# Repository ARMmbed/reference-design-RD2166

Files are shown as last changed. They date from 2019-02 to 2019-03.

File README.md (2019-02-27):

# RD2166 Introduction:

The RD2166 Reference Design is a Pelion Ready design based on the Quectel BG96 cellular module and the STM32L475 Microcontroller.

The reference design is a tested and proven starting point targetted towards the creation of both Development Boards and End Products.

# Reference Design Contents:
**Reference Schematic** 
This is the core of reference design, and illustrates where and how the essential components are connected. 

**Reference Application**
Built on mbedOS, and includes Pelion Device Manager. This application has been configured to run on the Reference Design hardware, and will connect to the Pelion Cloud, and is capable of running the cloud based update service.
Please refer to the [\Documentation\RD2166_Readme.md](https://github.com/ARMmbed/reference-design-RD2166/blob/master/Documentation/RD2166_README.md) for instructions on how to build & use this example application.

**Example Implementation** 
Based on the Reference Design, this example implementation is included to demonstrate the Reference Design being used to create real-world hardware. The example implemenation is used within Arm to include the Reference Design into the internal test infrastructure, it is comprised of three parts:

*MCB (Module Carrier Board)* - this has been designed using the Reference Design schematic. In this reference design, the MCB is a standalone STM32L475 MCU.

*MEB (Module Expansion Board)* - this has been designed using the Reference Design schematic. In this reference design, the MEB is a Quectel BG96 module.

*MTB (Module Test Bed)* - this is part of the test infrastructure, and includes DAPLink circuit for programming the device, a range of I/O and loopback paths for automated testing.

# Version Information:
		
| Release | mbed OS | mbed Cloud Client | Release Date | Comment |
| --- | --- | --- | --- | --- |
|v1.0 | 5.11.5	| 2.0.1.1	| 27/02/2019 | Initial Release
| |  |  | | 

Back to [Reference Designs](https://github.com/ARMmbed/reference-designs)

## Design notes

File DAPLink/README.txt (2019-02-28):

/*********************************
        DAPule
*********************************/

There are many flavours of DAPule available with different MCU's such as an LPC11U35, K20D, KL26Z and others.

For the purposes of this reference design, we have used an LPC11U35 based DAPule, schematics and design files 
for which have been shared in this directory.

Also, a binary file that was used for development of this RD2166 on the MTB (schematics and design files also
shared) is available for use.

For any issues, please use the RD2166's GitHub repo to report issues.

       ********** End of document *********

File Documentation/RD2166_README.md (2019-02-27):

# Reference Application Introduction:

This Reference Application is targetted specifically at the RD2166 Reference Design and is built on mbedOS and uses the "mbed-cloud-client" library to handle the Pelion Platform connection, registration and LWM2M resources. The application simulates a button press every 5 seconds and relays the packet to Arm Pelion IoT platform.

The current version of the Reference Application uses: Mbed OS v5.11.5 and Mbed Cloud Client v2.0.1.1

Note: references to Mbed Cloud and Pelion Device Managament are interchangeable.  For example: “Mbed Cloud Client enables the device to communicate with Pelion Device Management” and “Mbed Cloud Client enables the device to communicate with Mbed Cloud” have the same meaning.  In later versions we will remove references to Mbed Cloud inline with branding guidelines.

# Pre-requisites:
1. Hardware:
    * RD2166 based board or platform (the application was developed and tested using the Example Implemenation Hardware - MCB/MTB
    * A micro USB cable
    * A SIM card from your network provider with SIM details available for SIM PIN, APN, SIM username and SIM password.
    * For development purposes of this reference design, an EE network SIM card was used in the UK with the following parameters:

    ```
            "nsapi.default-cellular-sim-pin"       : "\"1234\"",
            "nsapi.default-cellular-apn"           : "\"everywhere\"",
            "nsapi.default-cellular-username"      : "\"myusername\"",
            "nsapi.default-cellular-password"      : "\"mypassword\"",
            "cellular.use-apn-lookup"              : false,
    ```

2. Software:
    * mbed CLI - https://github.com/ARMmbed/mbed-cli
    * Pelion account for API keys & developer certificate.

# Getting started:
1. Import this example to your local machine with mbed CLI:
    ``` mbed import https://github.com/ARMmbed/reference-design-RD2166.git ```

2. Move into the reference-design-RD2166 directory ``` cd reference-design-RD2166 ```. Run the ``` mbed deploy ``` command to download the sources and to add them to your current directory.
    * Login to your Pelion Cloud account on a browser & follow the steps below:
        * Navigate to Device identity > Certificates
        * Select the certificate created by your account admin and click on "Download Developer C file"
        * Save the file?mbed_cloud_dev_credentials.c to the location of the RD2166 directory. You have to overwrite the contents of the existing file there.

3. Configure your network credentials:
    * In the mbed_app.json file in the root of the application, modify the SIM PIN, APN and password for your network.
    * Save the changes.

4. The supplied Bootloader in ../bootloader/ is currently built to use SPI Flash. If you are using the SPI Flash to store the certificates, then you are good to go. If you prefer to use the SD card for the storage, follow the steps below. If not, you may skip these & move to step 11.
   
5. To build the bootloader to use the SD card:  (TIP: You may want to use atleast a Class 10, 2GB SD card.) This application currently uses v3.5.0 of the mbed-bootloader.
    * Import the bootloader repo - https://github.com/ARMmbed/mbed-bootloader
    * Change the default storage component in targets/targets.json file of Mbed OS.
    * Modify mbed_app.json in bootloader: Change update storage-address and remove SPI pin defines.  
    
```
    "update-client.storage-address"  : "(1024*1024*64)",  
```

And

    ```
    "MTB_STM_L475": {  
    "flash-start-address"              : "0x08000000",  
    "flash-size"                       : "(1024*1024)",  
    "nvstore.area_1_address"           : "(MBED_CONF_APP_FLASH_START_ADDRESS + 1016*1024)",
    "nvstore.area_1_size"              : "(4*1024)",
    "nvstore.area_2_address"           : "(MBED_CONF_APP_FLASH_START_ADDRESS + 1020*1024)",
    "nvstore.area_2_size"              : "(4*1024)",
    "update-client.application-details": "(MBED_CONF_APP_FLASH_START_ADDRESS+64*1024)",  
    "application-start-address"        : "(MBED_CONF_APP_FLASH_START_ADDRESS+65*1024)",  
    "max-application-size"             : "DEFAULT_MAX_APPLICATION_SIZE",   
    }
     ```
6. Change mbed_app.json in source:
 ```   "update-client.storage-address"  : "(1024*1024*64)",  ```
   
7. Once changes are made in bootloader, build it:
``` mbed compile -t GCC_ARM -m MTB_STM_L475 ```

8. Copy the generated binary to ../bootloader/ directory. Rename to match the existing file name. Or if you prefer to use a different file name, make sure that the ```            "target.bootloader_img"                : "bootloader/mbed-bootloader-extended.bin",``` in mbed_app.json in the RD2166's root directory matches the file name you have used.

9. Change mbed_app.json in the root of the reference application i.e. 
"update-client.storage-address"  : "(1024*1024*64)"

10. Change main.cpp in source to match SD card - i.e. un-comment the respective header include files in main.cpp to include the FileSystem specific headers while commenting out / removing the ones related to the SPI Flash (LittleFileSystem.h). This RD uses LittleFileSystem and SPI Flash. If you want to use FAT FS with SD card, then please un-comment the line to include the respective header

### IMPORTANT: The required lines are already supplied in the code. Uncomment appropriate lines in main.cpp and build the binary.

11. Once you are happy with changes(if any, for the SD card) or you are going with the provided default options, you may now proceed to compile the application binary with the command:
    ``` mbed compile -t GCC_ARM -m MTB_STM_L475 --profile=tiny.json```. 

12. Flash the generated binary (RD2166.bin) to your device. Open a serial terminal at 115200, 8-N-1 & observe the output.

13. The device starts the example, connects to the Cellular network & after a few moments connects & registers to Pelion Cloud. It then prints out a device ID. You will need this for firmware update at a later stage.

* You can now check your simulated button counter's value in the Pelion portal as well.
* Navigate to "Device Directory" in the portal and click on your device's device ID. This will open up a new drawer on the page.
* Scroll down to LWM2M resource "Button_count" and click on it.
* A new window opens and you will be able to see the counter & a graph increment every time the resource value increments.

14. Congratulations, your device is now connected to Pelion IoT platform. Please proceed to the FW update section now.

## Recommendation:  
Increase stack size:         "MBED_CONF_APP_MAIN_STACK_SIZE=6000", to 7K if using newer versions of Mbed OS  

# Demonstrate a remote Firmware update:

1. In order to update FW on a connected device, you will need the mbed CLI.

2. A dependency is to install the python SDK along with the manifest tool. This is done using : ``` pip install mbed-cloud-sdk --upgrade ```

3. Now you need to setup Mbed OS on the device to receive FW updates:
    * Login to your Pelion Cloud portal.
    * Create an API device key (Access Management -> API Keys -> Create a new API key)
    * Ensure you copy the API key generated as this is visible only once.
    
4. Initialize the certificates for your application:
## IMPORTANT: You must initialize the certificates before you flash the device for the 1st time as these certificates need to be embedded within the device in order for it to receive remote updates.

``` mbed dm init -a <api key> -S <mbed cloud API URL> -d <domain name> -m <model ID> --force ``` 

Where mbed cloud API URL is https://api.us-east-1.mbedcloud.com/  . The domain name must have a ".com" as a mandatory requirement and the model ID can be an integer of your choice.

### Note the use of --force as this option overrides the defaults provided in the application. This is a mandatory parameter.

5. With the certificates initialized, there will now be a ".update-certificates" directory created within the application's root directory.

6. Now, compile the application:
``` mbed compile -t GCC_ARM -m MTB_STM_L475 ```

7. Unless you made any changes to bootloader before this, you do not need to re-build the bootloader. Otherwise, please re-build the bootloader using steps described earlier and copy the new binary to the respective folder.

8. Program your device with the ``` RD2166.bin ``` just generated. You can either drag-drop via the GUI of your OS or you can use the corresponding copy command from the terminal for your OS.

9. Open a serial terminal application such as PuTTY and observe the output. You will notice the device boots up, connects to the Cellular network, starts Pelion Cloud Client and registers to the Cloud.

10. Once the device registers, make a note of the device ID assigned to the device.

11. Modify the main.cpp in the source directory to add a small printf statement - this is already provided in the code. So, you can un-comment this line in order to demo a FW update.

12. Compile the new source with ``` mbed compile -t GCC_ARM -m MTB_STM_L475 ``` command.

13. You will now have a new binary in the BUILD\MTB_STM_L475\GCC_ARM\ directory called "RD2166_update.bin"

14. Use the mbed CLI to perform a remote update on the device:

``` mbed dm update device -p <payload name> -D <device id> ``` 

where payload name is the full path to your new binary built from step 13 and device ID is the one obtained from step 10.

15. You will notice from the serial terminal that the device gets a request to update the FW, then this is authorized, then the download of the new FW starts, finishes and the bootloader verifies the authencity of the new FW, installs it on the device and reboots.

16. You will now notice the new printf statement appear on the device logs which indicates that the newly built application binary is now installed and running on the device i.e. the device has been remotely updated.

The success logs should look like this on a serial terminal, although your device *will* be assigned a different device ID and will have a different IP address.

```
PS C:\Ashok\Modules\Reference_Apps\Cellular\pelion-ready-example> mbed sterm -b 115200
[mbed] Detecting connected targets/boards to your system...
[mbed] Opening serial terminal to "MTB_STM_L475"
--- Terminal on COM89 - 115200,8,N,1 ---
[BOOT] Mbed Bootloader
[BOOT] ARM: 00000000000000000000
[BOOT] OEM: 00000000000000000000
[BOOT] Layout: 0 8009280
[BOOT] Active firmware integrity check:
[BOOT] [++++++++++++++++++++++++++++++++++++++++++++++++++++++++++++++++++++++]
[BOOT] SHA256: 3E213FC00FCC310F95CCB22FF574F48E65BD923B186F80C10BAC5B54A4EFFA88
[BOOT] Version: 1551179671
[BOOT] Slot 0 firmware is of older date
[BOOT] Version: 1550750045
[BOOT] Active firmware up-to-date
[BOOT] Application's start address: 0x8010400
[BOOT] Application's jump address: 0x8011071
[BOOT] Application's stack address: 0x20018000
[BOOT] Forwarding to application...
     Starting Simple Pelion Device Management Client example
Connecting to the network...
Connected to the network successfully. IP address: 100.120.93.161
Initialized Pelion Client. Registering...
Connected to Pelion Device Management. Endpoint Name: 01690fe6e310000000000001001002b2
Simulated button clicked 1 times
Simulated button clicked 2 times
Simulated button clicked 3 times
Simulated button clicked 4 times
Simulated button clicked 5 times
Simulated button clicked 6 times
Simulated button clicked 7 times
Simulated button clicked 8 times
Simulated button clicked 9 times
Simulated button clicked 10 times
Simulated button clicked 11 times
Firmware download requested
Authorization granted
Simulated button clicked 12 times
Downloading: [++++\                                             ] 8 %Simulated button clicked 13 times
Downloading: [+++++++++++/                                      ] 22 %Simulated button clicked 14 times
Downloading: [++++++++++++++-                                   ] 29 %Simulated button clicked 15 times
Downloading: [+++++++++++++++++++\                              ] 39 %Simulated button clicked 16 times
Downloading: [+++++++++++++++++++++++++/                        ] 50 %Simulated button clicked 17 times
Downloading: [++++++++++++++++++++++++++++++++\                 ] 65 %Simulated button clicked 18 times
Downloading: [++++++++++++++++++++++++++++++++++++++/           ] 77 %Simulated button clicked 19 times
Downloading: [+++++++++++++++++++++++++++++++++++++++++++++/    ] 91 %Simulated button clicked 20 times
Downloading: [++++++++++++++++++++++++++++++++++++++++++++++++++] 100 %
Download completed
Simulated button clicked 21 times
Firmware install requested
Authorization granted
[BOOT] Mbed Bootloader
[BOOT] ARM: 00000000000000000000
[BOOT] OEM: 00000000000000000000
[BOOT] Layout: 0 8009280
[BOOT] Active firmware integrity check:
[BOOT] [++++++++++++++++++++++++++++++++++++++++++++++++++++++++++++++++++++++]
[BOOT] SHA256: 3E213FC00FCC310F95CCB22FF574F48E65BD923B186F80C10BAC5B54A4EFFA88
[BOOT] Version: 1551179671
[BOOT] Slot 0 firmware integrity check:
[BOOT] [++++++++++++++++++++++++++++++++++++++++++++++++++++++++++++++++++++++]
[BOOT] SHA256: B9B086982B0542249C0223BE25AEE43EEBDC2A1251EA35E1DC634156D1C25B62
[BOOT] Version: 1551179857
[BOOT] Update active firmware using slot 0:
[BOOT] [++++++++++++++++++++++++++++++++++++++++++++++++++++++++++++++++++++++]
[BOOT] Verify new active firmware:
[BOOT] [++++++++++++++++++++++++++++++++++++++++++++++++++++++++++++++++++++++]
[BOOT] New active firmware is valid
[BOOT] Application's start address: 0x8010400
[BOOT] Application's jump address: 0x8011071
[BOOT] Application's stack address: 0x20018000
[BOOT] Forwarding to application...
?     Starting Simple Pelion Device Management Client example
Connecting to the network...
Connected to the network successfully. IP address: 10.185.222.179
******** This line demonstrates a FW update ********
Initialized Pelion Client. Registering...
Connected to Pelion Device Management. Endpoint Name: 01690fe6e310000000000001001002b2
Simulated button clicked 1 times
Simulated button clicked 2 times
Simulated button clicked 3 times
Simulated button clicked 4 times
Simulated button clicked 5 times
Simulated button clicked 6 times
Simulated button clicked 7 times
Simulated button clicked 8 times
Simulated button clicked 9 times
Simulated button clicked 10 times
Simulated button clicked 11 times
Simulated button clicked 12 times
Simulated button clicked 13 times
Simulated button clicked 14 times
```

#### Also note that the device ID remains the same after the FW update. This indicates that the SOTP regions were not over-written while perfoming the update.

#### Troubleshooting and FAQs:
1. Flow control on the MODEM: It is highly advisable to have dedicated hardware flow control pins between the MCU to the MODEM. This is required to enable cellular AT debug messages during development. If hwfc is not used, the packets received from the network are just too fast that may cause data corruption resulting in un-expected failures of Pelion Client.

2. SPI frequency: In this reference design, the SPI frequency for the SPI Flash is slowed down to 1MHz althought the MCU can handle upto 40MHz. This is becuase the XTAL used on the Module Carrier Board is an 8MHz resonator. Other higher frequencies are definitely supported by the SPI-flash driver in Mbed OS and will need appropriate modifications in the OS (system_clock.c) to match the frequencies used.

TIP: You can also use the MSI clock on the L475 series of MCUs to make use of higher frequencies for the SPI Flash if you prefer to use higher clocks.

3. Cellular access technology: The reference design uses High Speed Uplink/Downlink Packet Access technology. This is configurable in the mbed_app.json file in the root of the RD2166 under "radio-access-technology" parameter. Depending on your network, SIM card and your network provider's capabilities in your region, you can use any of the listed technologies to connect to the network.

4. TLS debug: There is a macro already provided in the RD2166's mbed_app.json to enable TLS debug messages if you need them. You can enable this by adding ```tls-debug:1``` under the "target_overrides" section. You can have values from 1-4 where 1 is the least amount of debug info and 4 is the max.

5. Mbed trace: If you need to enable debug messages, please toggle the "mbed-trace-enable" parameter in the mbed_app.json.

6. Currently, the BG96 driver in Mbed OS supports only AT mode. Hence "lwip.ppp-enabled" is "false".

7. Bootloader: The bootloader repository used to generate the bootloader binary in this RD is the https://github.com/ARMmbed/mbed-bootloader-extended . If any changes are required to the bootloader, please use this repository.

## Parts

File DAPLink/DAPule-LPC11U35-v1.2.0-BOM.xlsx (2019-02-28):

Qty | Value | Device | Package | Parts | Description | MF | MFN | OC-DIGIKEY | OC-MOUSER | OC-NEWARK
4 | 100nF | C0603 | 0603 | C1, C3, C4, C5 | Capacitor | Various | Various | 732-7989-1-ND | 710-885012206071 | 2392304
1 | 10uF | C0603 | 0603 | C2 | Capacitor | Various | Various | 490-3298-1-ND | 710-885012106006 | 498737
4 | 18pF | C0603 | 0603 | C6, C7, C8, C9 | Capacitor | Various | Various | 311-3889-1-ND | 603-CC603FRNPO9BN180 | 2310578
1 | USB_MICROB | USB_MICROB | MOLEX-47364-0001 | CON1 | USB Connectors | Molex | 47346-0001 | WM17141CT-ND | 538-47346-0001 | 1568026
2 | SWD-10/TC2050_SMD | SWD-10/TC2050_SMD | FTSH-105-02 | CON2, CON3 | 1mm pitch 10-Pin Cortex Programming Header | Samtec | FTSH-105-01-F-DV | SAM8795-ND | 200-FTSH10501FDV | 2856428
1 | BAT60J | BAT60J | SOD323 | D1 | SCHOTTKY DIODE | STMicroelectronics | BAT60JFILM | 497-3707-6-ND | 511-BAT60JFILM | 89K1218
1 | USBLC6-2SC6 | USBLC6-2SC6 | SOT23-6L | IC1 | usb Transient Voltage Suppressor | ST | USBLC6-2SC6 | 497-5235-1-ND | 511-USBLC6-2SC6 | 1269406
1 | LD1117S33 | LD1117S33 | SOT223 | IC2 | VOLTAGE REGULATOR SMD 3,3V | Various | LD1117S33 | 296-28778-1-ND | 595-TLV1117LV33DCYR | 2323647
1 | LPC11U35FHI33/501 | LPC11U35FHI33/501 | SOT617-3 | IC3 | 32-bit ARM Cortex-M0 microcontroller | NXP | LPC11U35FHI33/501 | 568-9586-ND | 771-LPC11U35FHI33501 | 2115658
1 | PWR_OFF | PINHD-1X2 | 1X02 | J2 | PIN HEADER | Wurth | 61300211121 | 732-5315-ND | 710-61300211121 | 2356153
1 | RED | LED0603 | CHIPLED_0603 | LED1 | SMD LED | Wurth | 150060RS75000 | 732-4978-1-ND | 710-150060RS75000 | 2322071
1 | GREEN | LED0603 | CHIPLED_0603 | LED3 | SMD LED | Wurth | 150060GS75000 | 732-4971-1-ND | 710-150060GS75000 | 2322070
1 | BLUE | LED0603 | CHIPLED_0603 | LED2 | SMD LED | Wurth | 150060BS75000 | 732-4966-1-ND | 710-150060BS75000 | 2322069
1 | 12MHz | Q_3.2X2.5 | 3.2X.2.5 | Q1 | Crystal, 12MHz | Abracon | ABM8G-12.000MHZ-4Y-T3 | 535-10901-1-ND | 815-ABM8G-12-4YT3 | 2467837
3 | 470R | R0603 | 0603 | R1, R2, R3 | Resistor, 0603 | Various | Various | 311-470GRCT-ND | 603-RC0603JR-07470RL
1 | 1k | R0603 | 0603 | R13 | Resistor, 0603 | Various | Various | 311-1.0KGRCT-ND | 603-RC0603JR-071KL | 2447272
1 | 0R@DNF | R0402 | 0603 | R4 | Resistor, 0402 | Various | Various | 311-0.0JRCT-ND | 603-RC0402JR-070RL | 1174140
4 | 10k | R0603 | 0603 | R5, R6, R12, R14 | Resistor, 0603 | Various | Various | 311-10KGRCT-ND | 603-RC0603JR-0710KL | 2447230
4 | 33R | R0603 | 0603 | R7, R8, R10, R11 | Resistor, 0603 | Various | Various | 311-33GRCT-ND | 603-RC0603JR-0733RL | 2446661
1 | 1k5 | R0603 | 0603 | R9 | Resistor, 0603 | Various | Various | 311-1.5KGRCT-ND | 603-RC0603JR-071K5L | N/A
1 | SKRKAEE010 | SKRKAEE010 | SKRKAEE010 | SW1 | MOMENTARY SWITCH PUSH VERTICAL (SPST) | ALPS | SKRKAEE010 | N/A | 688-SKRKAE | N/A
1 | BSS84 | BSS84 | SOT23 | T1 | P-CHANNEL MOS FET | Various | BSS84 | BSS84-FDICT-ND | 512-BSS84 | 1510765
1 | PMF170XP_SOT323 | PMF170XP_SOT323 | SOT323-BEC | T2 | P-CHANNEL MOS FET | NEXPERIA | PMF170XP,115 | 1727-1229-1-ND | 771-PMF170XP115 | 2069557
1 | BC850C,215 | BC850C,215 | SOT23-3 | T3 | BJT NPN | NXP Semiconductors | BC850C,215 | 568-6077-1-ND | 771-BC850C-T/R | 75R0745

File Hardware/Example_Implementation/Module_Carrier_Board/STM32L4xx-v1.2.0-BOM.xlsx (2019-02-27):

Qty | Value | Device | Package | Parts | Description | MF | MFN | OC-DIGIKEY | OC-MOUSER | OC-NEWARK
5 | 100nF | C0402 | 0402 | C18, C19, C20, C21, C22 | Capacitor |  |  | 732-7495-1-ND | 710-885012105018 | 2495146
1 | 10k | R0402 | 0402 | R12 | Resistor |  |  | 311-10kJRCT-ND | 603-RC0402JR-0710KL | 2446413
1 | 1k | R0603 | 0603 | R15 | Resistor |  |  | 311-1.0KGRCT-ND | 603-RC0603JR-071KL | 2447272
2 | 22pF | C0603 | 0603 | C16, C17 | Capacitor |  |  | 732-7748-1-ND | 710-885012006004 | 2533823
1 | 32.768kHz | GENERIC-CRYSTAL_FC135 | FC135 | Q3 | GENERIC Crystal |  |  | 535-9543-2-ND | 815-ABS07-32.768K7T | 1838935
4 | 4k7 | RESISTOR0402 | 0402 | R1, R2, R13, R14 | Resistor |  |  | 311-4.7kGRCT-ND | 603-RC0603JR-074K7L | 2446702
1 | ATECC608A | ATECC608A | SO8 | IC4 |  |  |  | ATECC608A-SSHDA-TCT-ND | 556-ATECC608ASSHDAB | not stocked
1 | CSTCE8M00G55-R0 | CSTCE8M00G55-R0 | CSTCE8M00G55-R0 | Q1 | Resonator Cermanic, Murata 8MHz 33pF | Murata | CSTCE8M00G55-R0 | 490-17958-1-ND | 81-CSTNE8M00G550000R
1 | GREEN | SMD_LED0603 | CHIPLED_0603 | LED1 | LED SMD, Colour Red | Wurth Electronics Inc | 150060RS75000 | 732-4978-1-ND | 710-150060RS75000 | 2322071
1 | MX25R3235FM1IH0 | MX25R3235FM1IH0 | SO8 | U2 | Serial Flash 32 Mb 80 Mhz | Macronix | MX25R3235FM1IH0 | 1092-1175-ND
1 | STM32L475VGT6 | STM32L475VGT6 | QFP50P1600X1600X160-100N | U1 | Cortex-M4 Microcontroller | ST | STM32L476VGT6 | 497-16391-ND | 511-STM32L475VGT6 | 2851026

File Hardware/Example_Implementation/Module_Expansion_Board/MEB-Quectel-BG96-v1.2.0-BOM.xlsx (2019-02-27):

Qty | Value | Device | Package | Parts | Description | MF | MFN | OC-DIGIKEY | OC-MOUSER | OC_FARNELL | OC_NEWARK
4 | 0R | R0603 | 0603 | R1, R2, R3, R14 | Resistor |  |  | 311-0.0GRCT-ND | 603-RC0603JR-070RL
1 | 100k@1% | R0603 | 0603 | R4 | Resistor |  |  | 311-100KGRCT-ND | 603-RC0603JR-07100KL
7 | 100nF | C0603 | 0603 | C5, C9, C11, C12, C19, C20, C24 | Capacitor |  |  | 732-7989-1-ND | 710-885012206071 | 2392304
2 | 100uF | C-POLA | SMC_A | C6, C10 | Polarised capacitor |  |  | 478-8152-1-ND | 74-TMCMA0J107MTRF | 2429372
2 | 10nF | C0603 | 0603 | C17, C22 | Capacitor |  |  | 445-5100-2-ND | 710-885012206065 | 2525109
2 | 10pF | C0603 | 0603 | C3, C7 | Capacitor |  |  | 732-7793-1-ND | 710-885012006051 | 2495133
1 | 1k | R0603 | 0603 | R24 | Resistor |  |  | 311-1.0KGRCT-ND | 603-RC0603JR-071KL | 2447272
3 | 22R | R0603 | 0603 | R19, R20, R21 | Resistor |  |  | P22.0HCT-ND | 667-ERJ-1GNF22R0C | 2302291
2 | 2k2 | R0603 | 0603 | R13, R15 | Resistor |  |  | 311-2.2KGRCT-ND | 603-RC0603JR-072K2L
5 | 33pF | C0603 | 0603 | C4, C8, C18, C21, C23 | Capacitor |  |  | 311-1468-1-ND | CC0603JRNPO0BN330 | 2524942
1 | 470R | R0603 | 0603 | R6 | Resistor |  |  | 311-470GRCT-ND | 603-RC0603JR-07470RL
2 | 470uF | CPOL-EU150CLZ-0810 | 150CLZ-0810 | C13, C14 | POLARIZED CAPACITOR, European symbol |  |  | WM17141CT-ND | 538-47346-0001 | 1568026
1 | 47346-0001 | 47346-0001 | USB-MICRO-B-H | CON2 | USB Receptacle Horizontal Micro Type B | MOLEX | 47346-0001 | WM17141CT-ND | 538-47346-0001 | 1568026 | 1568026
4 | 47k@1% | R0603 | 0603 | R5, R8, R10, R12 | Resistor |  |  | 311-47kGRCT-ND | 603-RC0603JR-0747KL
3 | 4k7 | R0603 | 0603 | R7, R9, R11 | Resistor |  |  | 311-4.7kGRCT-ND | 603-RC0603JR-074K7L | 2446702
2 | 51k | R0603 | 0603 | R22, R23 | Resistor |  |  | 311-51KNCT-ND | 603-RC0201JR-0751KL | 2059471
1 | 5v1 | DIODE-ZENER | SOD123 | D1 |  |  |  | BZT52C5V1-E3-08CT-ND | 78-BZT52C5V1-E3-08 | 2690025
1 | 74AHC1G08DCK | 74AHC1G08DCK | SC70-5 | IC2 | 2-input AND gate |  |  | 296-11604-1-ND | 595-SN74LVC1G125DCKR | 1470768
3 | BC850C,215 | BC850C,215 | SOT23-3 | T1, T2, T3 | BJT NPN | NXP Semiconductors | BC850C,215 | 568-6077-1-ND | 771-BC850C-T/R |  | 75R0745
1 | BG96 | BG96 | LTE_MODULE_BG96 | MOD1 | Lte Cat.M1 Module For Global Sku | Quectel
4 | DNF | C0603 | 0603 | C1, C2, C15, C16 | Capacitor
1 | FC68148S | FC68148S | FC68148S | CON3 | Power Jack | Cliff | FC68148S |  |  | 1889309
2 | GREEN | LED0603 | CHIPLED_0603 | LED1, LED4 | LED SMD |  |  | 732-4971-1-ND | 710-150060GS75000 | 2322070
1 | MIC29302WU | MIC29302WU | TO263-5 | IC1 |  | Microchip |  | 576-1125-1-ND | 998-MIC29302WUTR | 2510027
1 | RED | LED0603 | CHIPLED_0603 | LED2 | LED SMD |  |  | 732-4978-1-ND | 710-150060RS75000 | 2322071
1 | SF56S006V4BR2000 | SF56S006V4BR2000 | JAE_SF56S006V4BR2000 | J1 | CONN MICRO SIM CARD PUSH-PUSH | JAE Electronics |  | 670-2834-1-ND
2 | SMA-142-0701-801/806 | SMA-142-0701-801/806 | J502-ND-142-0701-801/806 | CON1, CON4 | SMA 50 Ohm End Launch Jack Receptacle | JOHNSON COMPONENTS |  | J502-ND | 530-142-0701-801 | 1608592 | 90F2624
1 | TXS0108EPWR | TXS0108EPWR | TSSOP-20 | U1 | 8-Bit Bi-directional, Level-Shifting | Texas Instruments | TXS0108EPWR | 296-23011-1-ND | 595-TXS0108EPWR | 1702548 | 05R8300
1 | USBLC6-2SC6 | USBLC6-2SC6 | SOT23-6L | U2 | 2 line Transient voltage suppressor | STMicro | USBLC6-2SC6Y | 497-5235-1-ND | 511-USBLC6-2SC6 | 1269406 | 2629711

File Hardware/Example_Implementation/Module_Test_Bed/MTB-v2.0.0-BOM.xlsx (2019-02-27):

Qty | Value | Device | Package | Parts | Description | MF | MFN | OC-DIGIKEY | OC-MOUSER | OC-NEWARK | Column1
1 |  | JP2E | JP2 | JP1 | JUMPER
1 |  | PINHD-1X2 | 1X02 | JP3 | PIN HEADER
1 |  | PINHD-2X3 | 2X03 | JP4 | PIN HEADER
6 | 0R | R0603 | 0603 | R22, R6, R7, R18, R23, R24
14 | 100nF | C0603 | 0603 | C1, C3, C4, C10, C11, C12, C13, C14, C15, C16, C17, C18, C19, C20 | Capacitor
8 | 10k | R0603 | 0603 | R16, R1, R2, R19, R20, R21, R27, R29
1 | 10uF | C-POLA | SMC_A | C5 | Polarised capacitor
1 | 10uF | C-POLB | SMC_B | C2 | Polarised capacitor
1 | 1R@1% | R0603 | 0603 | R3 | Resistor
5 | 1k | R0603 | 0603 | R8,R11, R12, R13, R26
1 | 220R | R0603 | 0603 | R17
4 | 4k7 | R0603 | 0603 | R14, R15, R4, R5
1 | AT24C256C-SSHL | AT24C256C-SSHL | SO8 | IC5 | I2C EEPROM, 24LC family
2 | BAT60J | BAT60J | SOD323 | D2, D3 | SCHOTTKY DIODE | Infineon | BAT60AE6327HTSA1 | BAT60AE6327HTSA1CT-ND | 726-BAT60AE6327 | 85X4127
1 | BC850 | BC850 | SOT23 | T2 | NPN TRANSISTOR
1 | BLUE | LED0603 | CHIPLED_0603 | LED5 | SMD LED
1 | C12832A1Z | C12832A1Z | C12832A1Z | LCD1
1 | DAPULE | DAPULE | DAPULE | MOD1 |  | Samtec | SSW-107-01-G-D |  |  | 1668358
1 | FC68148S | FC68148S | FC68148S | CON12 | Power Jack
1 | GREEN | SMD_LED0603 | CHIPLED_0603 | LED1,LED6 | LED SMD, Colour Red | Wurth Electronics Inc | 150060RS75000 | 732-4978-1-ND | 710-150060RS75000 | 2322071
2 | GROVE-A/D-PTH | GROVE-A/D-PTH | HW4-2.0 | CON3, CON4
2 | GROVE-SPI-PTH | GROVE-SPI-PTH | HW4-2.0 | CON1, CON7
4 | GROVE-UART-I2C-PTH | GROVE-UART-I2C-PTH | HW4-2.0 | CON2, CON5, CON6, CON8
1 | INA219AIDCNR | INA219AIDCNR | SOT23-8 | U5 | Current Sense - I2C | Texas Instruments | INA219AIDCNR | 296-23770-1-ND | 595-INA219AIDCNR | 2295989
1 | ISKRA_PNZ | ISKRA_PNZ | CA14V | VR1
1 | JS202011JCQN | JS202011JCQN | JS202011JCQN | SW3 | SLIDE TOGGLE SWITCH VERTICAL (DPDT) | C&K Components | JS202011JCQN | CKN10723CT-ND | 611-JS202011JCQN
1 | LD1117S33 | LD1117S33 | SOT223 | IC2 | VOLTAGE REGULATOR SMD 3,3V
1 | LM75BD_TSSOP8 | LM75BD_TSSOP8 | TSSOP8 | IC4
1 | MICRO-SD | MICRO-SD | AMPHENOL-101-00660-68-6 | CON10
2 | MODULE_SOCKET | MODULE_SOCKET | MODULE_SOCKET | 2x20 way headers |  | Samtec | SSW-110-01-G-D |  |  | 1668373
1 | P-FET_PMF170XP | P-FET_PMF170XP | SOT23-BEC | T3
1 | RED | LED0603 | CHIPLED_0603 | LED4 | SMD LED
1 | SPST-4_TP1154_J | SPST-4_TP1154_J | TP-1154X | SW2

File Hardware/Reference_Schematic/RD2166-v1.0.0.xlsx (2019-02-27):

Qty | Value | Device | Package | Parts | Description | MF | MFN | OC-DIGIKEY | MOUSER-OC | OC_FARNELL
1 | ATECC608A | ATECC608A | SO8 | U3 | Secure Element |  |  | ATECC608A-SSHDA-TCT-ND | 556-ATECC608ASSHDAB | not stocked
3 | BC850C,215 | BC850C,215 | SOT23-3 | T1, T2, T3 | BJT NPN | NXP Semiconductors | BC850C,215 | 568-6077-1-ND | 771-BC850C-T/R | 75R0745
1 | BG96 | BG96 | LTE_MODULE_BG96 | MOD1 | Lte Cat.M1 Module For Global Sku | Quectel | BG96 | not stocked | not stocked | not stocked
2 | 10nF | C0603 | 0603 | C20, C25 | Capacitor |  |  | 445-5100-2-ND | 710-885012206065 | 2525109
2 | 10pF | C0603 | 0603 | C12, C13 | Capacitor |  |  | 732-7793-1-ND | 710-885012006051 | 2495133
2 | 22pF | C0603 | 0603 | C3, C5 | Capacitor |  |  | 732-7748-1-ND | 710-885012006004 | 2533823
5 | 33pF | C0603 | 0603 | C14, C15, C28, C29, C30 | Capacitor |  |  | 311-1468-1-ND | CC0603JRNPO0BN330 | 2524942
11 | 100nF | C0603 | 0603 | C1, C2, C4, C6, C7, C8, C11, C16, C17, C26, C27 | Capacitor |  |  | 732-7989-1-ND | 710-885012206071 | 2392304
2 | 470uF | C-POL_G | PANASONIC_G | C9, C10 | Polarised capacitor |  |  | 493-2181-1-ND | 647-UWT1C471MNL1S | 2112869
2 | 100uF | C-POLA | SMC_A | C18, C19 | Polarised capacitor |  |  | 478-8152-1-ND | 74-TMCMA0J107MTRF | 2429372
1 | CSTCE8M00G55-R0 | CSTCE8M00G55-R0 | CSTCE8M00G55-R0 | Q2 | Resonator Cermanic, Murata 8MHz 33pF | Murata | CSTCE8M00G55-R0 | 490-1195-1-ND | 81-CSTCE8M00G55-R0 | 2443270
1 | 5v1 | DIODE-ZENER | SOD123 | D1 | Zener Diode |  |  | BZT52C5V1-E3-08CT-ND | 78-BZT52C5V1-E3-08 | 2690025
1 | FC68148S | FC68148S | FC68148S | CON2 | Power Jack | Cliff | FC68148S | not stocked | not stocked | 1889309
1 | 32.768kHz | GENERIC-CRYSTAL_FC135 | FC135 | Q1 | GENERIC Crystal | Abracon | ABS07-32.768KHZ-T | 535-9543-2-ND | 815-ABS07-32.768K7T | 1838935
1 | GREEN | LED0603 | CHIPLED_0603 | LED2 | LED SMD | Wurth | 150060GS75000 | 732-4971-1-ND | 710-150060GS75000 | 2322070
1 | RED | LED0603 | CHIPLED_0603 | LED1 | LED SMD | Wurth | 150060RS75000 | 732-4978-1-ND | 710-150060RS75000 | 2322071
1 | MIC29302WU | MIC29302WU | TO263-5 | IC1 | MIC29302 Series 3 A 1.24 to 26 V ADJ Output Voltage LDO Regulator - TO-263-5 | Microchip | MIC29302WU | 576-1125-1-ND | 998-MIC29302WUTR | 2510027
1 | MX25R3235FM1IH0 | MX25R3235FM1IH0 | SO8 | U2 | Serial Flash 32 Mb 80 Mhz | Macronix | MX25R3235FM1IH0 | 1092-1175-ND | not stocked | not stocked
1 | 100k@1% | R0603 | 0603 | R6 | Resistor |  |  | 311-100KGRCT-ND | 603-RC0603JR-07100KL | No Data
1 | 10k | R0603 | 0603 | R5 | Resistor |  |  | 311-10KGRCT-ND | 603-RC0603JR-0710KL | 2447230
1 | 470R | R0603 | 0603 | R8 | Resistor |  |  | 311-470GRCT-ND | 603-RC0603JR-07470RL | No Data
2 | 2k2 | R0603 | 0603 | R17, R20 | Resistor |  |  | 311-2.2KGRCT-ND | 603-RC0603JR-072K2L | No Data
2 | 51k | R0603 | 0603 | R24, R25 | Resistor |  |  | 311-51KNCT-ND | 603-RC0201JR-0751KL | 2059471
3 | 22R | R0603 | 0603 | R21, R22, R23 | Resistor |  |  | P22.0HCT-ND | 667-ERJ-1GNF22R0C | 2302291
4 | 0R | R0603 | 0603 | R9, R10, R13, R14 | Resistor |  |  | 311-0.0GRCT-ND | 603-RC0603JR-070RL | No Data
4 | 47k | R0603 | 0603 | R7, R12, R16, R19 | Resistor |  |  | 311-47kGRCT-ND | 603-RC0603JR-0747KL | No Data
7 | 4k7 | R0603 | 0603 | R1, R2, R3, R4, R11, R15, R18 | Resistor |  |  | 311-4.7kGRCT-ND | 603-RC0603JR-074K7L | 2446702
1 | SF56S006V4BR2000 | SF56S006V4BR2000 | JAE_SF56S006V4BR2000 | J1 | SF56 series, micro-SIM card connector, push-push type, normal closed | JAE Electronics | SF56S006V4BR2000 | 670-2834-1-ND | 656-SF56S006V4BR2000 | not stocked
2 | SMA-142-0701-801/806 | SMA-142-0701-801/806 | J502-ND-142-0701-801/806 | CON3, CON4 | SMA 50 Ohm End Launch Jack Receptacle - Round Contact | JOHNSON COMPONENTS | 142-0701-801 | J502-ND | 530-142-0701-801 | 1608592
1 | STM32L475VGT6 | STM32L475VGT6 | QFP50P1600X1600X160-100N | U1 | Cortex-M4 MCU |  |  | 497-16391-ND | 511-STM32L475VGT6 | 2851026
1 | TXS0108EPWR | TXS0108EPWR | TSSOP-20 | U4 | 8-Bit Bi-directional, Level-Shifting, Voltage Translator | Texas Instruments | TXS0108EPWR | 296-23011-1-ND | 595-TXS0108EPWR | not stocked

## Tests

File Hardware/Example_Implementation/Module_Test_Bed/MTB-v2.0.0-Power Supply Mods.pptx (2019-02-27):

## Removing 1R shunt

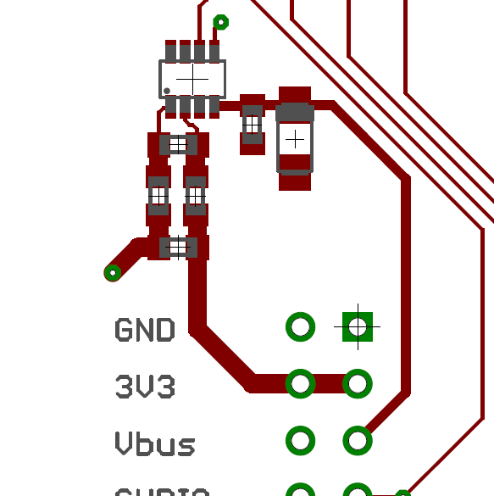
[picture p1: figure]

Either remove the 1R resistor, and then solder across the pads..
OR
Just keep applying solder across the top of the resistor so it becomes one big blob of short circuit!

## DC Jack Current path

Physical switch, before the power goes into the power plane.

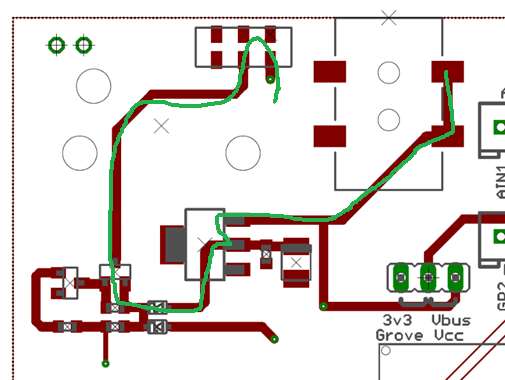
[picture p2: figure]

Conclusion
a fairly long path, with some potentially limiting components in it.

BAT60 low-Vf diode, and a PMF170 P-FET. Need to look at their current rating

3v3 from the DAPule merged in through a BAT60

Through an LDO, rated at 800mA.. Same as on the DAPule

## Modifying DC Jack Current path

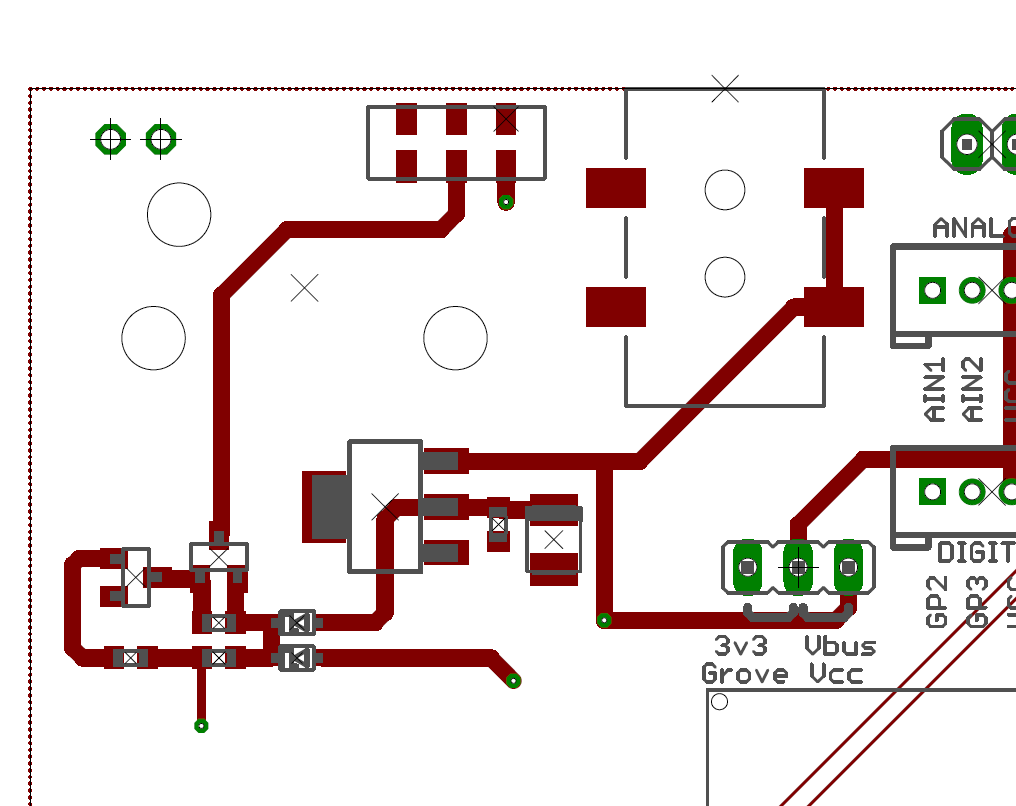
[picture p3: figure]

1. Cut the path to the switch
2. Strap directly from the DC connector the switch
3. For the love of god, please use a power supply regulated at 3v3

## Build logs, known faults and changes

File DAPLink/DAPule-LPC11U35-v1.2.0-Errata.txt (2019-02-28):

Errata for DAPLule-LPC11U35-v1.2.0

- The 3v3_IF net is also connected to the TAB of the LD1117S33 LDO regulator, thereby bypassing the switch. IN future revisions this needs to be changed, but for now a single track cut will sole the issue

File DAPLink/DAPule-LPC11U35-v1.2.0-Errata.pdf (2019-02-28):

Cut the thick trace on the top layer between the LDO and the via

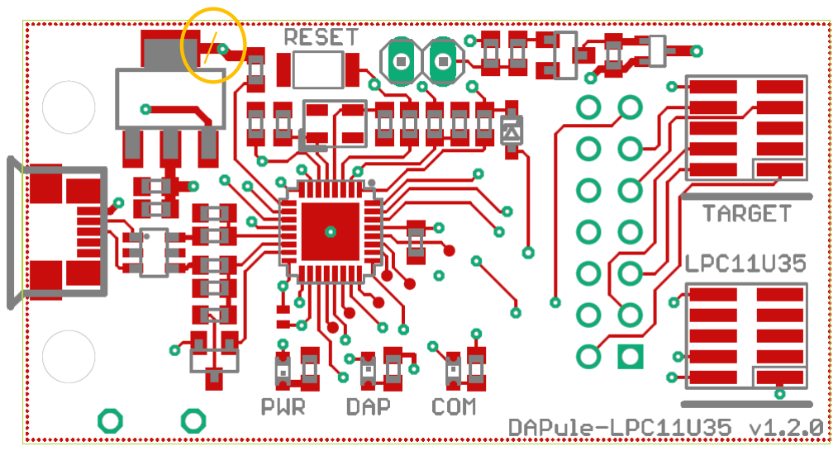
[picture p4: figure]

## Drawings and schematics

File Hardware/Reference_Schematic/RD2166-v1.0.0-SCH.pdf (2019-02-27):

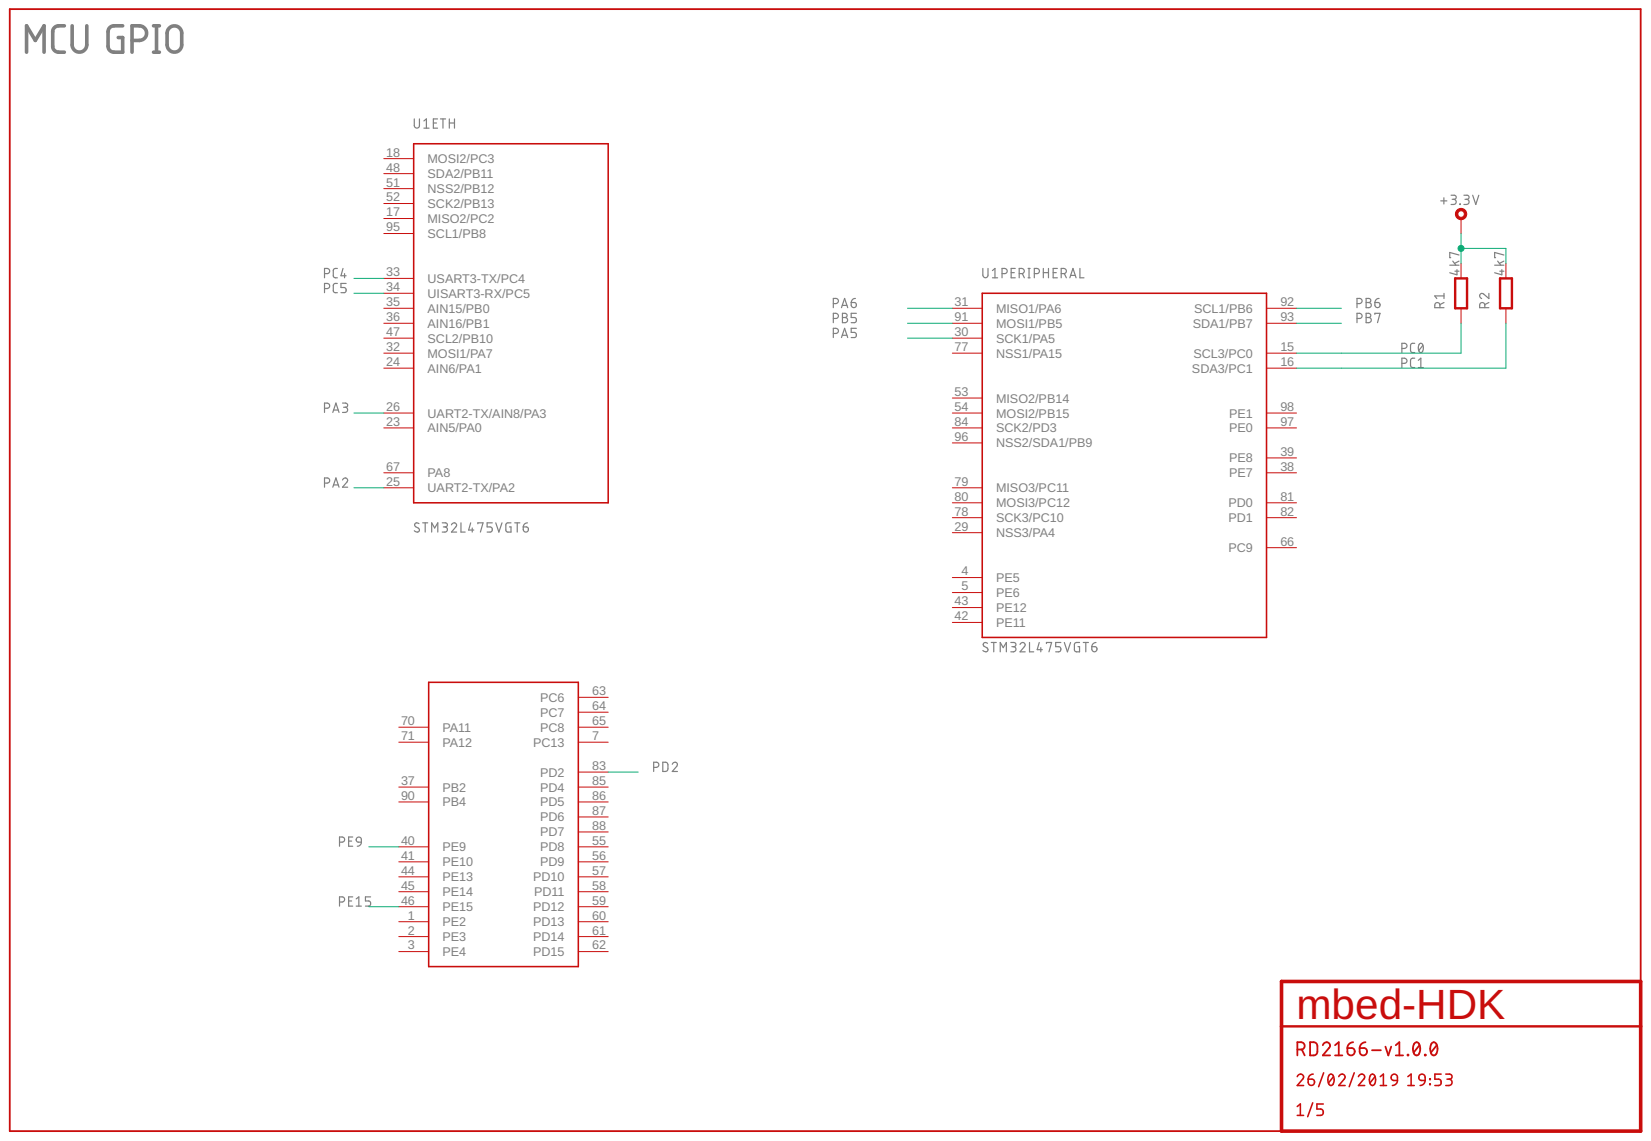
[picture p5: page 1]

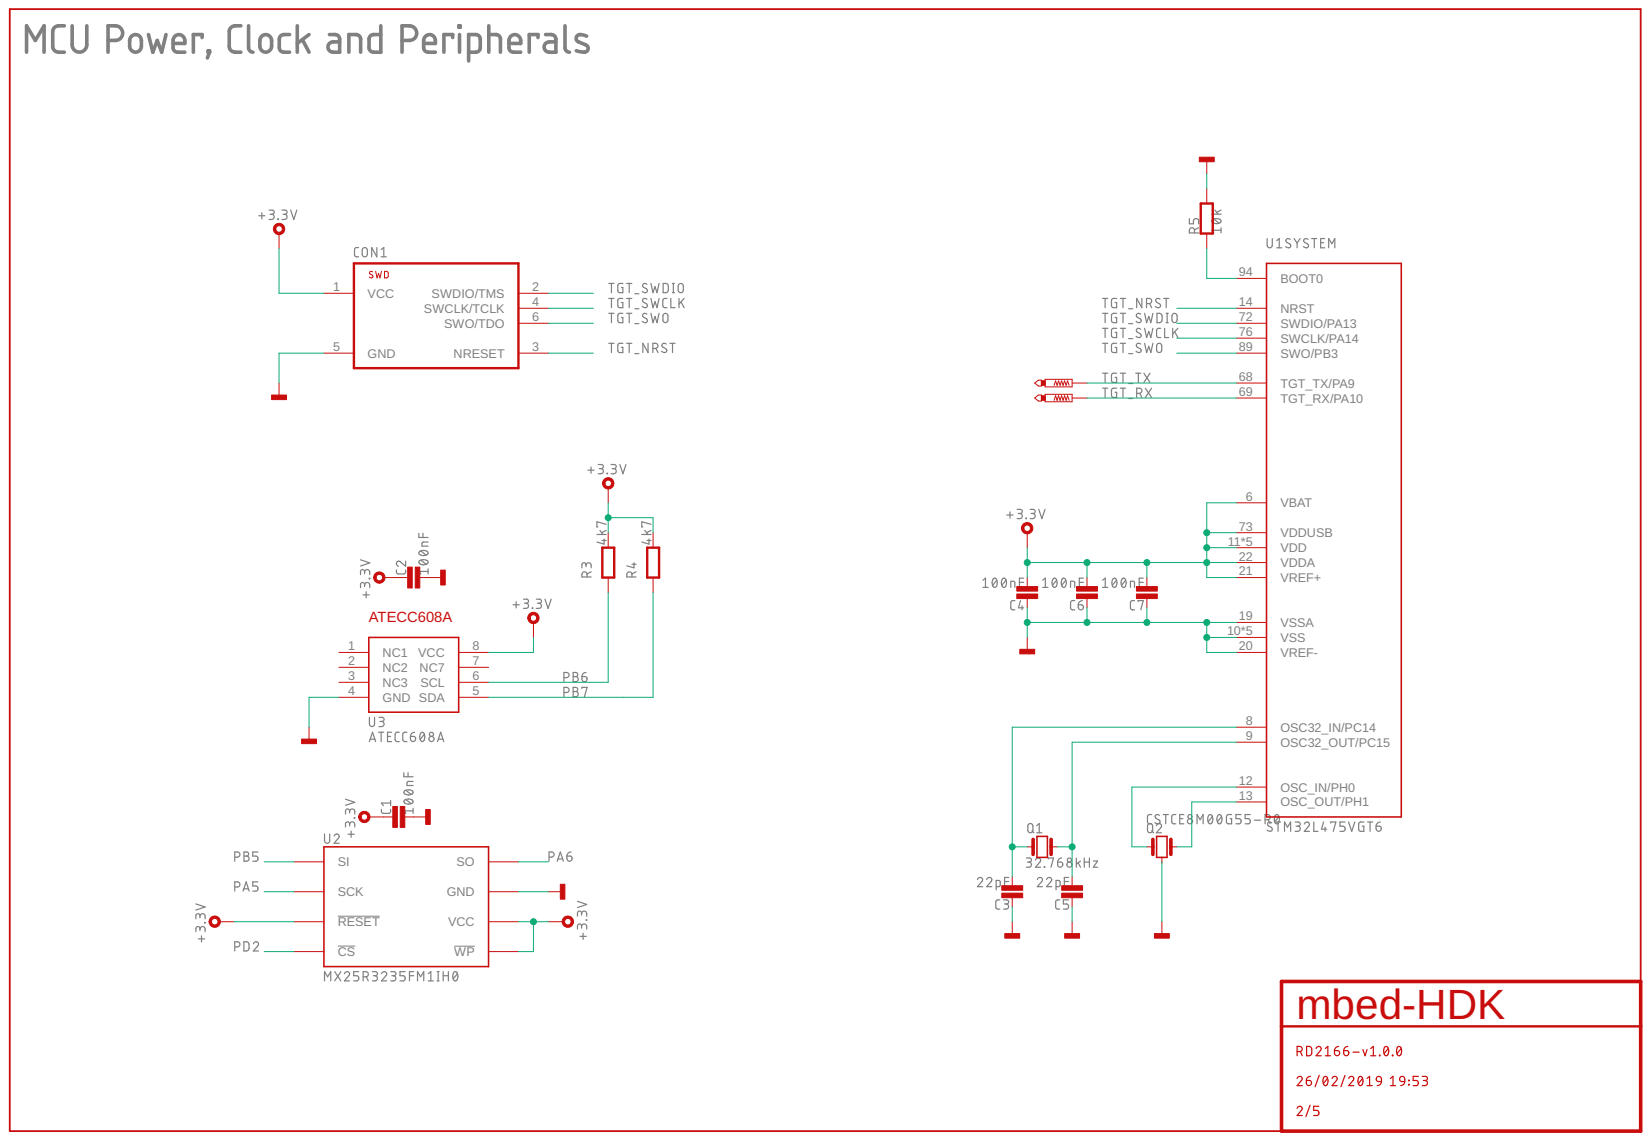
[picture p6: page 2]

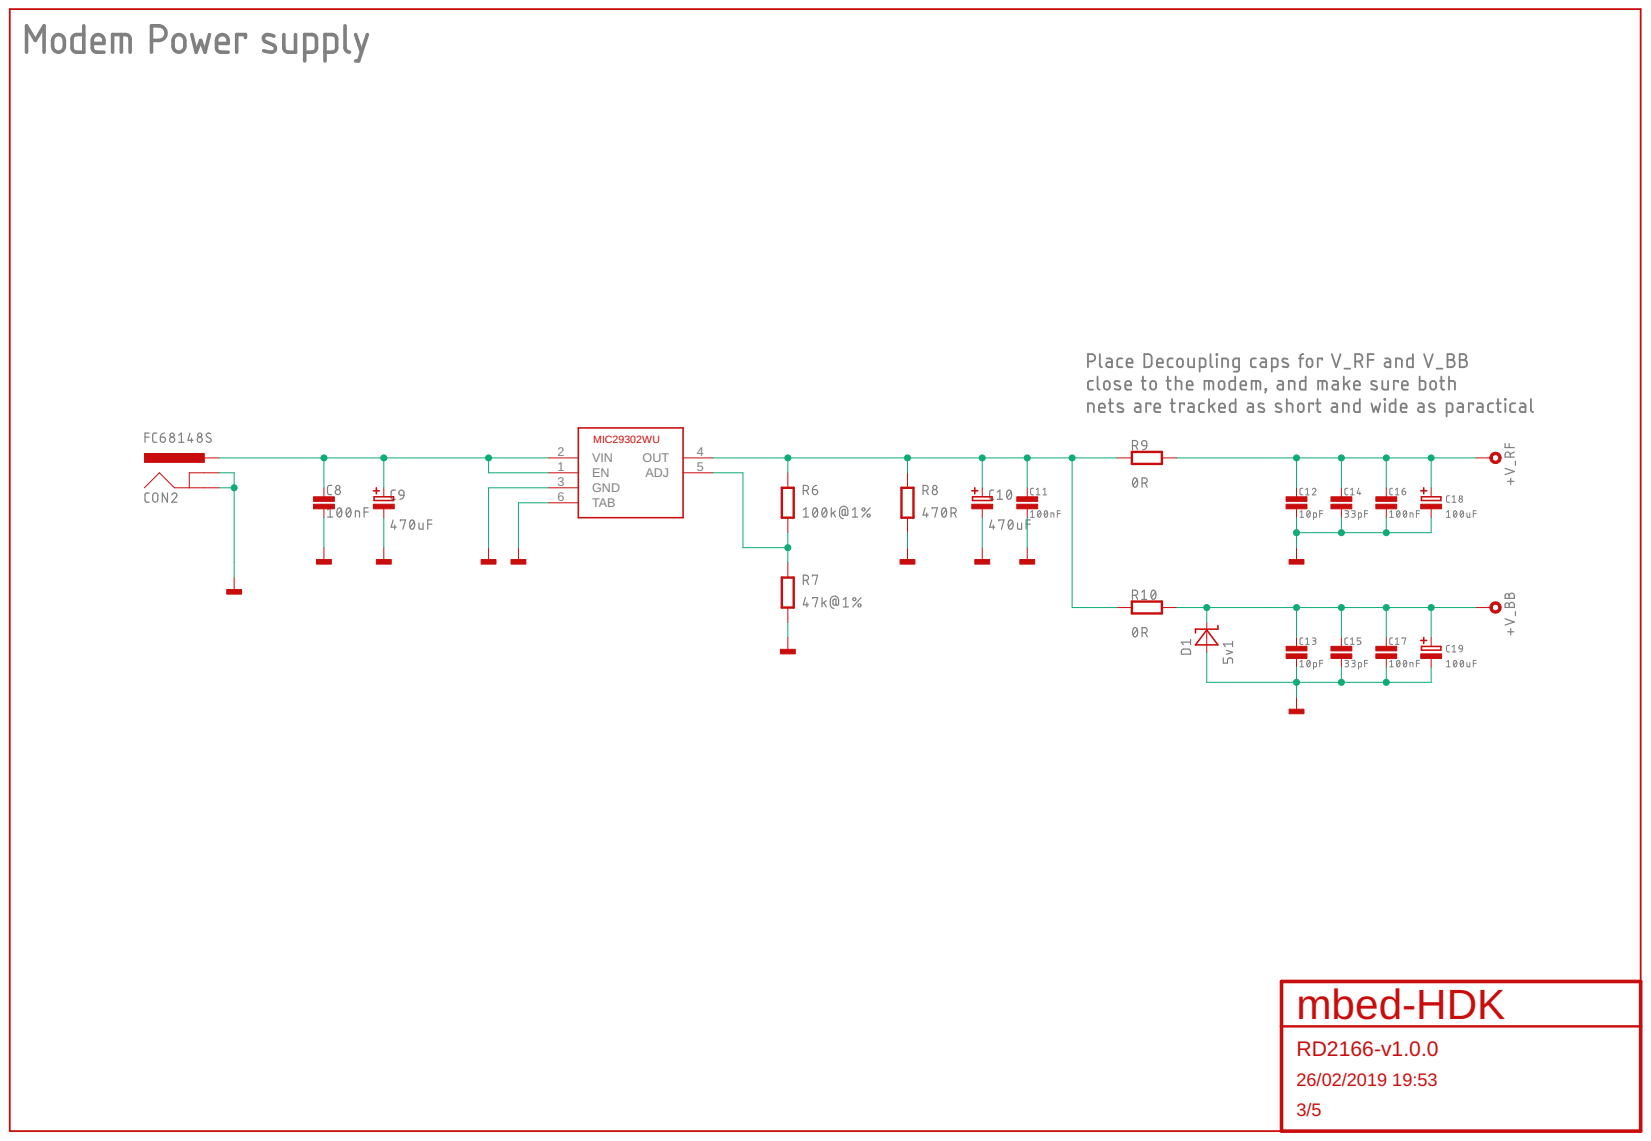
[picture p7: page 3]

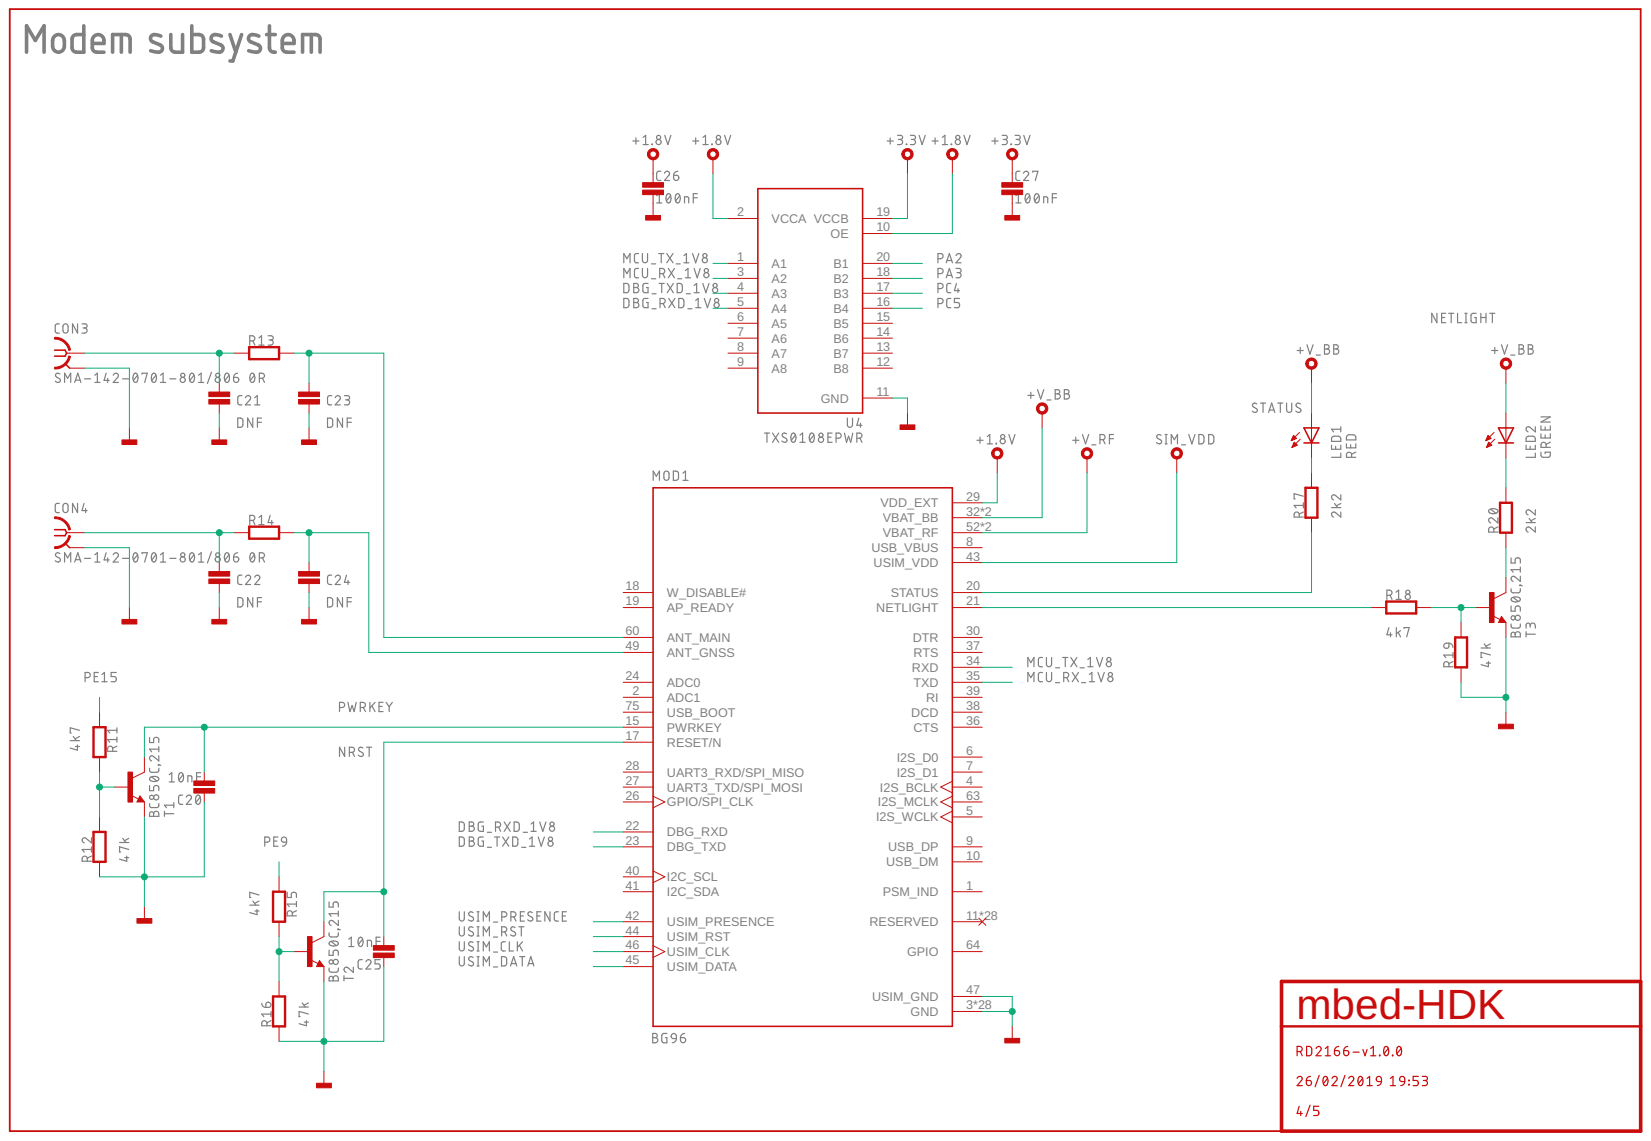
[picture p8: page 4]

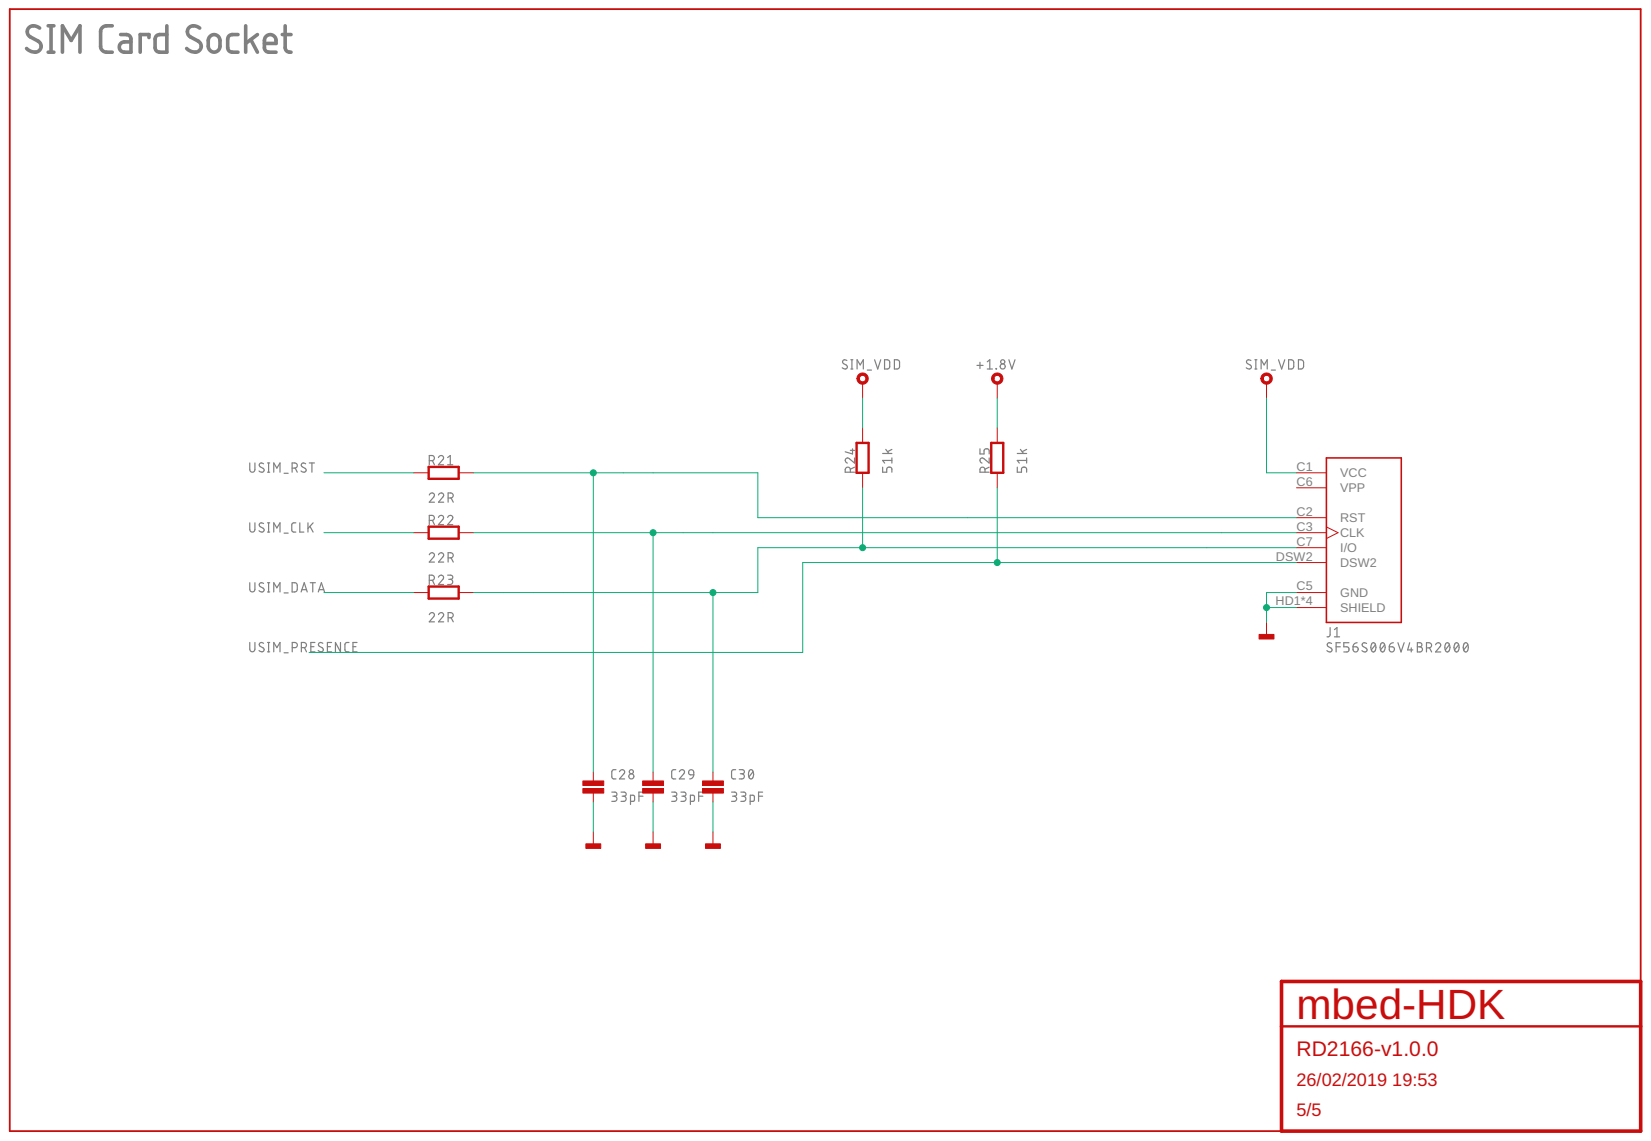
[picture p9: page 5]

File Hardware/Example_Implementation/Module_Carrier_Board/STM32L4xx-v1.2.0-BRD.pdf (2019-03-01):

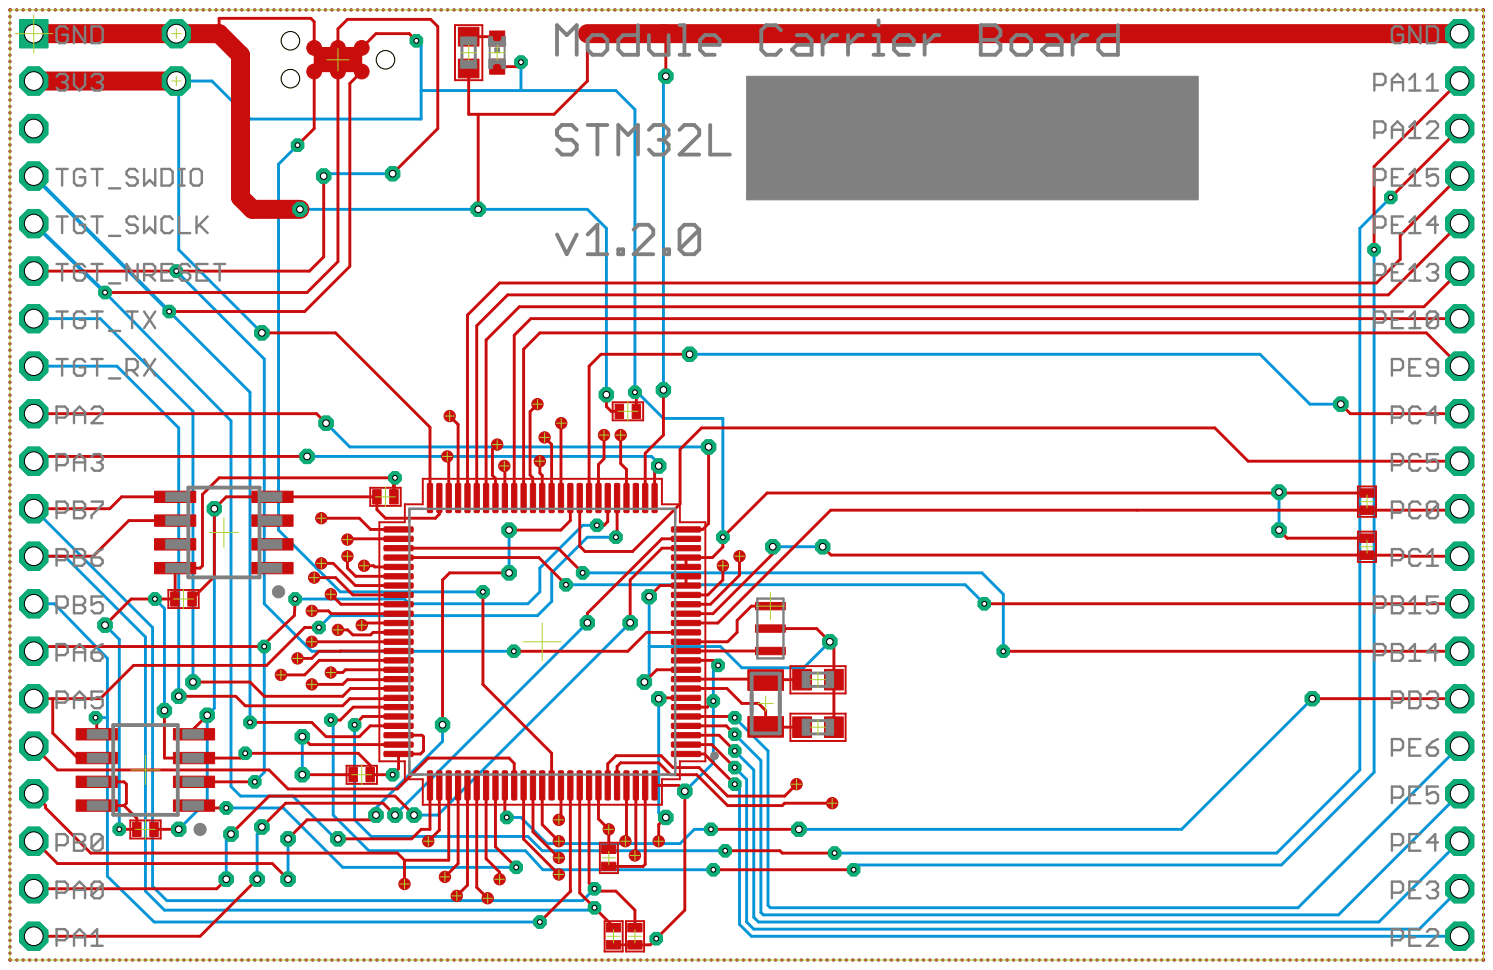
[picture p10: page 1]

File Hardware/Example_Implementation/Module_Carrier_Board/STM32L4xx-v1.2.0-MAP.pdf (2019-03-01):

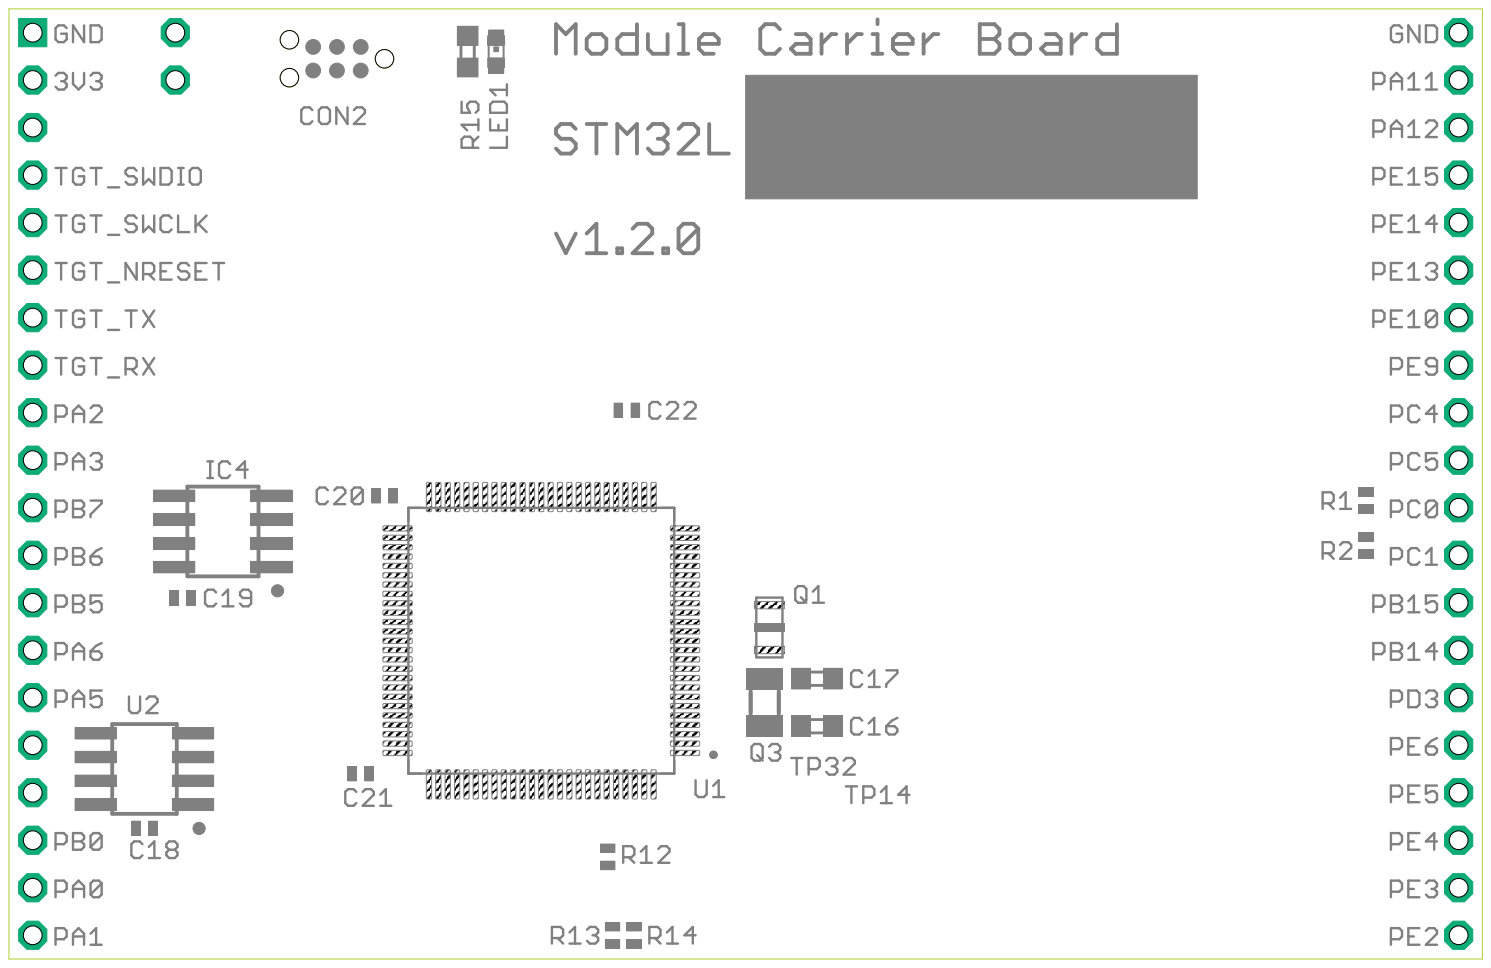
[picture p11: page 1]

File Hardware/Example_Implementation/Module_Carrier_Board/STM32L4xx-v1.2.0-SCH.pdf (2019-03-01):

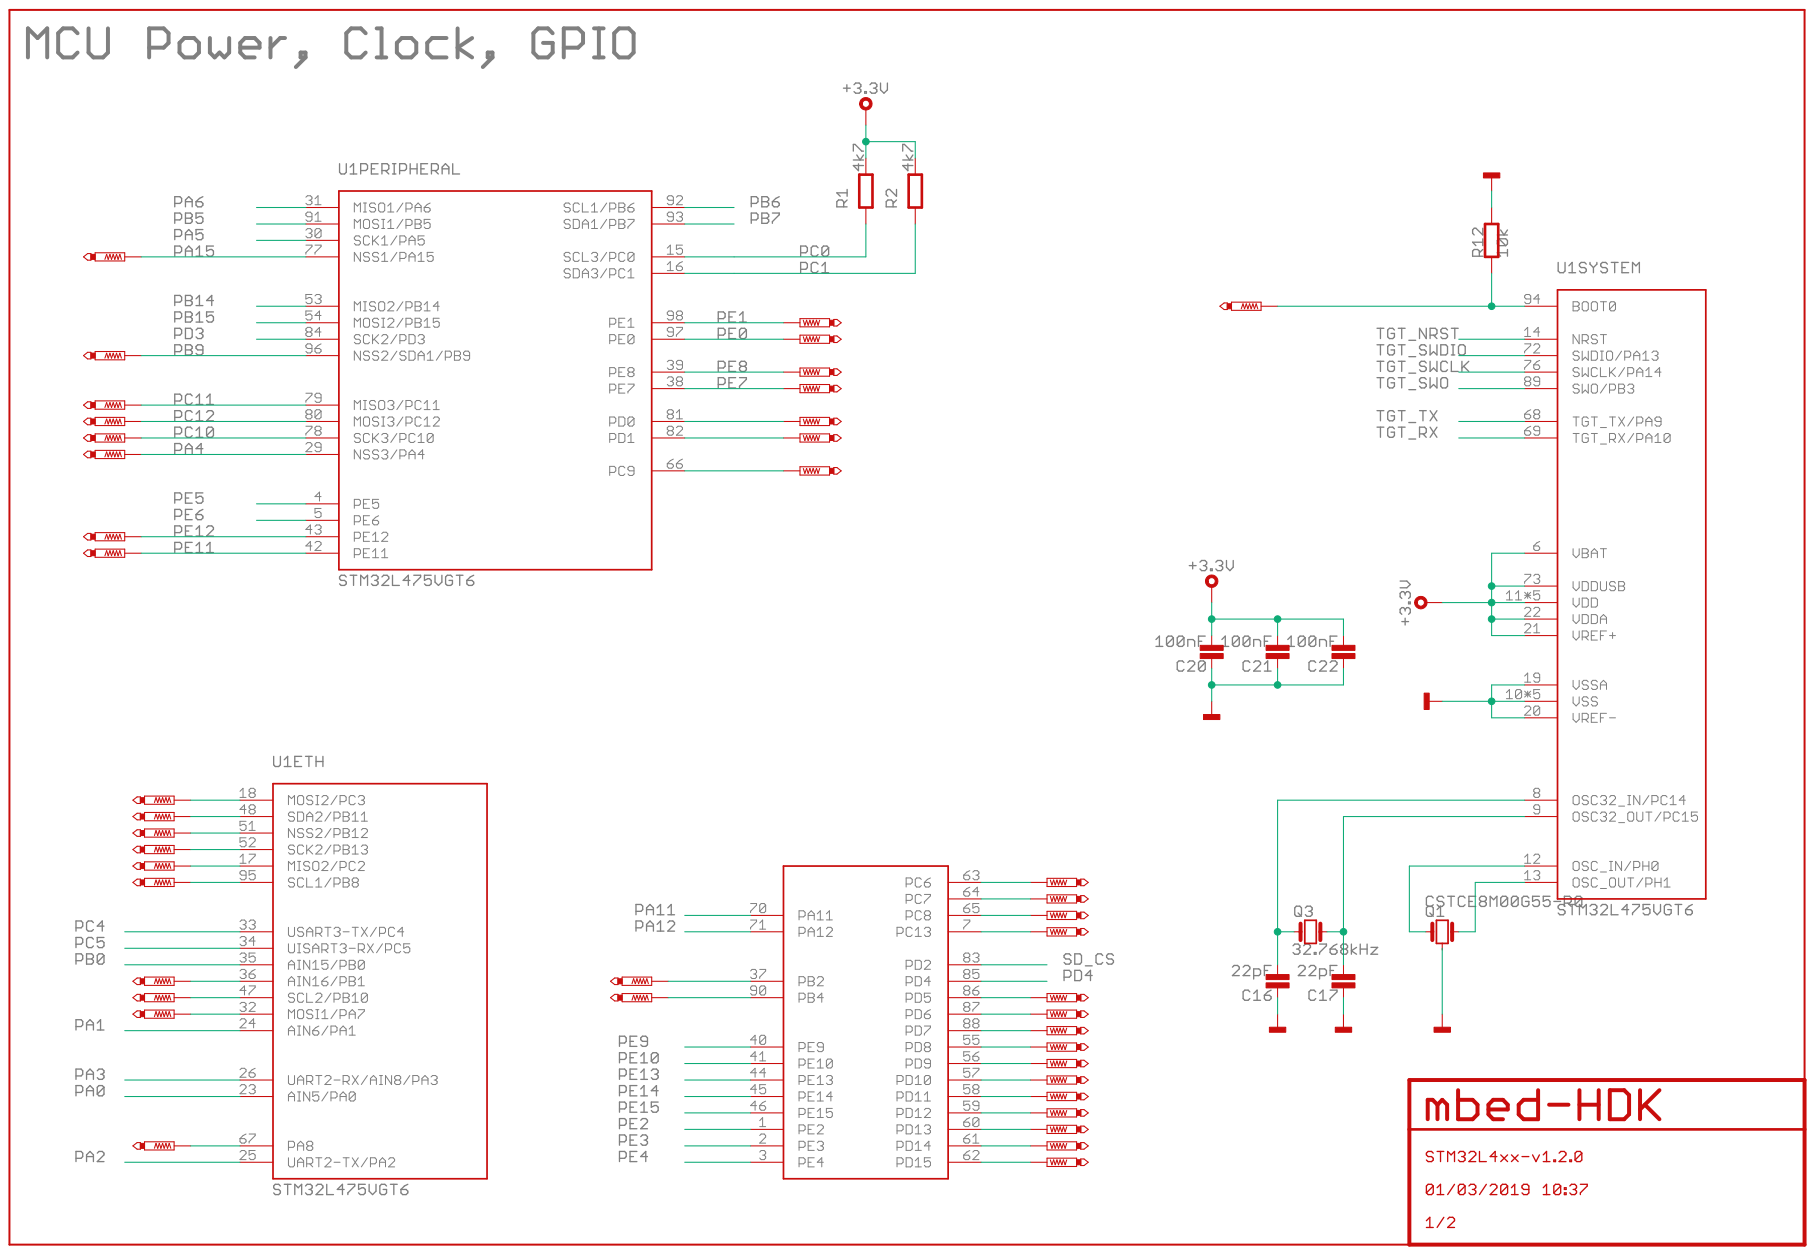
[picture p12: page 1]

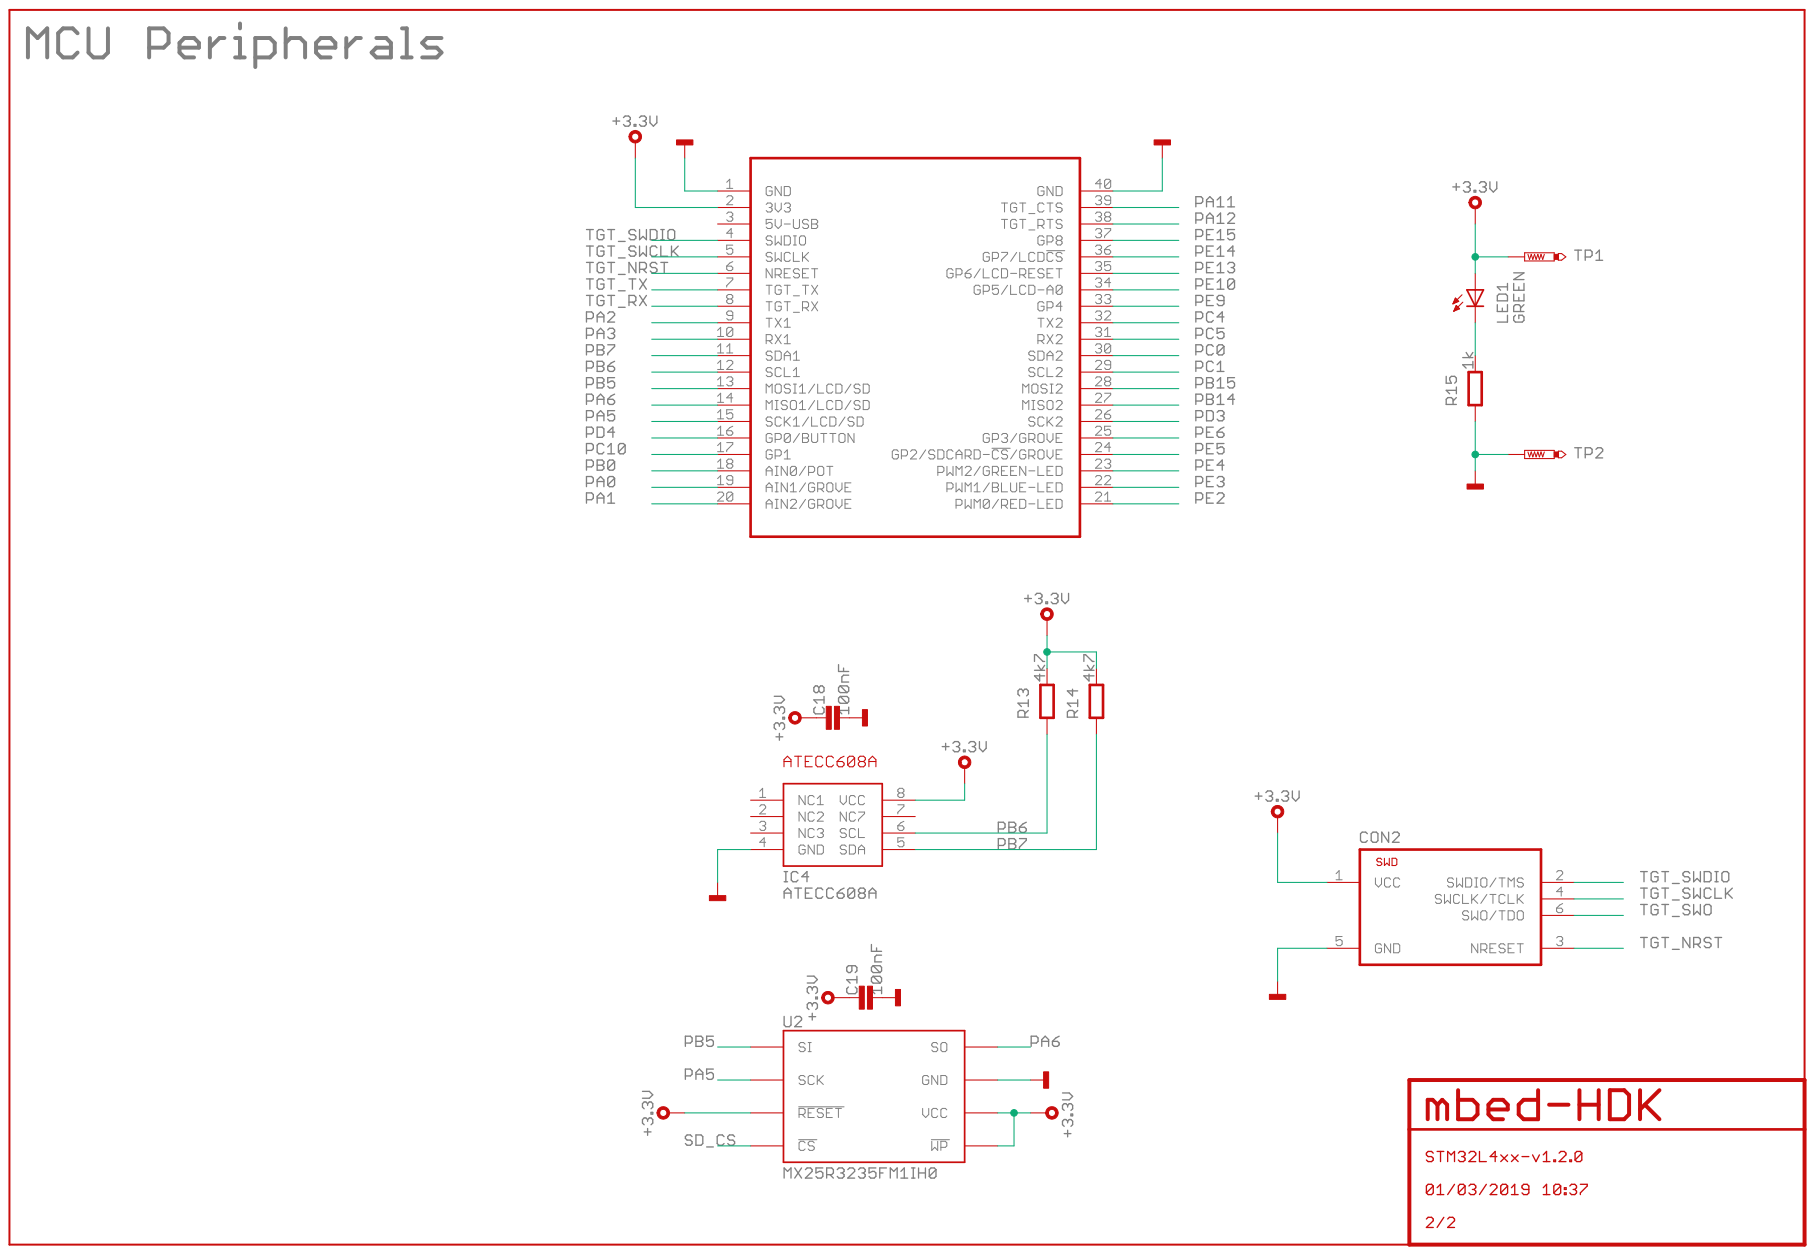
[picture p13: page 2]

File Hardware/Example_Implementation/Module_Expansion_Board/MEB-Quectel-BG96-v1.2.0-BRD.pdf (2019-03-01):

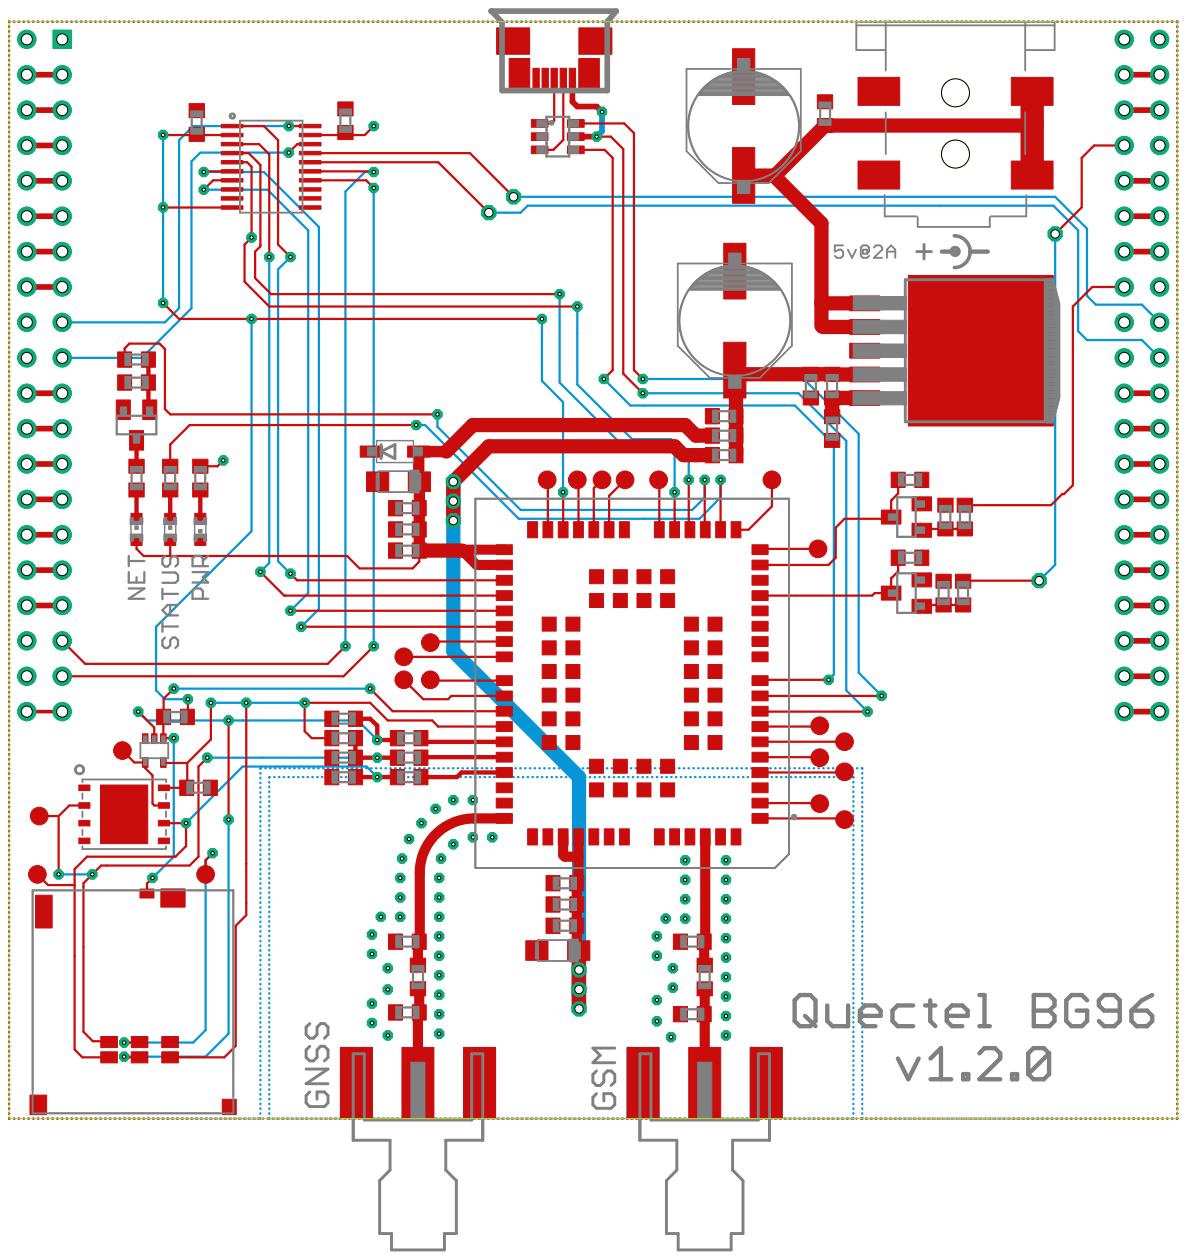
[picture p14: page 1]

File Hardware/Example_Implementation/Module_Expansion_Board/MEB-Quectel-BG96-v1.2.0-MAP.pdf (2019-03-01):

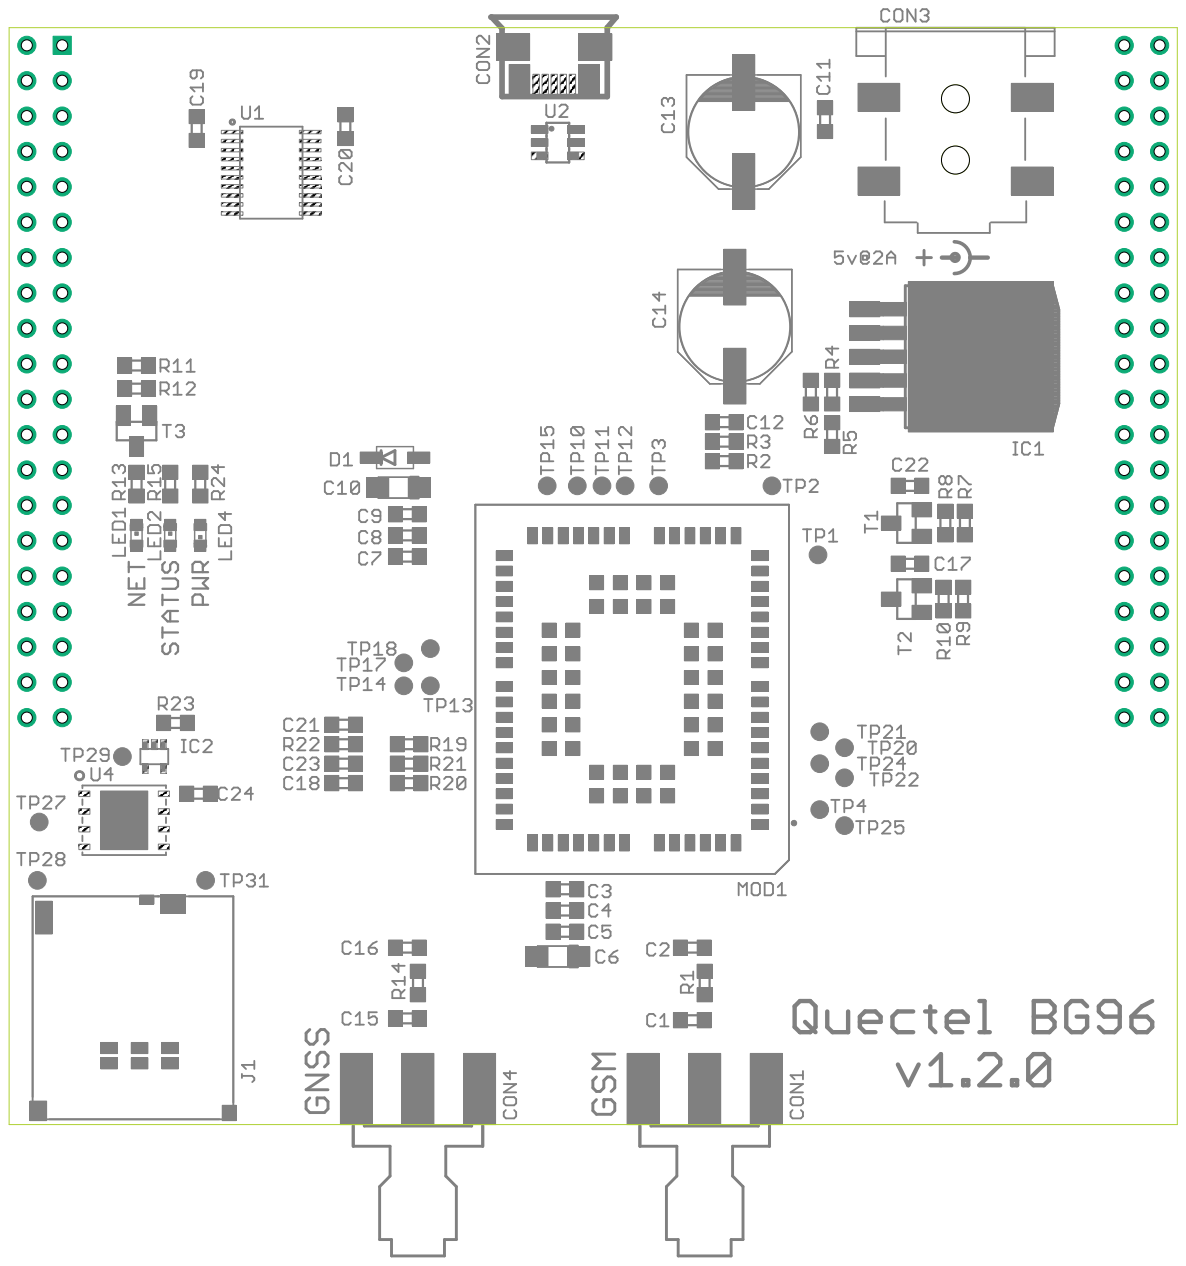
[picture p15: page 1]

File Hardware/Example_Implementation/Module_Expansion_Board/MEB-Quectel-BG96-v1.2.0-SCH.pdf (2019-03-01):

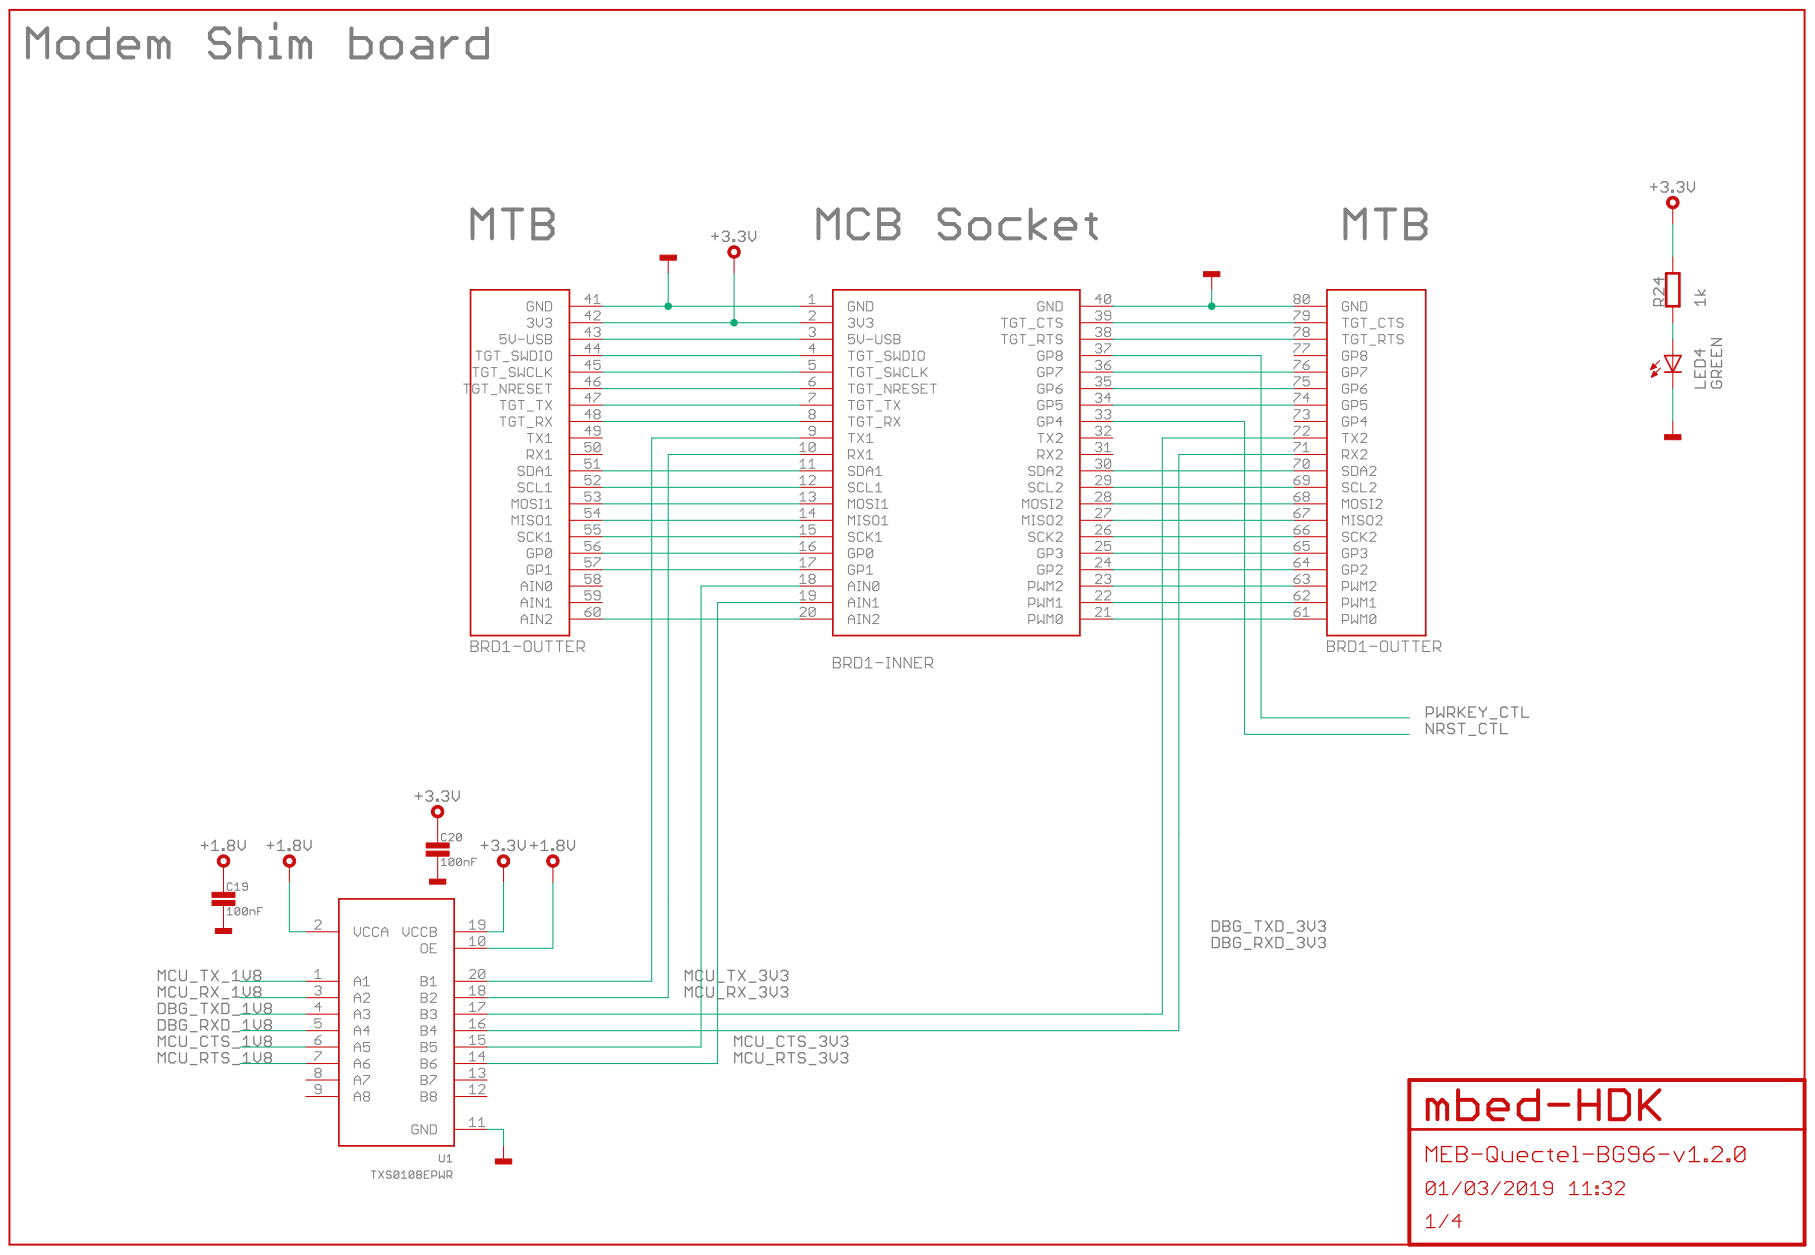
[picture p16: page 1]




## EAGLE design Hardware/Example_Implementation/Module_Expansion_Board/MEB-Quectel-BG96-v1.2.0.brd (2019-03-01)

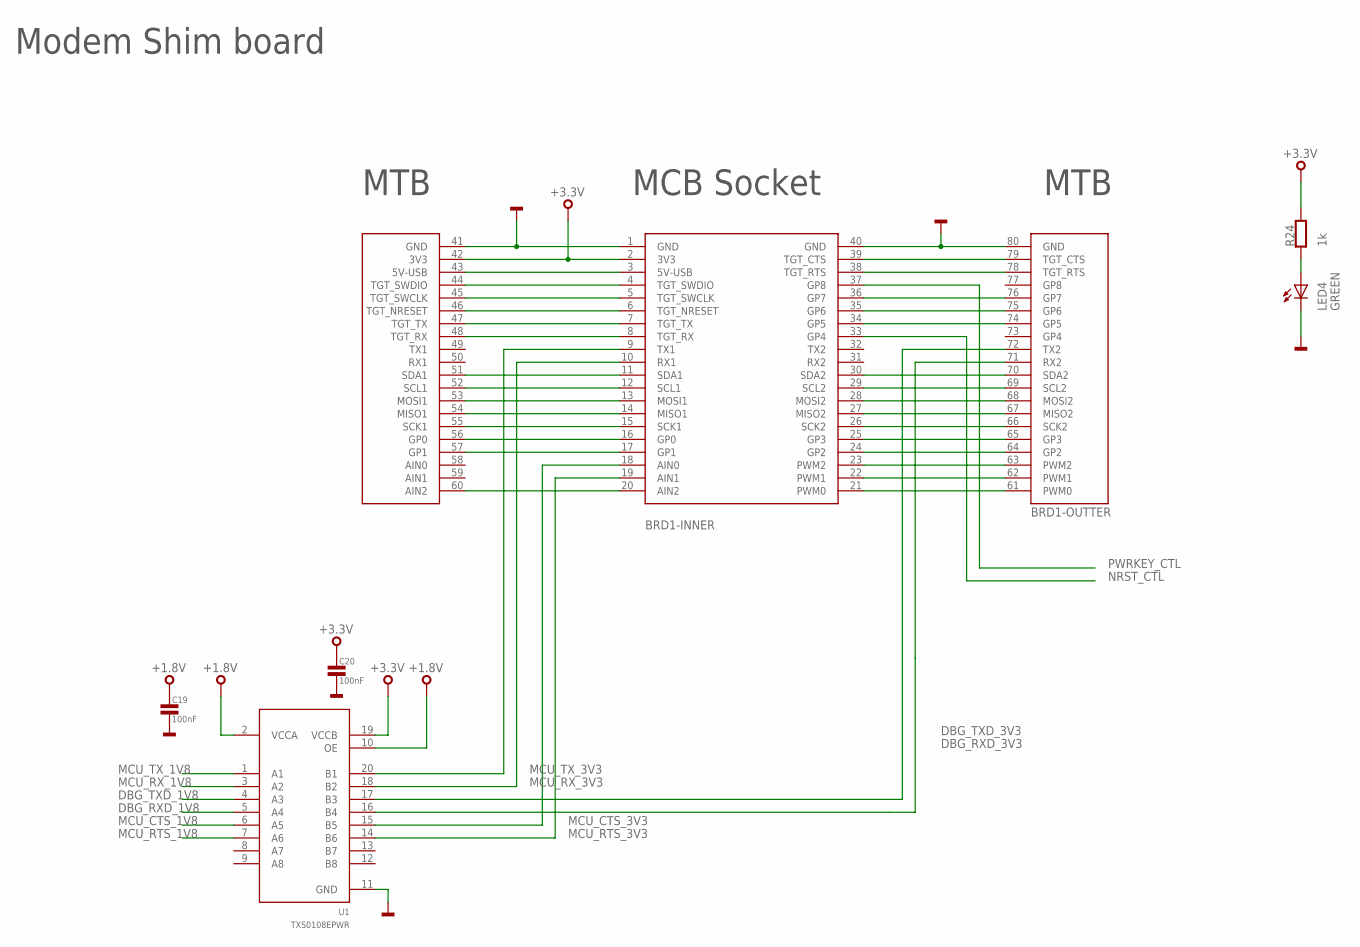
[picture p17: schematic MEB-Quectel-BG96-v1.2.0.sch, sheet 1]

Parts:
BRD1: MODULE-SHIM; MODULE_SOCKET
C19, C20: 100nF; 0603
LED4: GREEN; CHIPLED_0603
R24: 1k; 0603
U1: TXS0108EPWR; TSSOP-20

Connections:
+1.8V: C19.1, U1.2 (VCCA), U1.10 (OE); also elsewhere on the board
+3.3V: BRD1.2 (3V3), BRD1.42 (3V3), C20.1, R24.2, U1.19 (VCCB)
DBG_RXD_1V8: U1.5 (A4); also elsewhere on the board
DBG_RXD_3V3: BRD1.71 (RX2), U1.16 (B4)
DBG_TXD_1V8: U1.4 (A3); also elsewhere on the board
DBG_TXD_3V3: BRD1.72 (TX2), U1.17 (B3)
GND: BRD1.1 (GND), BRD1.40 (GND), BRD1.41 (GND), BRD1.80 (GND), C19.2, C20.2, LED4.C, U1.11 (GND); also elsewhere on the board
MCU_CTS_1V8: U1.6 (A5); also elsewhere on the board
MCU_CTS_3V3: BRD1.18 (AIN0), U1.15 (B5)
MCU_RTS_1V8: U1.7 (A6); also elsewhere on the board
MCU_RTS_3V3: BRD1.19 (AIN1), U1.14 (B6)
MCU_RX_1V8: U1.3 (A2); also elsewhere on the board
MCU_RX_3V3: BRD1.10 (RX1), U1.18 (B2)
MCU_TX_1V8: U1.1 (A1); also elsewhere on the board
MCU_TX_3V3: BRD1.9 (TX1), U1.20 (B1)
unnamed: LED4.A, R24.1
unnamed: BRD1.39 (TGT_CTS), BRD1.79 (TGT_CTS)
unnamed: BRD1.38 (TGT_RTS), BRD1.78 (TGT_RTS)
unnamed: BRD1.36 (GP7), BRD1.76 (GP7)
unnamed: BRD1.35 (GP6), BRD1.75 (GP6)
unnamed: BRD1.34 (GP5), BRD1.74 (GP5)
unnamed: BRD1.30 (SDA2), BRD1.70 (SDA2)
unnamed: BRD1.29 (SCL2), BRD1.69 (SCL2)
unnamed: BRD1.28 (MOSI2), BRD1.68 (MOSI2)
unnamed: BRD1.27 (MISO2), BRD1.67 (MISO2)
unnamed: BRD1.26 (SCK2), BRD1.66 (SCK2)
unnamed: BRD1.25 (GP3), BRD1.65 (GP3)
unnamed: BRD1.24 (GP2), BRD1.64 (GP2)
unnamed: BRD1.23 (PWM2), BRD1.63 (PWM2)
unnamed: BRD1.22 (PWM1), BRD1.62 (PWM1)
unnamed: BRD1.21 (PWM0), BRD1.61 (PWM0)
unnamed: BRD1.3 (5V-USB), BRD1.43 (5V-USB)
unnamed: BRD1.4 (TGT_SWDIO), BRD1.44 (TGT_SWDIO)
unnamed: BRD1.5 (TGT_SWCLK), BRD1.45 (TGT_SWCLK)
unnamed: BRD1.6 (TGT_NRESET), BRD1.46 (TGT_NRESET)
unnamed: BRD1.7 (TGT_TX), BRD1.47 (TGT_TX)
unnamed: BRD1.8 (TGT_RX), BRD1.48 (TGT_RX)
unnamed: BRD1.11 (SDA1), BRD1.51 (SDA1)
unnamed: BRD1.12 (SCL1), BRD1.52 (SCL1)
unnamed: BRD1.13 (MOSI1), BRD1.53 (MOSI1)
unnamed: BRD1.14 (MISO1), BRD1.54 (MISO1)
unnamed: BRD1.15 (SCK1), BRD1.55 (SCK1)
unnamed: BRD1.16 (GP0), BRD1.56 (GP0)
unnamed: BRD1.17 (GP1), BRD1.57 (GP1)
unnamed: BRD1.20 (AIN2), BRD1.60 (AIN2)
NRST_CTL: BRD1.33 (GP4); also elsewhere on the board
PWRKEY_CTL: BRD1.37 (GP8); also elsewhere on the board

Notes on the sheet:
Modem Shim board
MCB Socket
MTB

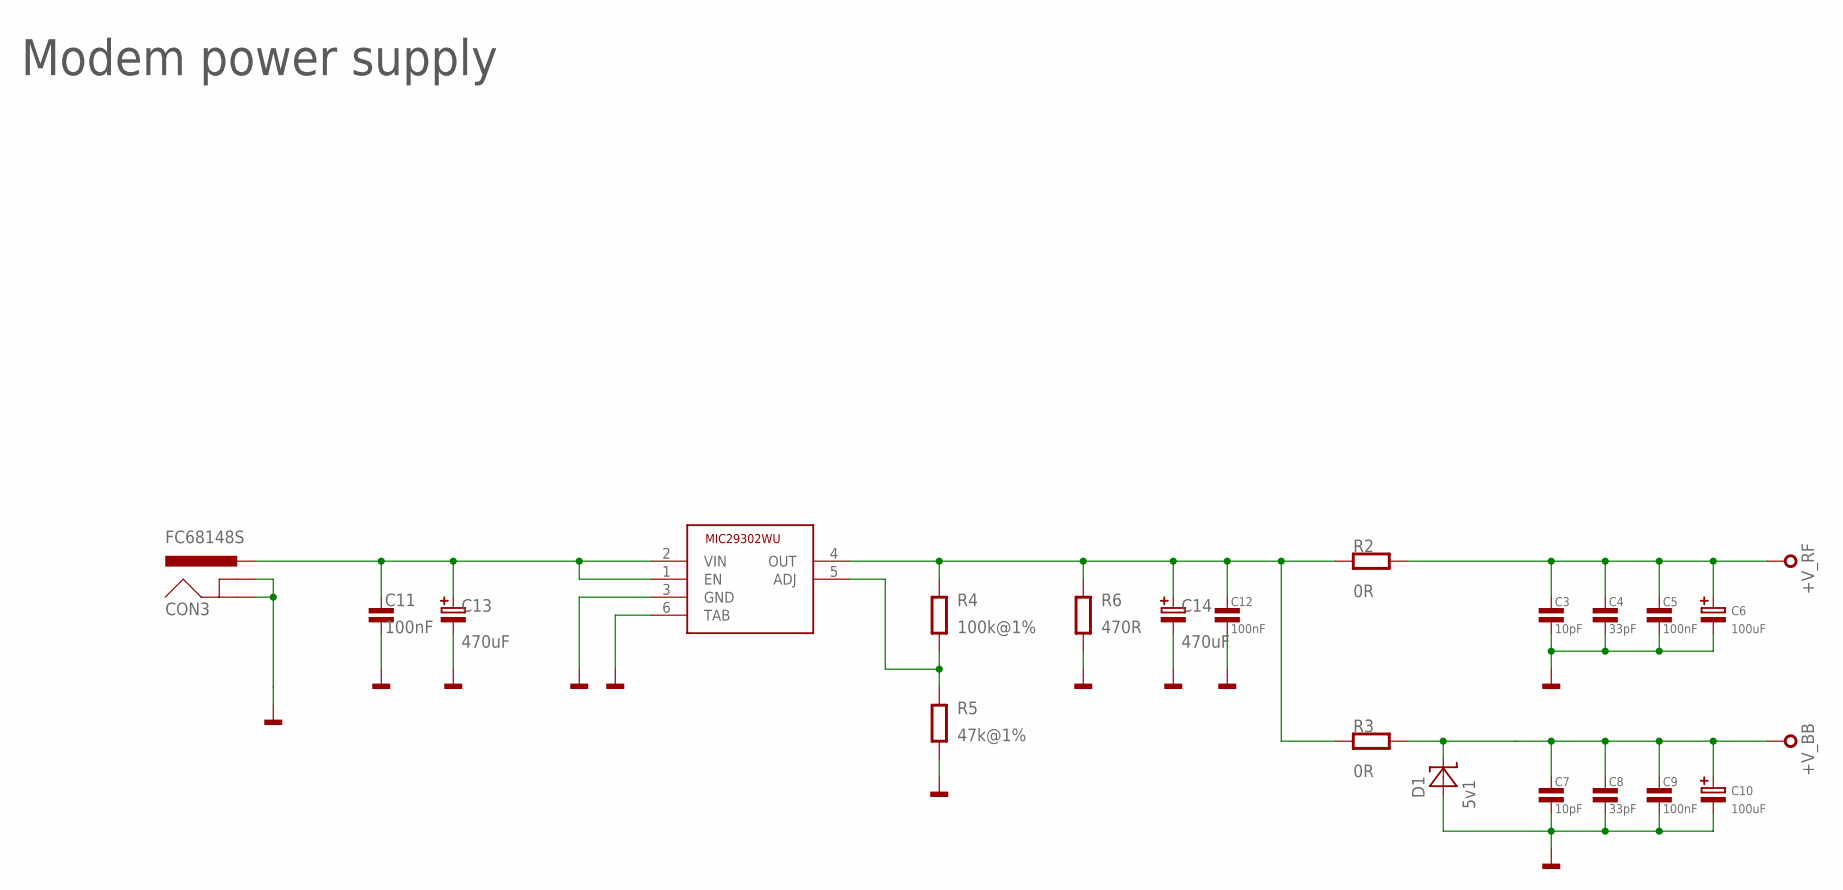
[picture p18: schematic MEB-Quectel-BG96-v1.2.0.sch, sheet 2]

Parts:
C3, C7: 10pF; 0603
C4, C8: 33pF; 0603
C5, C9, C11, C12: 100nF; 0603
C6, C10: 100uF; SMC_A
C13, C14: 470uF; PANASONIC_F
CON3: FC68148S
D1: 5v1; SOD123
IC1: MIC29302WU; TO263-5
R2, R3: 0R; 0603
R4: 100k@1%; 0603
R5: 47k@1%; 0603
R6: 470R; 0603

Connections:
+V_BB: C7.1, C8.1, C9.1, C10.+, D1.2 (C), R3.2; also elsewhere on the board
+V_RF: C3.1, C4.1, C5.1, C6.+, R2.2; also elsewhere on the board
GND: C3.2, C4.2, C5.2, C6.-, C7.2, C8.2, C9.2, C10.-, C11.2, C12.2, C13.-, C14.-, CON3.2 (GNDBREAK), CON3.3 (GND), D1.1 (A), IC1.3 (GND), IC1.6 (TAB), R5.1, R6.1; also elsewhere on the board
unnamed: C11.1, C13.+, CON3.1-1 (PWR), CON3.1-2 (PWR), IC1.1 (EN), IC1.2 (VIN)
unnamed: IC1.5 (ADJ), R4.1, R5.2
unnamed: C12.1, C14.+, IC1.4 (OUT), R2.1, R3.1, R4.2, R6.2

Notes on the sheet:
Modem power supply

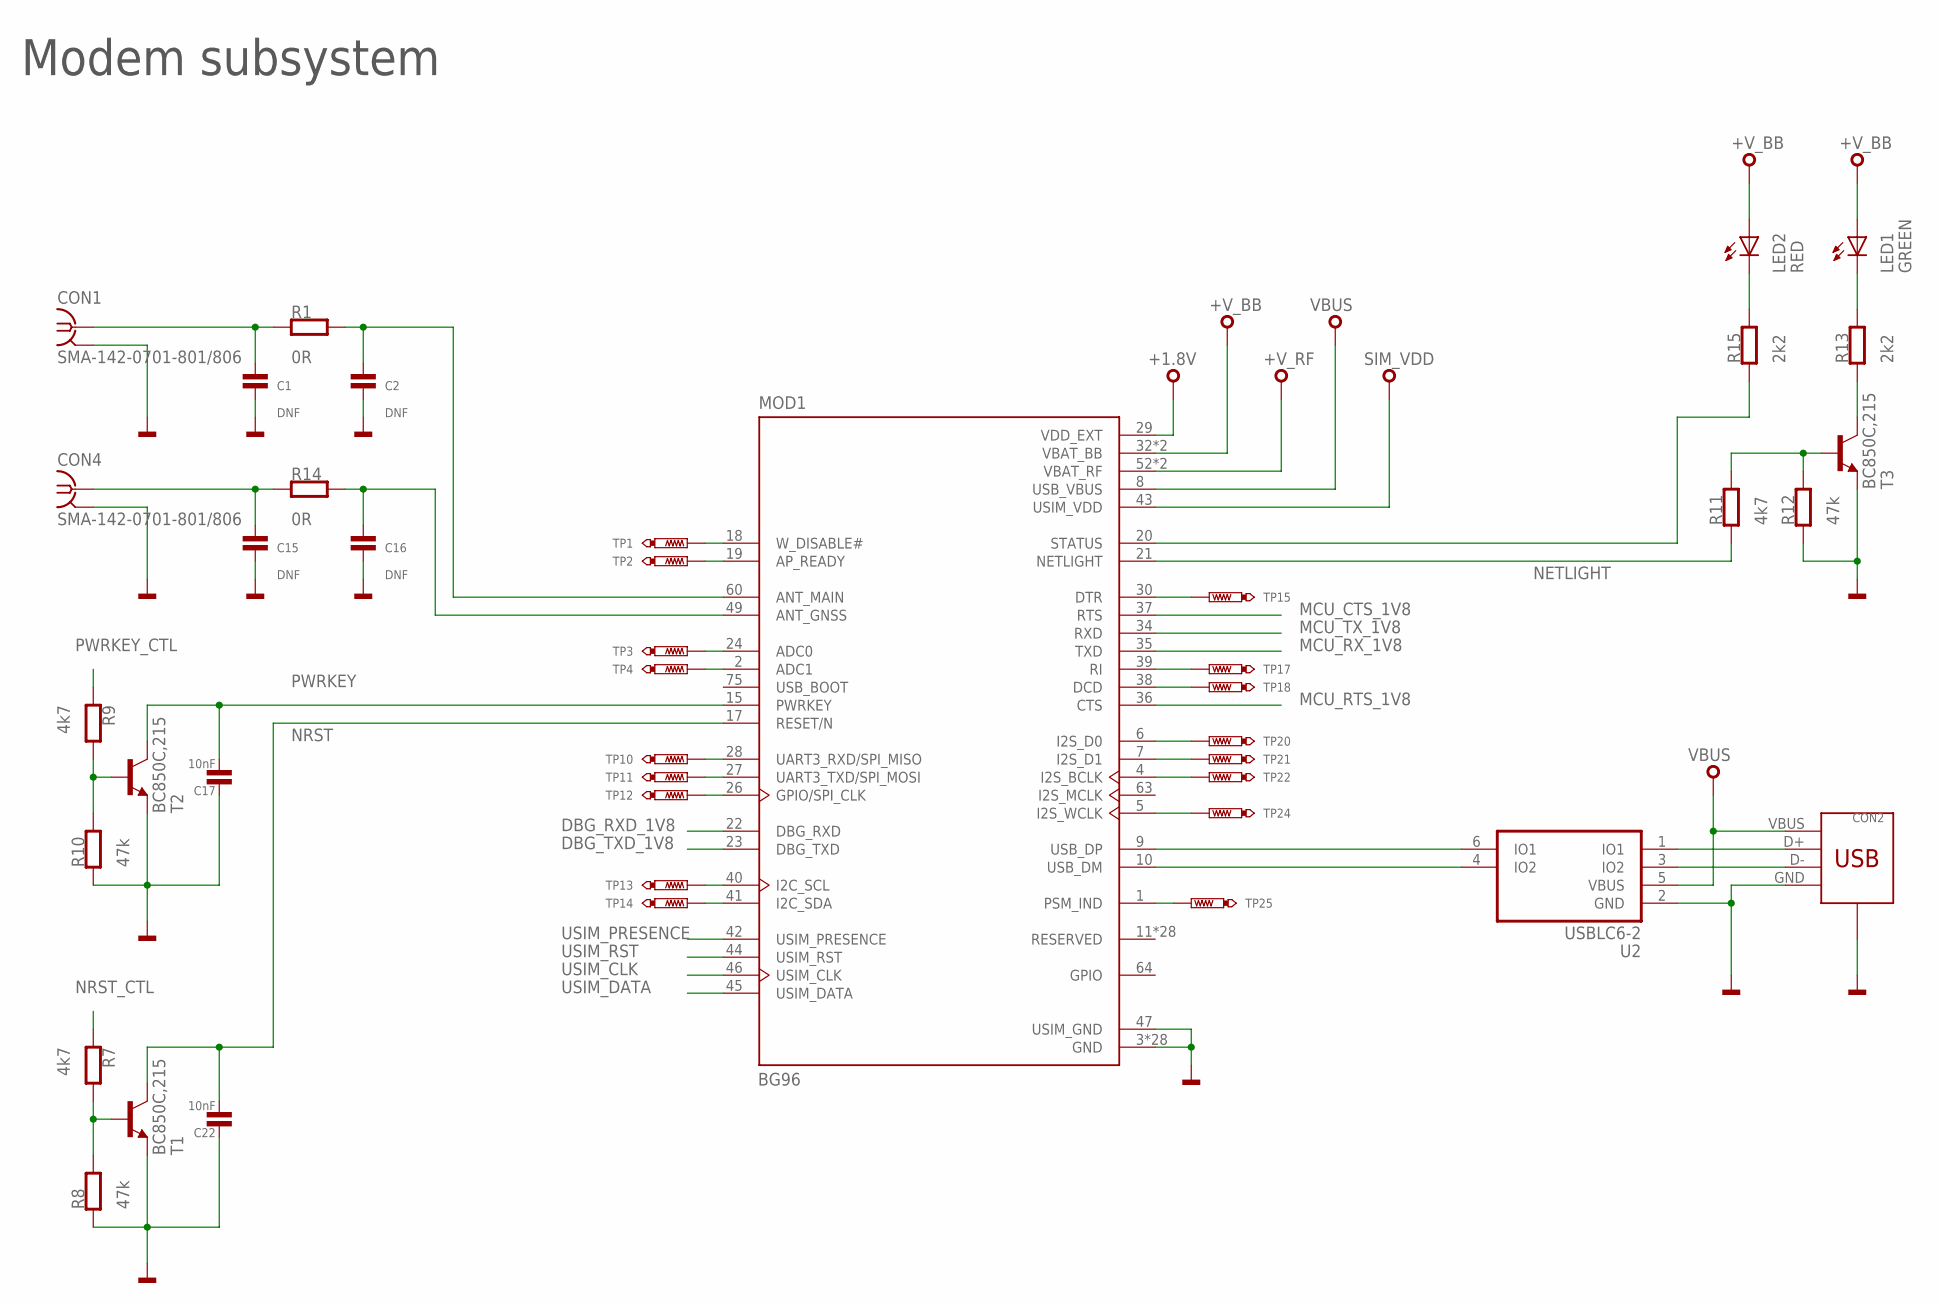
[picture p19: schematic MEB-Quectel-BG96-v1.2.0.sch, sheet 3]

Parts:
C1, C2, C15, C16: DNF; 0603
C17, C22: 10nF; 0603
CON1, CON4: SMA-142-0701-801/806; J502-ND-142-0701-801/806
CON2: 47346-0001; USB-MICRO-B-H
LED1: GREEN; CHIPLED_0603
LED2: RED; CHIPLED_0603
MOD1: BG96; LTE_MODULE_BG96
R1, R14: 0R; 0603
R7, R9, R11: 4k7; 0603
R8, R10, R12: 47k; 0603
R13, R15: 2k2; 0603
T1, T2, T3: BC850C,215; SOT23-3
TP1, TP2, TP3, TP4, TP10, TP11, TP12, TP13, TP14, TP15, TP17, TP18, TP20, TP21, TP22, TP24, TP25: TEST_POINT-50R-SMD; TP50-SMD
U2: USBLC6-2SC6; SOT23-6L

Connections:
+1.8V: MOD1.29 (VDD_EXT); also elsewhere on the board
+V_BB: LED1.A, LED2.A, MOD1.32 (VBAT_BB), MOD1.33 (VBAT_BB); also elsewhere on the board
+V_RF: MOD1.52 (VBAT_RF), MOD1.53 (VBAT_RF); also elsewhere on the board
DBG_RXD_1V8: MOD1.22 (DBG_RXD); also elsewhere on the board
DBG_TXD_1V8: MOD1.23 (DBG_TXD); also elsewhere on the board
GND: C1.1, C2.1, C15.1, C16.1, C17.1, C22.1, CON1.G@1 (2), CON1.G@2 (2), CON1.G@3 (2), CON1.G@4 (2), CON2.GND, CON2.GND1 (SHEILD), CON2.GND2 (SHEILD), CON2.GND3 (SHEILD), CON2.GND4 (SHEILD), CON4.G@1 (2), CON4.G@2 (2), CON4.G@3 (2), CON4.G@4 (2), MOD1.3 (GND), MOD1.31 (GND), MOD1.47 (USIM_GND), MOD1.48 (GND), MOD1.50 (GND), MOD1.54 (GND), MOD1.55 (GND), MOD1.58 (GND), MOD1.59 (GND), MOD1.61 (GND), MOD1.62 (GND), MOD1.67 (GND), MOD1.68 (GND), MOD1.69 (GND), MOD1.70 (GND), MOD1.71 (GND), MOD1.72 (GND), MOD1.73 (GND), MOD1.74 (GND), MOD1.79 (GND), MOD1.80 (GND), MOD1.81 (GND), MOD1.82 (GND), MOD1.89 (GND), MOD1.90 (GND), MOD1.91 (GND), MOD1.100 (GND), MOD1.101 (GND), MOD1.102 (GND), R8.1, R10.1, R12.1, T1.2 (E), T2.2 (E), T3.2 (E), U2.2 (GND); also elsewhere on the board
MCU_CTS_1V8: MOD1.37 (RTS); also elsewhere on the board
MCU_RTS_1V8: MOD1.36 (CTS); also elsewhere on the board
MCU_RX_1V8: MOD1.35 (TXD); also elsewhere on the board
MCU_TX_1V8: MOD1.34 (RXD); also elsewhere on the board
unnamed: LED2.C, R15.2
unnamed: LED1.C, R13.2
unnamed: MOD1.30 (DTR), TP15.TP
unnamed: MOD1.39 (RI), TP17.TP
unnamed: MOD1.38 (DCD), TP18.TP
unnamed: C1.2, CON1.1, R1.1
unnamed: C2.2, MOD1.60 (ANT_MAIN), R1.2
unnamed: C15.2, CON4.1, R14.1
unnamed: C16.2, MOD1.49 (ANT_GNSS), R14.2
unnamed: R9.2, R10.2, T2.1 (B)
unnamed: R7.2, R8.2, T1.1 (B)
unnamed: MOD1.6 (I2S_D0), TP20.TP
unnamed: CON2.D+, U2.1 (IO1)
unnamed: MOD1.7 (I2S_D1), TP21.TP
unnamed: MOD1.4 (I2S_BCLK), TP22.TP
unnamed: CON2.D-, U2.3 (IO2)
unnamed: MOD1.9 (USB_DP), U2.6 (IO1)
unnamed: MOD1.10 (USB_DM), U2.4 (IO2)
unnamed: R11.2, R12.2, T3.1 (B)
unnamed: MOD1.5 (I2S_WCLK), TP24.TP
unnamed: MOD1.1 (PSM_IND), TP25.TP
unnamed: MOD1.41 (I2C_SDA), TP14.TP
unnamed: MOD1.40 (I2C_SCL), TP13.TP
unnamed: MOD1.26 (GPIO/SPI_CLK), TP12.TP
unnamed: MOD1.27 (UART3_TXD/SPI_MOSI), TP11.TP
unnamed: MOD1.28 (UART3_RXD/SPI_MISO), TP10.TP
unnamed: MOD1.18 (W_DISABLE#), TP1.TP
unnamed: MOD1.19 (AP_READY), TP2.TP
unnamed: MOD1.2 (ADC1), TP4.TP
unnamed: MOD1.24 (ADC0), TP3.TP
NETLIGHT: MOD1.21 (NETLIGHT), R11.1
NRST: C22.2, MOD1.17 (RESET/N), T1.3 (C)
NRST1: R13.1, T3.3 (C)
NRST_CTL: R7.1; also elsewhere on the board
PWRKEY: C17.2, MOD1.15 (PWRKEY), T2.3 (C)
PWRKEY_CTL: R9.1; also elsewhere on the board
SIM_VDD: MOD1.43 (USIM_VDD); also elsewhere on the board
STATUS: MOD1.20 (STATUS), R15.1
USIM_CLK: MOD1.46 (USIM_CLK); also elsewhere on the board
USIM_DATA: MOD1.45 (USIM_DATA); also elsewhere on the board
USIM_PRESENCE: MOD1.42 (USIM_PRESENCE); also elsewhere on the board
USIM_RST: MOD1.44 (USIM_RST); also elsewhere on the board
VBUS: CON2.VBUS, MOD1.8 (USB_VBUS), U2.5 (VBUS)

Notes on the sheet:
Modem subsystem

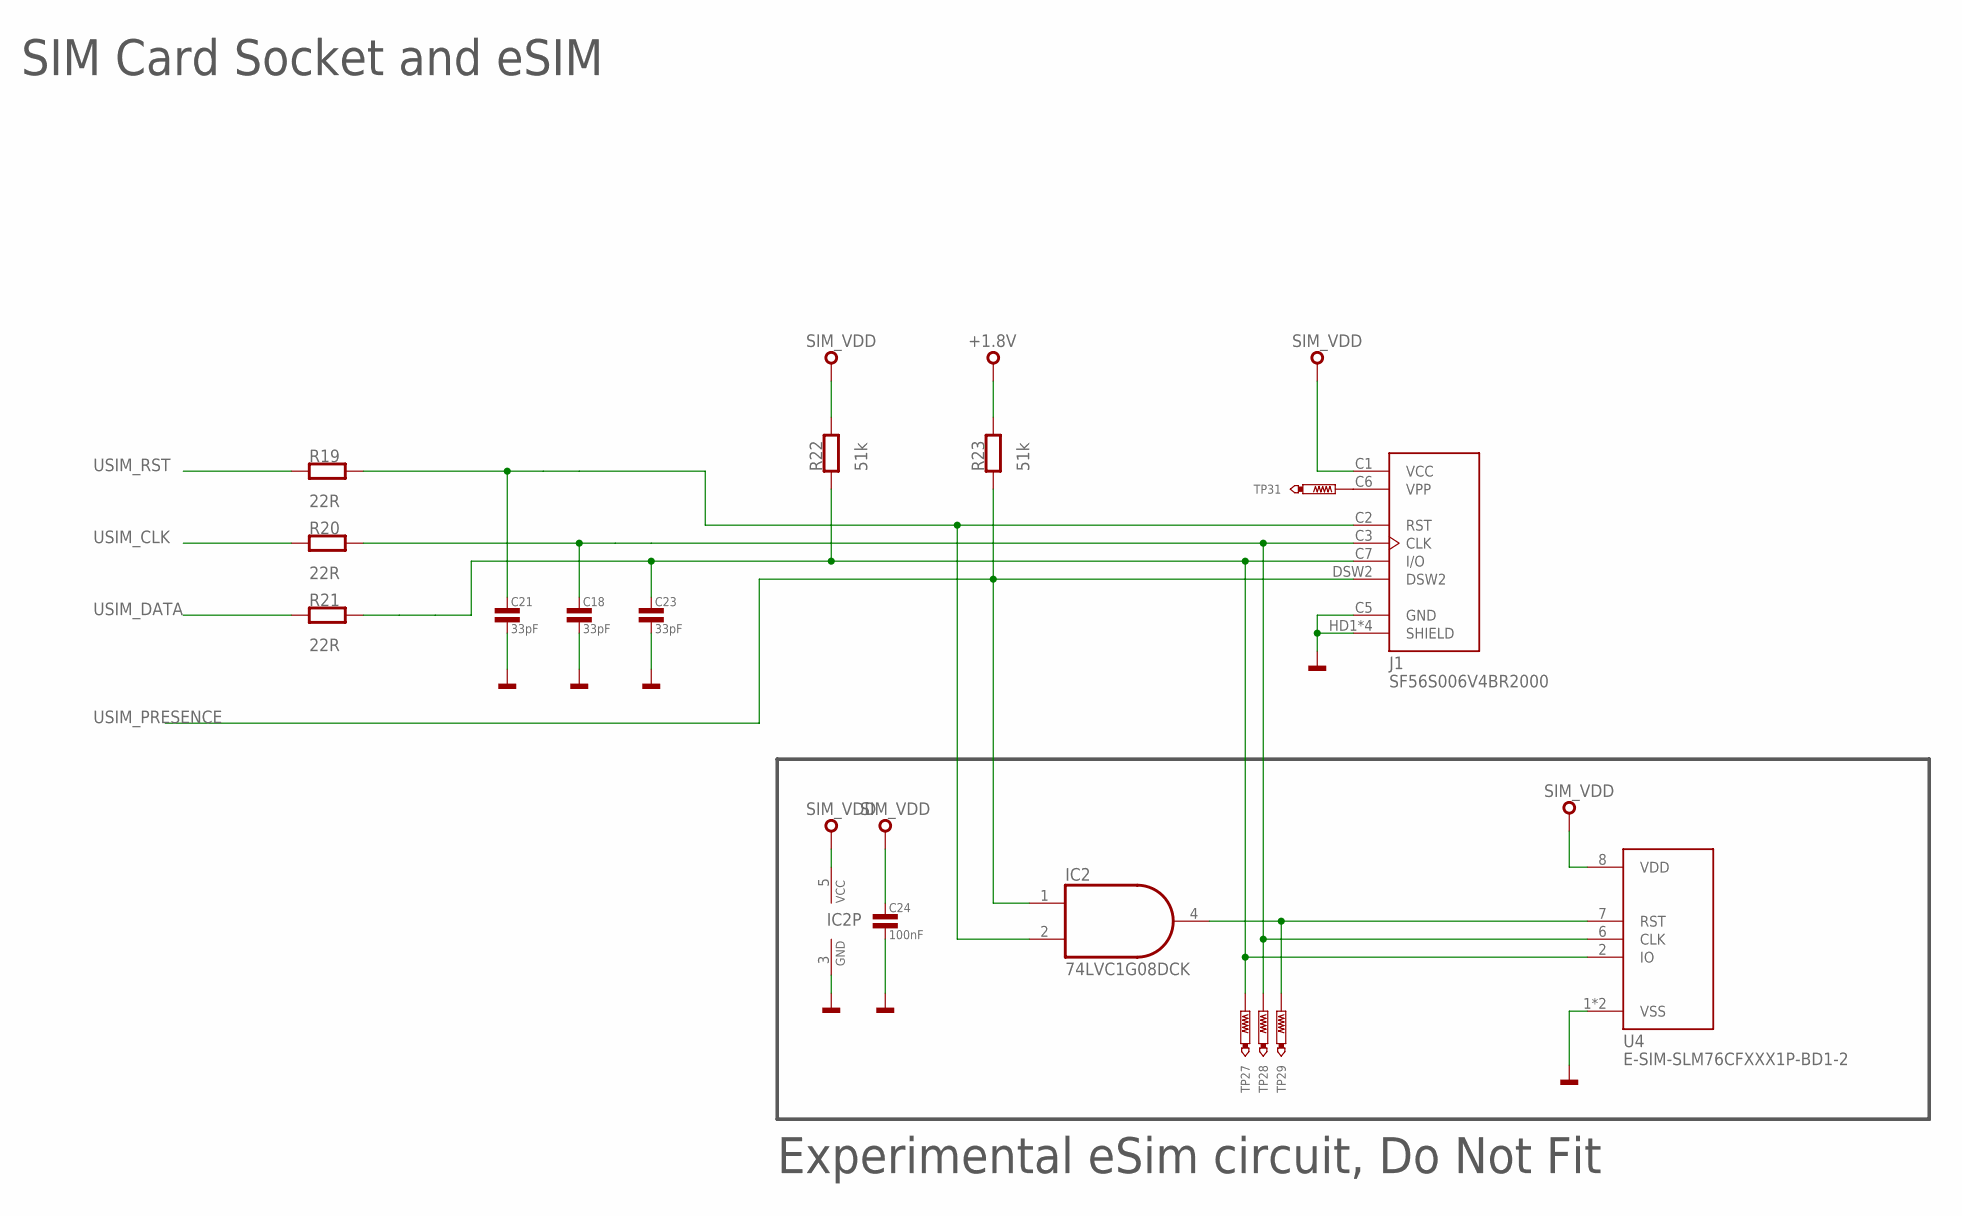
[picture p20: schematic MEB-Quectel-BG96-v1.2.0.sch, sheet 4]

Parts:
C18, C21, C23: 33pF; 0603
C24: 100nF; 0603
IC2: 74LVC1G08DCK; SC70-5
J1: SF56S006V4BR2000; JAE_SF56S006V4BR2000
R19, R20, R21: 22R; 0603
R22, R23: 51k; 0603
TP27, TP28, TP29, TP31: TEST_POINT-50R-SMD; TP50-SMD
U4: E-SIM-SLM76CFXXX1P-BD1-2; VQFN-8-1

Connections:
+1.8V: R23.2; also elsewhere on the board
GND: C18.2, C21.2, C23.2, C24.2, IC2.3 (GND), J1.C5 (GND), J1.HD1 (SHIELD), J1.HD2,DSW1 (SHIELD), J1.HD3 (SHIELD), J1.HD4 (SHIELD), U4.1 (VSS), U4.P (VSS); also elsewhere on the board
unnamed: IC2.4 (O), TP29.TP, U4.7 (RST)
unnamed: C21.1, IC2.2 (I1), J1.C2 (RST), R19.2
unnamed: C18.1, J1.C3 (CLK), R20.2, TP28.TP, U4.6 (CLK)
unnamed: C23.1, J1.C7 (I/O), R21.2, R22.1, TP27.TP, U4.2 (IO)
unnamed: J1.C6 (VPP), TP31.TP
SIM_VDD: C24.1, IC2.5 (VCC), J1.C1 (VCC), R22.2, U4.8 (VDD); also elsewhere on the board
USIM_CLK: R20.1; also elsewhere on the board
USIM_DATA: R21.1; also elsewhere on the board
USIM_PRESENCE: IC2.1 (I0), J1.DSW2, R23.1; also elsewhere on the board
USIM_RST: R19.1; also elsewhere on the board

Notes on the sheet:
SIM Card Socket and eSIM
Experimental eSim circuit, Do Not Fit

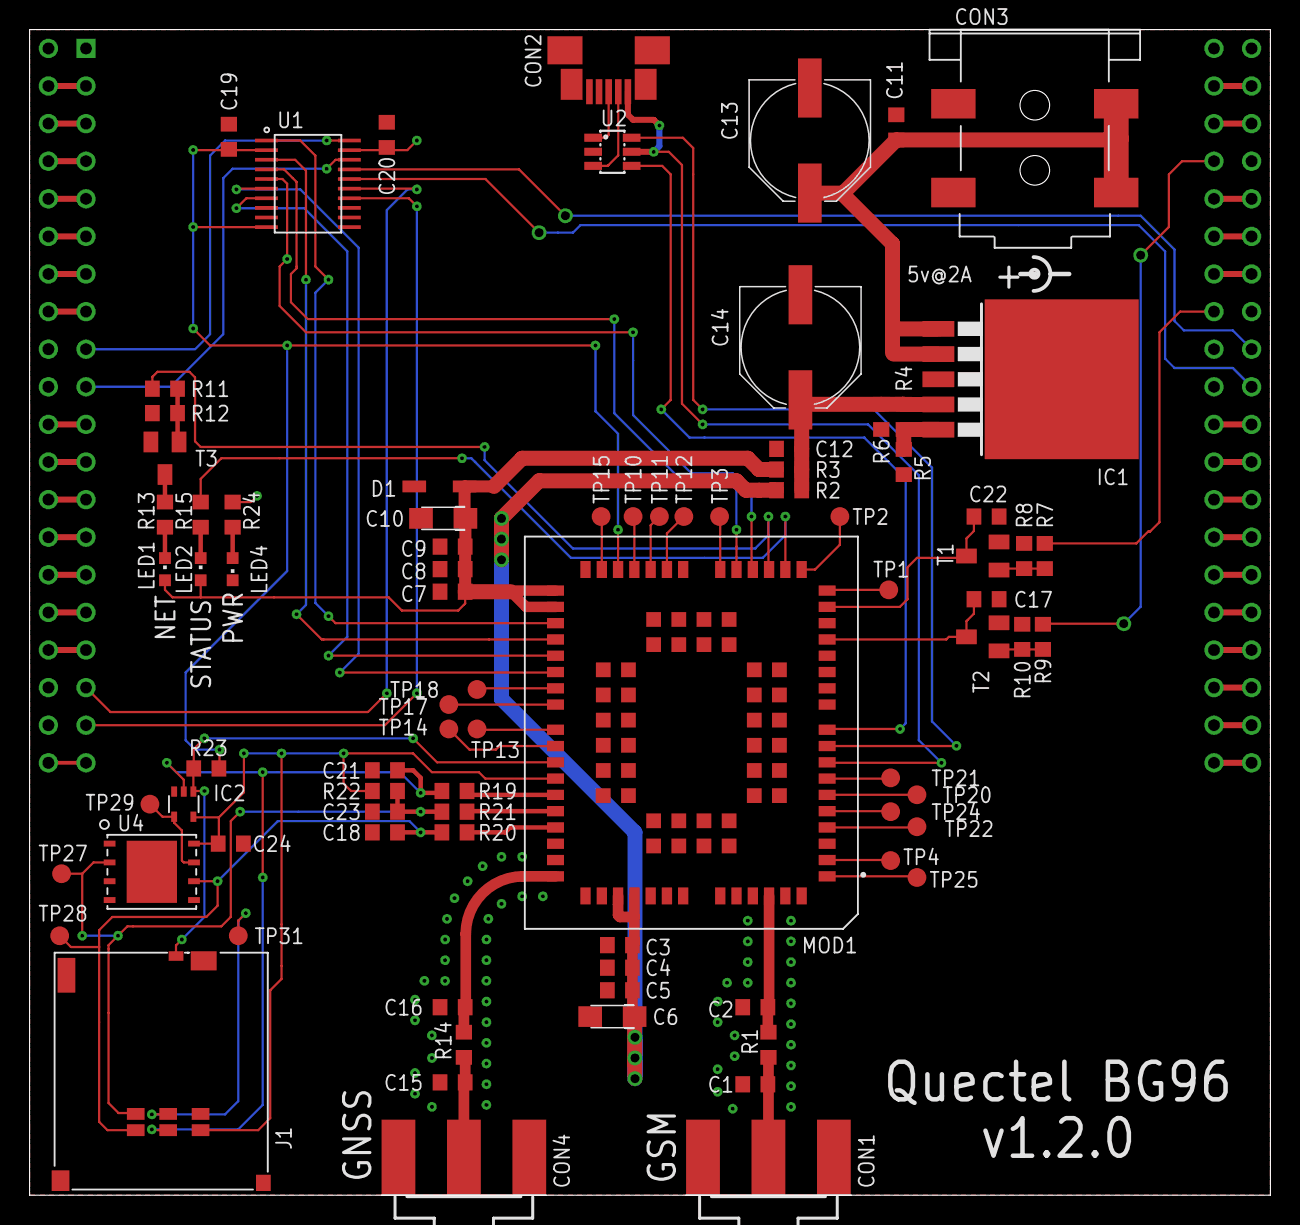
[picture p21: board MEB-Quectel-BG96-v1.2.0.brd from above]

Board: 2 copper layers, 83.8 x 78.7 mm, 85 parts (0 on the bottom side), 98 nets.

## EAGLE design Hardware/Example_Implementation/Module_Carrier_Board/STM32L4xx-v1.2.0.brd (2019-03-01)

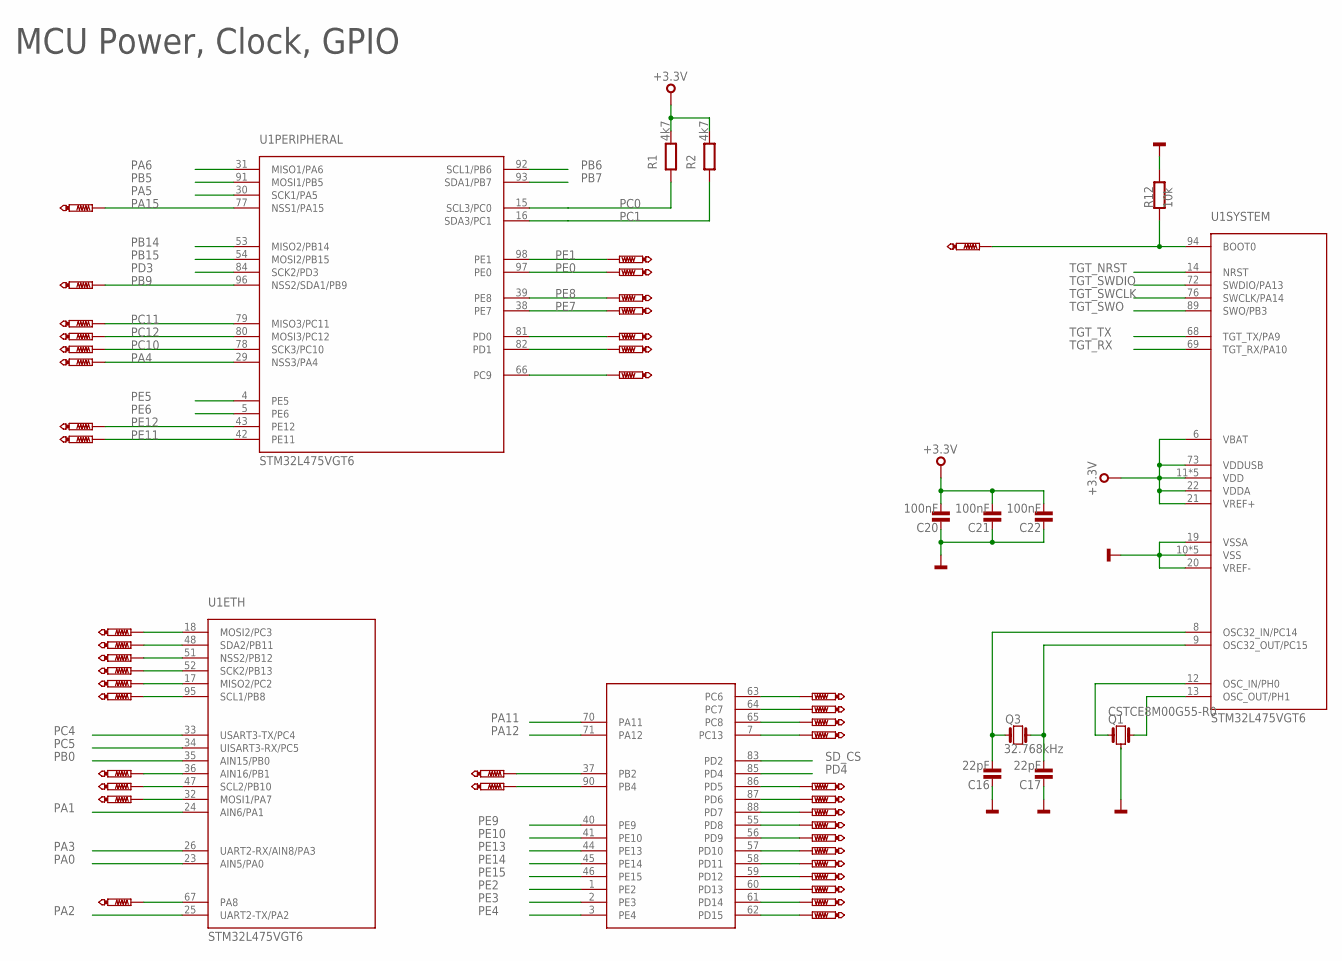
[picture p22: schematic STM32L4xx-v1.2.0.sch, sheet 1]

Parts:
C16, C17: 22pF; 0603
C20, C21, C22: 100nF; 0402
Q1: CSTCE8M00G55-R0
Q3: 32.768kHz; FC135
R1, R2: 4k7; 0402
R12: 10k; 0402
TP3, TP4, TP5, TP6, TP7, TP8, TP9, TP10, TP11, TP12, TP13, TP14, TP15, TP16, TP17, TP18, TP19, TP20, TP21, TP22, TP23, TP24, TP25, TP26, TP27, TP28, TP29, TP30, TP31, TP32, TP33, TP34, TP35, TP36, TP37, TP38, TP39, TP40, TP41, TP42, TP43, TP44, TP45: PTR1TP06R; TP06R
U1: STM32L475VGT6; QFP50P1600X1600X160-100N

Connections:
+3.3V: C20.2, C21.2, C22.2, R1.2, R2.2, U1.6 (VBAT), U1.11 (VDD), U1.21 (VREF+), U1.22 (VDDA), U1.28 (VDD), U1.50 (VDD), U1.73 (VDDUSB), U1.75 (VDD), U1.100 (VDD); also elsewhere on the board
GND: C16.1, C17.1, C20.1, C21.1, C22.1, Q1.2, R12.2, U1.10 (VSS), U1.19 (VSSA), U1.20 (VREF-), U1.27 (VSS), U1.49 (VSS), U1.74 (VSS), U1.99 (VSS); also elsewhere on the board
unnamed: TP5.TP, U1.55 (PD8)
unnamed: TP21.TP, U1.62 (PD15)
unnamed: R12.1, TP6.TP, U1.94 (BOOT0)
unnamed: TP26.TP, U1.37 (PB2)
unnamed: TP25.TP, U1.7 (PC13)
unnamed: TP27.TP, U1.18 (MOSI2/PC3)
unnamed: TP28.TP, U1.48 (SDA2/PB11)
unnamed: TP3.TP, U1.81 (PD0)
unnamed: TP29.TP, U1.51 (NSS2/PB12)
unnamed: TP30.TP, U1.52 (SCK2/PB13)
unnamed: Q1.1, U1.12 (OSC_IN/PH0)
unnamed: Q1.3, U1.13 (OSC_OUT/PH1)
unnamed: C17.2, Q3.X2 (2), U1.9 (OSC32_OUT/PC15)
unnamed: TP31.TP, U1.17 (MISO2/PC2)
unnamed: C16.2, Q3.X1 (1), U1.8 (OSC32_IN/PC14)
unnamed: TP4.TP, U1.82 (PD1)
unnamed: TP7.TP, U1.66 (PC9)
unnamed: TP32.TP, U1.95 (SCL1/PB8)
unnamed: TP33.TP, U1.67 (PA8)
unnamed: TP18.TP, U1.88 (PD7)
unnamed: TP11.TP, U1.90 (PB4)
unnamed: TP34.TP, U1.36 (AIN16/PB1)
unnamed: TP20.TP, U1.86 (PD5)
unnamed: TP19.TP, U1.87 (PD6)
unnamed: TP17.TP, U1.65 (PC8)
unnamed: TP16.TP, U1.64 (PC7)
unnamed: TP36.TP, U1.47 (SCL2/PB10)
unnamed: TP15.TP, U1.63 (PC6)
unnamed: TP12.TP, U1.60 (PD13)
unnamed: TP35.TP, U1.32 (MOSI1/PA7)
unnamed: TP13.TP, U1.56 (PD9)
unnamed: TP10.TP, U1.57 (PD10)
unnamed: TP22.TP, U1.58 (PD11)
unnamed: TP23.TP, U1.59 (PD12)
unnamed: TP24.TP, U1.61 (PD14)
PA0: U1.23 (AIN5/PA0); also elsewhere on the board
PA1: U1.24 (AIN6/PA1); also elsewhere on the board
PA2: U1.25 (UART2-TX/PA2); also elsewhere on the board
PA3: U1.26 (UART2-RX/AIN8/PA3); also elsewhere on the board
PA4: TP44.TP, U1.29 (NSS3/PA4)
PA5: U1.30 (SCK1/PA5); also elsewhere on the board
PA6: U1.31 (MISO1/PA6); also elsewhere on the board
PA11: U1.70 (PA11); also elsewhere on the board
PA12: U1.71 (PA12); also elsewhere on the board
PA15: TP37.TP, U1.77 (NSS1/PA15)
PB0: U1.35 (AIN15/PB0); also elsewhere on the board
PB5: U1.91 (MOSI1/PB5); also elsewhere on the board
PB6: U1.92 (SCL1/PB6); also elsewhere on the board
PB7: U1.93 (SDA1/PB7); also elsewhere on the board
PB9: TP14.TP, U1.96 (NSS2/SDA1/PB9)
PB14: U1.53 (MISO2/PB14); also elsewhere on the board
PB15: U1.54 (MOSI2/PB15); also elsewhere on the board
PC0: R1.1, U1.15 (SCL3/PC0); also elsewhere on the board
PC1: R2.1, U1.16 (SDA3/PC1); also elsewhere on the board
PC4: U1.33 (USART3-TX/PC4); also elsewhere on the board
PC5: U1.34 (UISART3-RX/PC5); also elsewhere on the board
PC10: TP43.TP, U1.78 (SCK3/PC10); also elsewhere on the board
PC11: TP41.TP, U1.79 (MISO3/PC11)
PC12: TP42.TP, U1.80 (MOSI3/PC12)
PD3: U1.84 (SCK2/PD3); also elsewhere on the board
PD4: U1.85 (PD4); also elsewhere on the board
PE0: TP39.TP, U1.97 (PE0)
PE1: TP38.TP, U1.98 (PE1)
PE2: U1.1 (PE2); also elsewhere on the board
PE3: U1.2 (PE3); also elsewhere on the board
PE4: U1.3 (PE4); also elsewhere on the board
PE5: U1.4 (PE5); also elsewhere on the board
PE6: U1.5 (PE6); also elsewhere on the board
PE7: TP45.TP, U1.38 (PE7)
PE8: TP40.TP, U1.39 (PE8)
PE9: U1.40 (PE9); also elsewhere on the board
PE10: U1.41 (PE10); also elsewhere on the board
PE11: TP8.TP, U1.42 (PE11)
PE12: TP9.TP, U1.43 (PE12)
PE13: U1.44 (PE13); also elsewhere on the board
PE14: U1.45 (PE14); also elsewhere on the board
PE15: U1.46 (PE15); also elsewhere on the board
SD_CS: U1.83 (PD2); also elsewhere on the board
TGT_NRST: U1.14 (NRST); also elsewhere on the board
TGT_RX: U1.69 (TGT_RX/PA10); also elsewhere on the board
TGT_SWCLK: U1.76 (SWCLK/PA14); also elsewhere on the board
TGT_SWDIO: U1.72 (SWDIO/PA13); also elsewhere on the board
TGT_SWO: U1.89 (SWO/PB3); also elsewhere on the board
TGT_TX: U1.68 (TGT_TX/PA9); also elsewhere on the board

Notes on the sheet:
MCU Power, Clock, GPIO

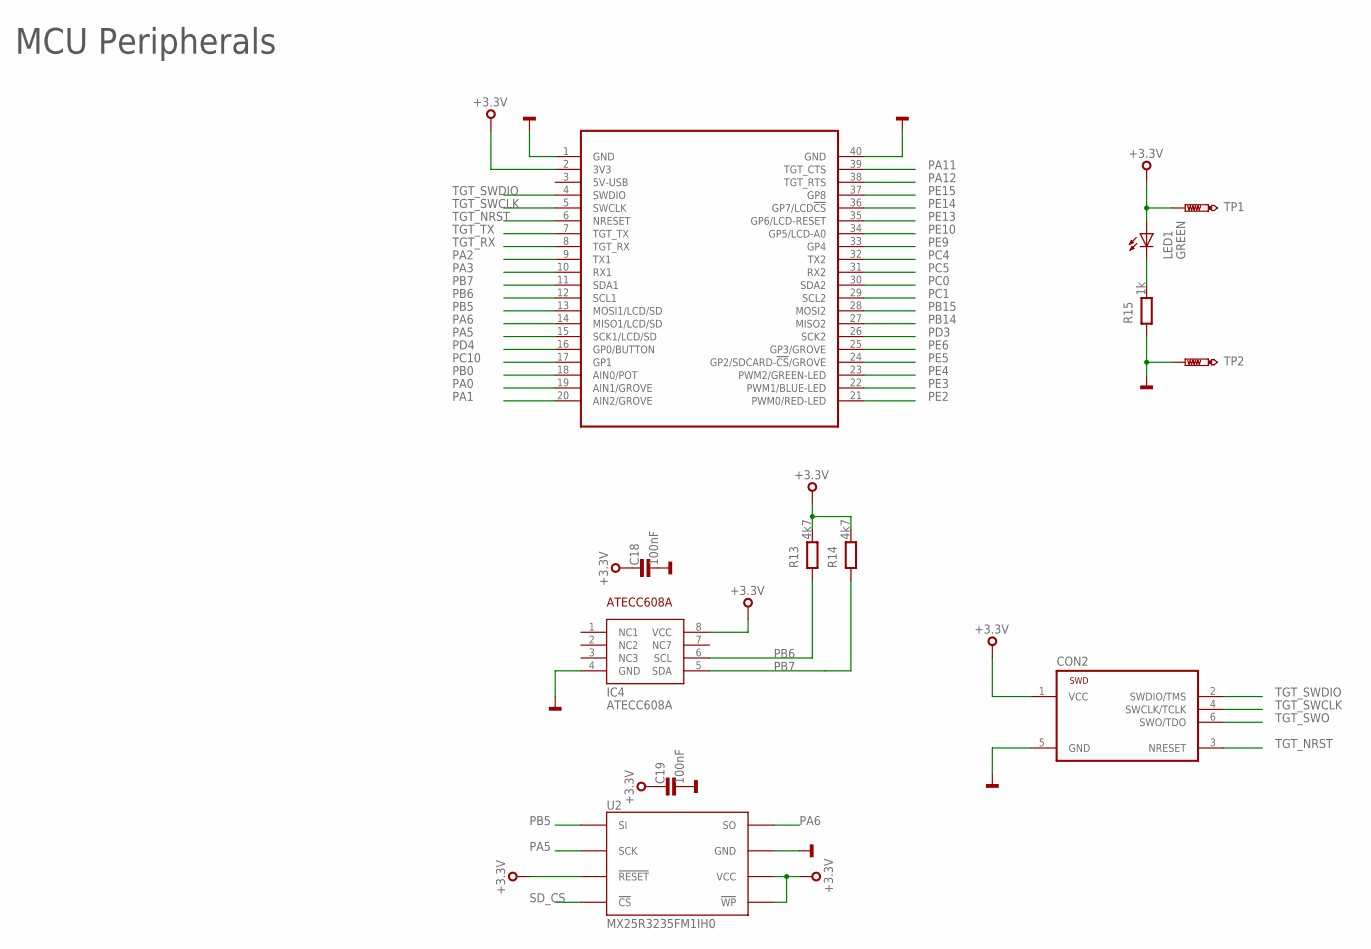
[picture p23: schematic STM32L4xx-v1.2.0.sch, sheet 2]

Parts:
C18, C19: 100nF; 0402
CON2: TC2030-CTX-NL
IC4: ATECC608A; SO8
LED1: GREEN; CHIPLED_0603
MOD1: MODULE_DAUGHTER
R13, R14: 4k7; 0402
R15: 1k; 0603
TP1, TP2: TEST_POINT-50R-PTH; TP50-PTH
U2: MX25R3235FM1IH0; SO8

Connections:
+3.3V: C18.1, C19.1, CON2.1 (VCC), IC4.8 (VCC), LED1.A, MOD1.2 (3V3), R13.2, R14.2, TP1.TP, U2.3 (!WP), U2.7 (!RESET), U2.8 (VCC); also elsewhere on the board
GND: C18.2, C19.2, CON2.5 (GND), IC4.4 (GND), MOD1.1 (GND), MOD1.40 (GND), R15.1, TP2.TP, U2.4 (GND); also elsewhere on the board
PA0: MOD1.19 (AIN1/GROVE); also elsewhere on the board
PA1: MOD1.20 (AIN2/GROVE); also elsewhere on the board
PA2: MOD1.9 (TX1); also elsewhere on the board
PA3: MOD1.10 (RX1); also elsewhere on the board
PA5: MOD1.15 (SCK1/LCD/SD), U2.6 (SCK); also elsewhere on the board
PA6: MOD1.14 (MISO1/LCD/SD), U2.2 (SO); also elsewhere on the board
PA11: MOD1.39 (TGT_CTS); also elsewhere on the board
PA12: MOD1.38 (TGT_RTS); also elsewhere on the board
PA_1: LED1.C, R15.2
PB0: MOD1.18 (AIN0/POT); also elsewhere on the board
PB5: MOD1.13 (MOSI1/LCD/SD), U2.5 (SI); also elsewhere on the board
PB6: IC4.6 (SCL), MOD1.12 (SCL1), R13.1; also elsewhere on the board
PB7: IC4.5 (SDA), MOD1.11 (SDA1), R14.1; also elsewhere on the board
PB14: MOD1.27 (MISO2); also elsewhere on the board
PB15: MOD1.28 (MOSI2); also elsewhere on the board
PC0: MOD1.30 (SDA2); also elsewhere on the board
PC1: MOD1.29 (SCL2); also elsewhere on the board
PC4: MOD1.32 (TX2); also elsewhere on the board
PC5: MOD1.31 (RX2); also elsewhere on the board
PC10: MOD1.17 (GP1); also elsewhere on the board
PD3: MOD1.26 (SCK2); also elsewhere on the board
PD4: MOD1.16 (GP0/BUTTON); also elsewhere on the board
PE2: MOD1.21 (PWM0/RED-LED); also elsewhere on the board
PE3: MOD1.22 (PWM1/BLUE-LED); also elsewhere on the board
PE4: MOD1.23 (PWM2/GREEN-LED); also elsewhere on the board
PE5: MOD1.24 (GP2/SDCARD-!CS!/GROVE); also elsewhere on the board
PE6: MOD1.25 (GP3/GROVE); also elsewhere on the board
PE9: MOD1.33 (GP4); also elsewhere on the board
PE10: MOD1.34 (GP5/LCD-A0); also elsewhere on the board
PE13: MOD1.35 (GP6/LCD-RESET); also elsewhere on the board
PE14: MOD1.36 (GP7/LCD!CS); also elsewhere on the board
PE15: MOD1.37 (GP8); also elsewhere on the board
SD_CS: U2.1 (!CS); also elsewhere on the board
TGT_NRST: CON2.3 (NRESET), MOD1.6 (NRESET); also elsewhere on the board
TGT_RX: MOD1.8 (TGT_RX); also elsewhere on the board
TGT_SWCLK: CON2.4 (SWCLK/TCLK), MOD1.5 (SWCLK); also elsewhere on the board
TGT_SWDIO: CON2.2 (SWDIO/TMS), MOD1.4 (SWDIO); also elsewhere on the board
TGT_SWO: CON2.6 (SWO/TDO); also elsewhere on the board
TGT_TX: MOD1.7 (TGT_TX); also elsewhere on the board

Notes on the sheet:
MCU Peripherals

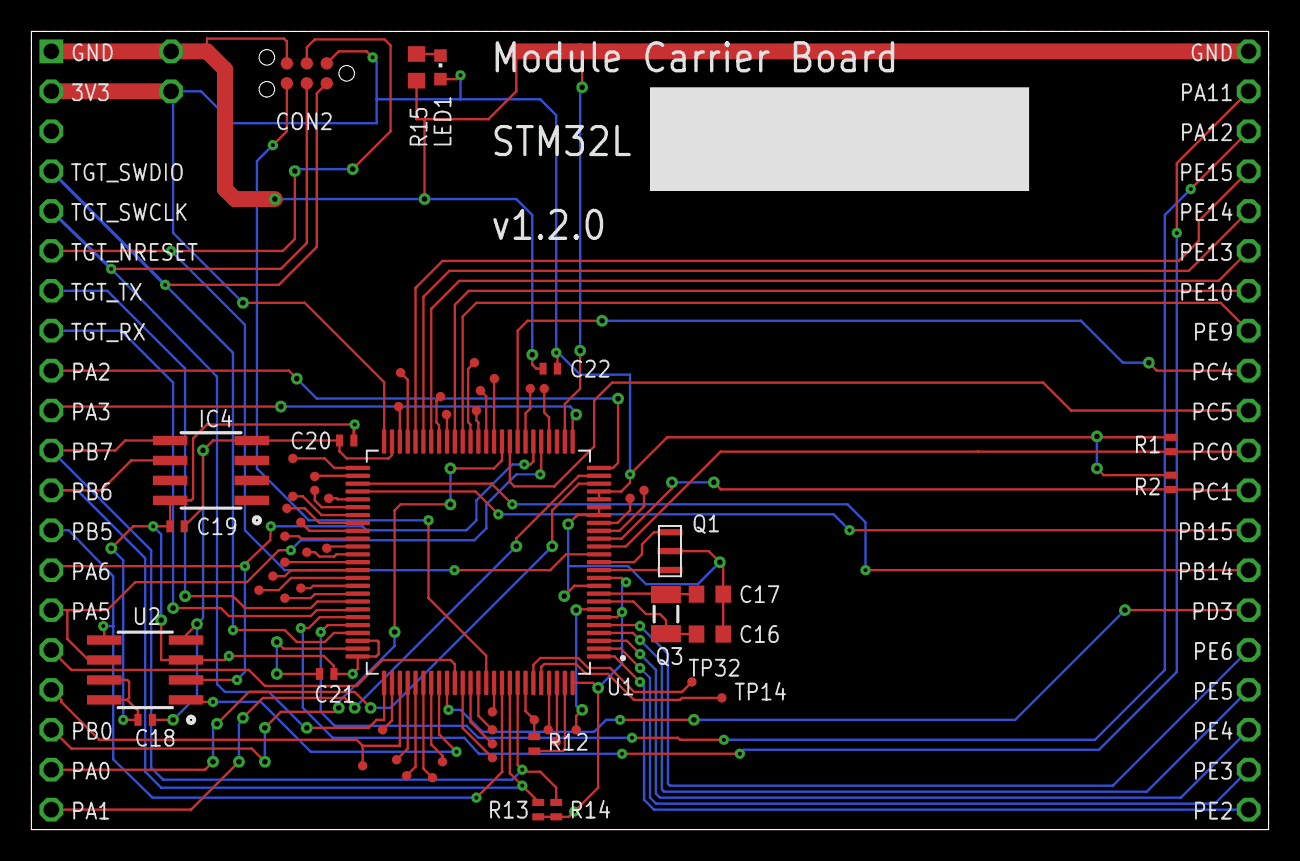
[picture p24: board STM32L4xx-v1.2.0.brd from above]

Board: 2 copper layers, 78.7 x 50.8 mm, 66 parts (0 on the bottom side), 87 nets.

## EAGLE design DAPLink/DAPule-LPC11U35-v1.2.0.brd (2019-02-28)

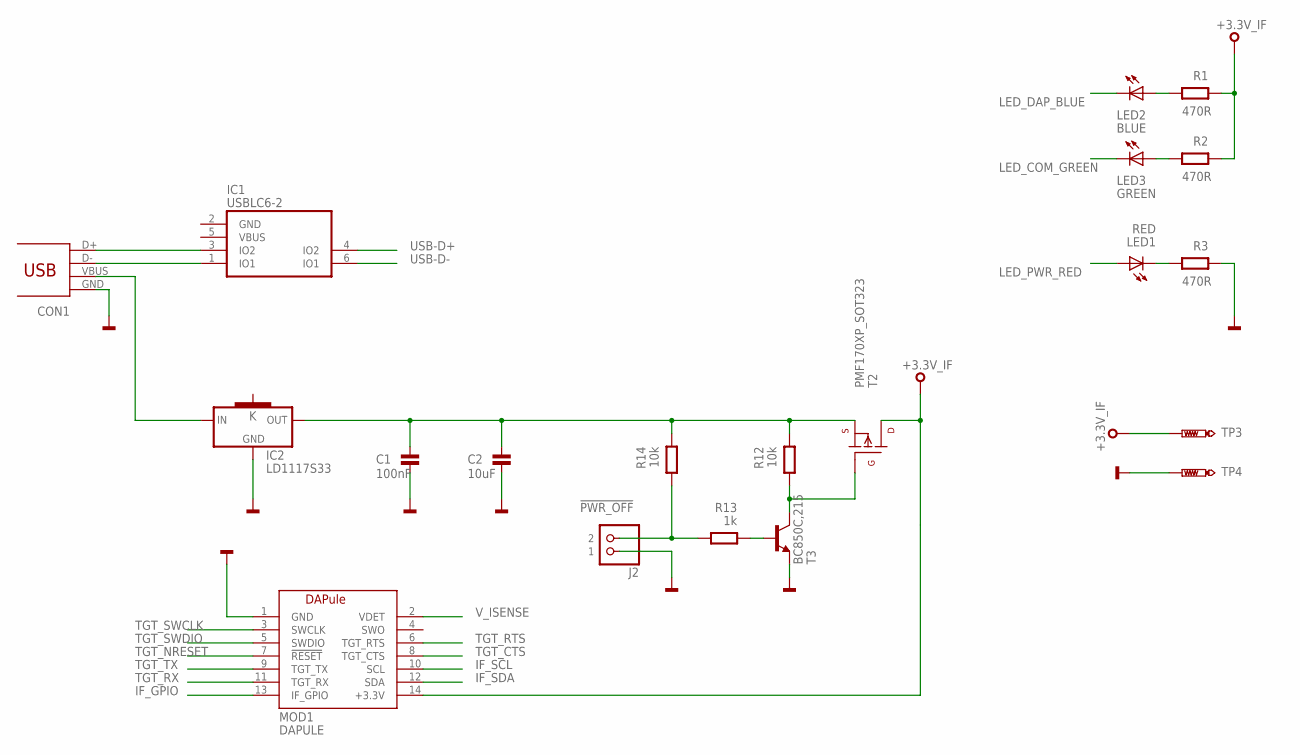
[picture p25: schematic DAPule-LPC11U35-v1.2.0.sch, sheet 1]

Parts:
C1: 100nF; 0603
C2: 10uF; 0603
CON1: USB_MICROB; MOLEX-47364-0001
IC1: USBLC6-2SC6; SOT23-6L
IC2: LD1117S33; SOT223
J2: PINHD-1X2; 1X02
LED1: RED; CHIPLED_0603
LED2: BLUE; CHIPLED_0603
LED3: GREEN; CHIPLED_0603
MOD1: DAPULE
R1, R2, R3: 470R; 0603@1
R12, R14: 10k; 0603@1
R13: 1k; 0603@1
T2: PMF170XP_SOT323; SOT323-BEC
T3: BC850C,215; SOT23-3
TP3, TP4: TEST-POINT-50R-PTH; TP50-PTH

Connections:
!PWR_OFF: J2.2, R13.2, R14.2
+3.3V_IF: MOD1.14 (+3.3V), R1.1, R2.1, T2.C (D), TP3.TP; also elsewhere on the board
GND: C1.2, C2.2, CON1.GND, IC2.1 (GND), J2.1, MOD1.1 (GND), R3.1, T3.2 (E), TP4.TP; also elsewhere on the board
IF_GPIO: MOD1.13 (IF_GPIO); also elsewhere on the board
IF_SCL: MOD1.10 (SCL); also elsewhere on the board
IF_SDA: MOD1.12 (SDA); also elsewhere on the board
LED_COM_GREEN: LED3.C; also elsewhere on the board
LED_DAP_BLUE: LED2.C; also elsewhere on the board
LED_PWR_RED: LED1.A; also elsewhere on the board
unnamed: LED3.A, R2.2
unnamed: CON1.D-, IC1.1 (IO1)
unnamed: CON1.D+, IC1.3 (IO2)
unnamed: LED2.A, R1.2
unnamed: C1.1, C2.1, IC2.2 (OUT), R12.1, R14.1, T2.E (S)
unnamed: LED1.C, R3.2
unnamed: CON1.VBUS, IC2.3 (IN)
unnamed: R13.1, T3.1 (B)
unnamed: R12.2, T2.B (G), T3.3 (C)
TGT_CTS: MOD1.8 (TGT_CTS); also elsewhere on the board
TGT_NRESET: MOD1.7 (!RESET); also elsewhere on the board
TGT_RTS: MOD1.6 (TGT_RTS); also elsewhere on the board
TGT_RX: MOD1.11 (TGT_RX); also elsewhere on the board
TGT_SWCLK: MOD1.3 (SWCLK); also elsewhere on the board
TGT_SWDIO: MOD1.5 (SWDIO); also elsewhere on the board
TGT_TX: MOD1.9 (TGT_TX); also elsewhere on the board
USB-D+: IC1.4 (IO2); also elsewhere on the board
USB-D-: IC1.6 (IO1); also elsewhere on the board
V_ISENSE: MOD1.2 (VDET); also elsewhere on the board

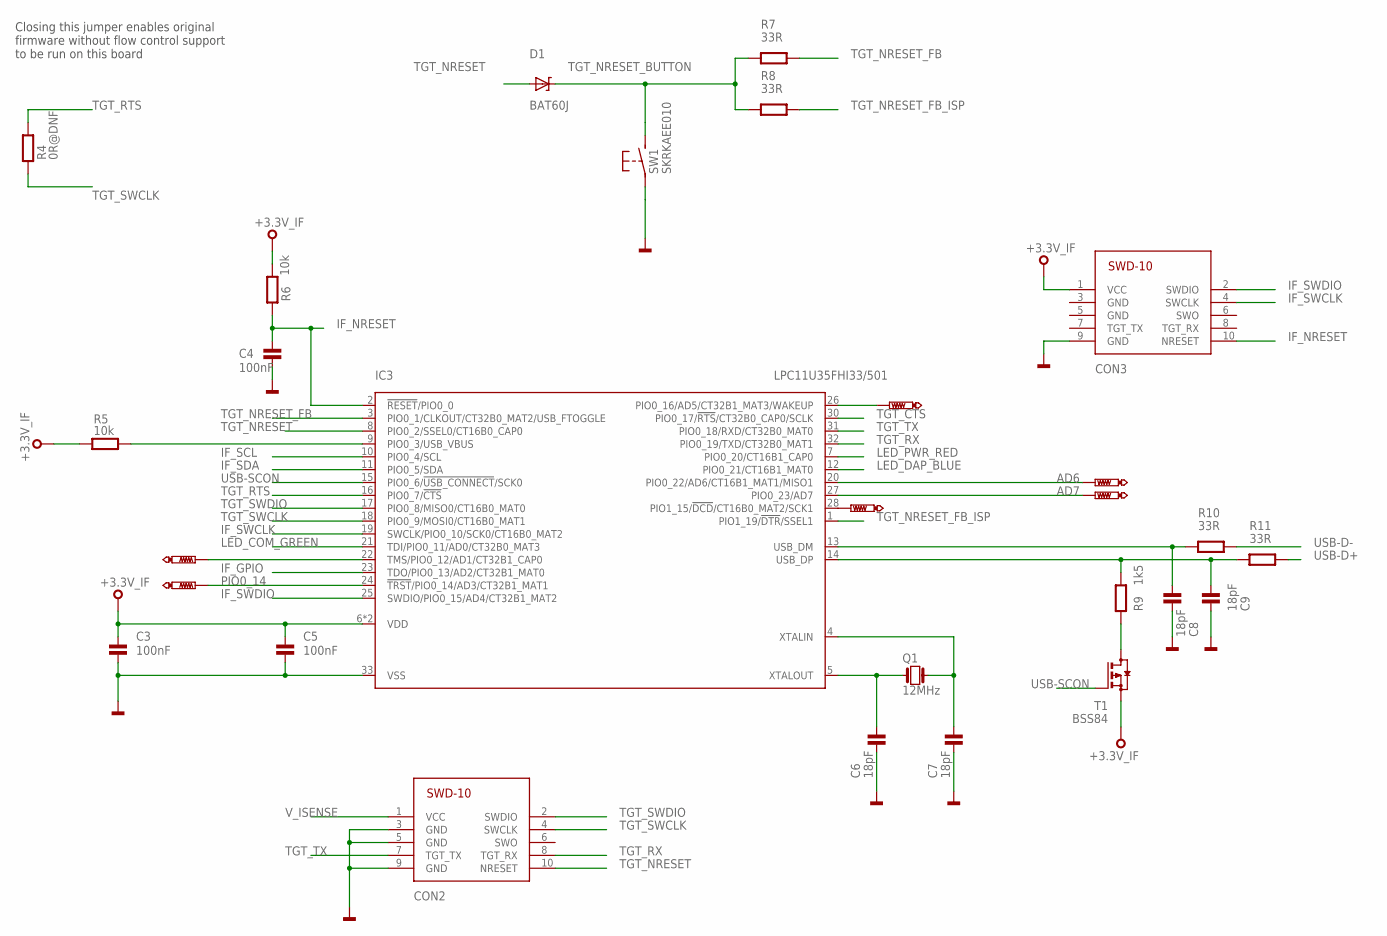
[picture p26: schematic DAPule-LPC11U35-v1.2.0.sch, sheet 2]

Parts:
C3, C4, C5: 100nF; 0603
C6, C7, C8, C9: 18pF; 0603
CON2, CON3: SWD-10/TC2050_SMD; FTSH-105-02
D1: BAT60J; SOD323
IC3: LPC11U35FHI33/501; SOT617-3
Q1: 12MHz; 3.2X.2.5
R4: 0R@DNF; 0402@1
R5, R6: 10k; 0603@1
R7, R8, R10, R11: 33R; 0603@1
R9: 1k5; 0603@1
SW1: SKRKAEE010
T1: BSS84; SOT23
TP1, TP2, TP5, TP8, TP9, TP13: PTR1TP07R; TP07R

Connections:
+3.3V_IF: C3.1, C5.1, CON3.1 (VCC), IC3.6 (VDD), IC3.29 (VDD), R5.2, R6.2, T1.2 (S); also elsewhere on the board
AD6: IC3.20 (PIO0_22/AD6/CT16B1_MAT1/MISO1), TP9.TP
AD7: IC3.27 (PIO0_23/AD7), TP8.TP
GND: C3.2, C4.2, C5.2, C6.2, C7.2, C8.2, C9.2, CON2.3 (GND), CON2.5 (GND), CON2.9 (GND), CON3.9 (GND), IC3.33 (VSS), SW1.P$1; also elsewhere on the board
IF_GPIO: IC3.23 (TDO/PIO0_13/AD2/CT32B1_MAT0); also elsewhere on the board
IF_NRESET: C4.1, CON3.10 (NRESET), IC3.2 (!RESET!/PIO0_0), R6.1
IF_SCL: IC3.10 (PIO0_4/SCL); also elsewhere on the board
IF_SDA: IC3.11 (PIO0_5/SDA); also elsewhere on the board
IF_SWCLK: CON3.4 (SWCLK), IC3.19 (SWCLK/PIO0_10/SCK0/CT16B0_MAT2)
IF_SWDIO: CON3.2 (SWDIO), IC3.25 (SWDIO/PIO0_15/AD4/CT32B1_MAT2)
LED_COM_GREEN: IC3.21 (TDI/PIO0_11/AD0/CT32B0_MAT3); also elsewhere on the board
LED_DAP_BLUE: IC3.12 (PIO0_21/CT16B1_MAT0); also elsewhere on the board
LED_PWR_RED: IC3.7 (PIO0_20/CT16B1_CAP0); also elsewhere on the board
unnamed: IC3.22 (TMS/PIO0_12/AD1/CT32B1_CAP0), TP1.TP
unnamed: IC3.26 (PIO0_16/AD5/CT32B1_MAT3/WAKEUP), TP2.TP
unnamed: IC3.28 (PIO1_15/!DCD!/CT16B0_MAT2/SCK1), TP5.TP
unnamed: C6.1, IC3.5 (XTALOUT), Q1.P$1 (1)
unnamed: C7.1, IC3.4 (XTALIN), Q1.P$3 (2)
unnamed: IC3.9 (PIO0_3/USB_VBUS), R5.1
unnamed: R9.1, T1.3 (D)
PIO0_14: IC3.24 (!TRST!/PIO0_14/AD3/CT32B1_MAT1), TP13.TP
TGT_CTS: IC3.30 (PIO0_17/!RTS!/CT32B0_CAP0/SCLK); also elsewhere on the board
TGT_NRESET: CON2.10 (NRESET), D1.A, IC3.8 (PIO0_2/SSEL0/CT16B0_CAP0); also elsewhere on the board
TGT_NRESET_BUTTON: D1.K, R7.2, R8.2, SW1.P$2 (S)
TGT_NRESET_FB: IC3.3 (PIO0_1/CLKOUT/CT32B0_MAT2/USB_FTOGGLE), R7.1
TGT_NRESET_FB_ISP: IC3.1 (PIO1_19/!DTR!/SSEL1), R8.1
TGT_RTS: IC3.16 (PIO0_7/!CTS!), R4.2; also elsewhere on the board
TGT_RX: CON2.8 (TGT_RX), IC3.32 (PIO0_19/TXD/CT32B0_MAT1); also elsewhere on the board
TGT_SWCLK: CON2.4 (SWCLK), IC3.18 (PIO0_9/MOSI0/CT16B0_MAT1), R4.1; also elsewhere on the board
TGT_SWDIO: CON2.2 (SWDIO), IC3.17 (PIO0_8/MISO0/CT16B0_MAT0); also elsewhere on the board
TGT_TX: CON2.7 (TGT_TX), IC3.31 (PIO0_18/RXD/CT32B0_MAT0); also elsewhere on the board
USB-D+: R11.1; also elsewhere on the board
USB-D-: R10.1; also elsewhere on the board
USB-SCON: IC3.15 (PIO0_6/!USB_CONNECT!/SCK0), T1.1 (G)
USB_DM: C8.1, IC3.13 (USB_DM), R10.2
USB_DP: C9.1, IC3.14 (USB_DP), R9.2, R11.2
V_ISENSE: CON2.1 (VCC); also elsewhere on the board

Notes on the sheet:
Closing this jumper enables original firmware without flow control support to be run on this board

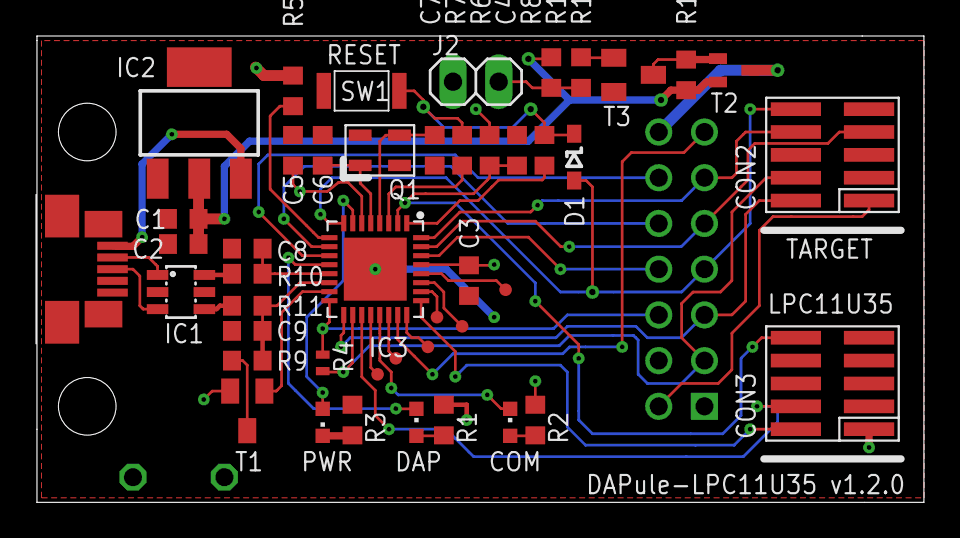
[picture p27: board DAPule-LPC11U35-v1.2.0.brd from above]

Board: 2 copper layers, 49.3 x 25.9 mm, 48 parts (0 on the bottom side), 47 nets.

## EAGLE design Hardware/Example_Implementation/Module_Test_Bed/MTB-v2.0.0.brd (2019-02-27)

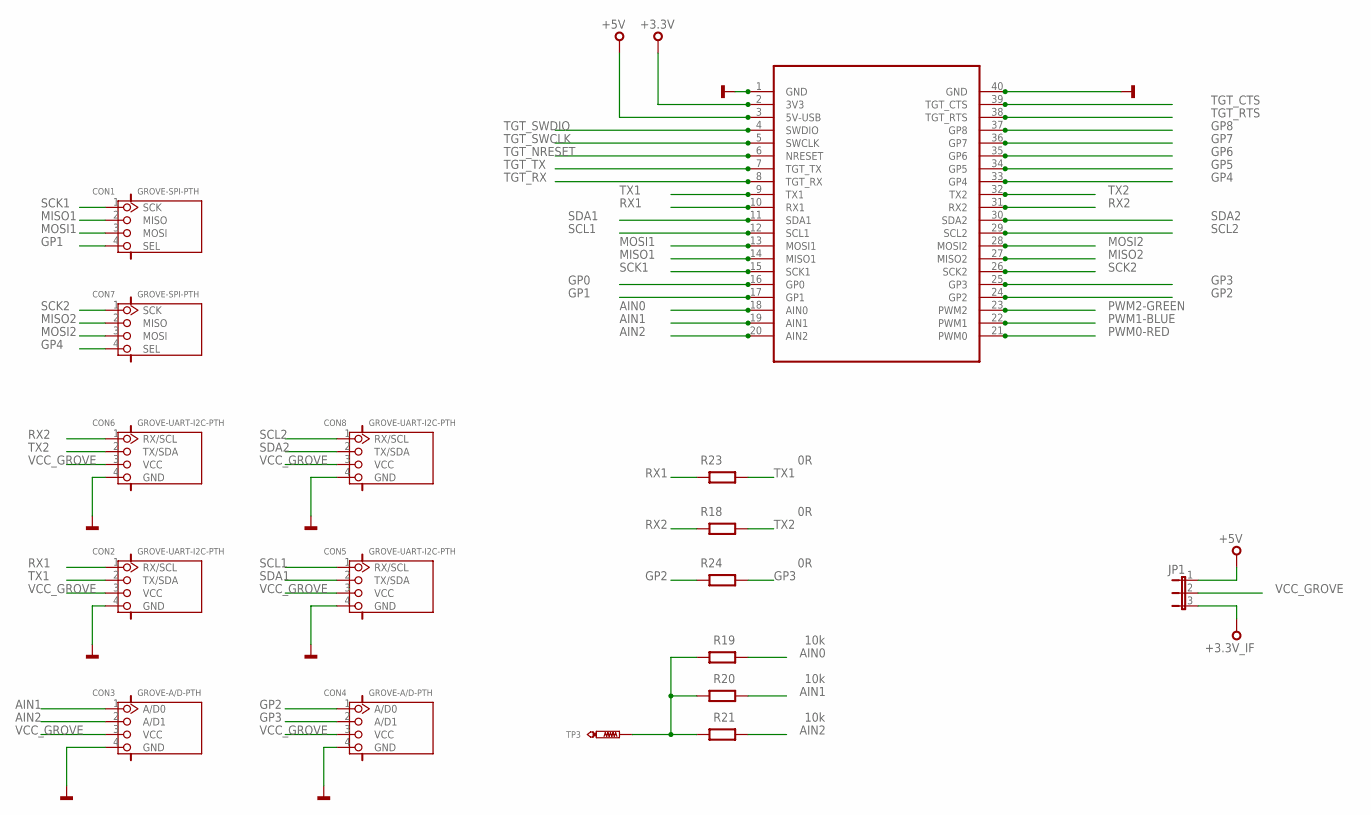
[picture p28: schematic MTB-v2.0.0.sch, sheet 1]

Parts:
CON1, CON7: GROVE-SPI-PTH; HW4-2.0
CON2, CON5, CON6, CON8: GROVE-UART-I2C-PTH; HW4-2.0
CON3, CON4: GROVE-A/D-PTH; HW4-2.0
JP1: JP2E; JP2
R18, R23, R24: 0R; 0603@1
R19, R20, R21: 10k; 0603@1
SKT1: MODULE_SOCKET
TP3: TEST-POINT-50R-PTH; TP50-PTH

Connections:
+3.3V: SKT1.2 (3V3), SKT1.P$42; also elsewhere on the board
+3.3V_IF: JP1.3; also elsewhere on the board
+5V: JP1.1, SKT1.3 (5V-USB), SKT1.P$43; also elsewhere on the board
AIN0: R19.1, SKT1.18 (AIN0), SKT1.P$58; also elsewhere on the board
AIN1: CON3.1 (A/D0), R20.1, SKT1.19 (AIN1), SKT1.P$59
AIN2: CON3.2 (A/D1), R21.1, SKT1.20 (AIN2), SKT1.P$60
GND: CON2.4 (GND), CON3.4 (GND), CON4.4 (GND), CON5.4 (GND), CON6.4 (GND), CON8.4 (GND), SKT1.1 (GND), SKT1.40 (GND), SKT1.P$41, SKT1.P$80; also elsewhere on the board
GP0: SKT1.16 (GP0), SKT1.P$56; also elsewhere on the board
GP1: CON1.4 (SEL), SKT1.17 (GP1), SKT1.P$57
GP2: CON4.1 (A/D0), R24.2, SKT1.24 (GP2), SKT1.P$64; also elsewhere on the board
GP3: CON4.2 (A/D1), R24.1, SKT1.25 (GP3), SKT1.P$65
GP4: CON7.4 (SEL), SKT1.33 (GP4), SKT1.P$73
GP5: SKT1.34 (GP5), SKT1.P$74; also elsewhere on the board
GP6: SKT1.35 (GP6), SKT1.P$75; also elsewhere on the board
GP7: SKT1.36 (GP7), SKT1.P$76; also elsewhere on the board
GP8: SKT1.37 (GP8), SKT1.P$77
MISO1: CON1.2 (MISO), SKT1.14 (MISO1), SKT1.P$54; also elsewhere on the board
MISO2: CON7.2 (MISO), SKT1.27 (MISO2), SKT1.P$67
MOSI1: CON1.3 (MOSI), SKT1.13 (MOSI1), SKT1.P$53; also elsewhere on the board
MOSI2: CON7.3 (MOSI), SKT1.28 (MOSI2), SKT1.P$68
unnamed: R19.2, R20.2, R21.2, TP3.TP
PWM0-RED: SKT1.21 (PWM0), SKT1.P$61; also elsewhere on the board
PWM1-BLUE: SKT1.22 (PWM1), SKT1.P$62; also elsewhere on the board
PWM2-GREEN: SKT1.23 (PWM2), SKT1.P$63; also elsewhere on the board
RX1: CON2.1 (RX/SCL), R23.2, SKT1.10 (RX1), SKT1.P$50
RX2: CON6.1 (RX/SCL), R18.2, SKT1.31 (RX2), SKT1.P$71
SCK1: CON1.1 (SCK), SKT1.15 (SCK1), SKT1.P$55; also elsewhere on the board
SCK2: CON7.1 (SCK), SKT1.26 (SCK2), SKT1.P$66
SCL1: CON5.1 (RX/SCL), SKT1.12 (SCL1), SKT1.P$52; also elsewhere on the board
SCL2: CON8.1 (RX/SCL), SKT1.29 (SCL2), SKT1.P$69; also elsewhere on the board
SDA1: CON5.2 (TX/SDA), SKT1.11 (SDA1), SKT1.P$51; also elsewhere on the board
SDA2: CON8.2 (TX/SDA), SKT1.30 (SDA2), SKT1.P$70; also elsewhere on the board
TGT_CTS: SKT1.39 (TGT_CTS), SKT1.P$79; also elsewhere on the board
TGT_NRESET: SKT1.6 (NRESET), SKT1.P$46; also elsewhere on the board
TGT_RTS: SKT1.38 (TGT_RTS), SKT1.P$78; also elsewhere on the board
TGT_RX: SKT1.8 (TGT_RX), SKT1.P$48; also elsewhere on the board
TGT_SWCLK: SKT1.5 (SWCLK), SKT1.P$45; also elsewhere on the board
TGT_SWDIO: SKT1.4 (SWDIO), SKT1.P$44; also elsewhere on the board
TGT_TX: SKT1.7 (TGT_TX), SKT1.P$47; also elsewhere on the board
TX1: CON2.2 (TX/SDA), R23.1, SKT1.9 (TX1), SKT1.P$49
TX2: CON6.2 (TX/SDA), R18.1, SKT1.32 (TX2), SKT1.P$72
VCC_GROVE: CON2.3 (VCC), CON3.3 (VCC), CON4.3 (VCC), CON5.3 (VCC), CON6.3 (VCC), CON8.3 (VCC), JP1.2


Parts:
C1, C3, C4: 100nF; 0603
C2: 10uF; SMC_B
C5: 10uF; SMC_A
CON12: FC68148S
D2, D3: BAT60A; SOD323
IC2: LD1117S33; SOT223
JP3: PINHD-1X2; 1X02
LED1: GREEN; CHIPLED_0603
MOD1: DAPULE
R1, R2, R27, R29: 10k; 0603@1
R3: 1R@1%; 0603
R4, R5: 4k7; 0603@1
R6, R7: 0R; 0603@1
R8: 1k; 0603
R26: 1k; 0603@1
SW3: JS202011JCQN
T2: BC850; SOT23
T3: P-FET_PMF170XP; SOT23-BEC
TP1, TP2, TP4, TP5, TP6, TP7, TP8, TP9: TEST-POINT-50R-PTH; TP50-PTH
U5: INA219AIDCNR; SOT23-8

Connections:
!PWR_OFF: JP3.2, MOD1.13 (IF_GPIO), R26.2, R27.2
+3.3V: R2.2, R3.1; also elsewhere on the board
+3.3V_IF: LED1.A, R1.2, R3.2, R4.1, R5.1, SW3.1, TP1.TP, TP4.TP, TP5.TP, TP6.TP; also elsewhere on the board
+5V: C3.2, C5.+, CON12.1-1 (PWR), CON12.1-2 (PWR), IC2.3 (IN), U5.4 (VCC); also elsewhere on the board
GND: C1.2, C2.-, C3.1, C5.-, CON12.3 (GND), IC2.1 (GND), JP3.1, MOD1.1 (GND), R8.1, T2.2 (E), TP2.TP, TP7.TP, TP8.TP, TP9.TP, U5.3 (GND), U5.7 (A0), U5.8 (A1); also elsewhere on the board
IF_SCL: MOD1.10 (SCL), R5.2, R7.2, U5.5 (SCL)
IF_SDA: MOD1.12 (SDA), R4.2, R6.2, U5.6 (SDA)
unnamed: C4.2, R2.1, U5.2 (VIN-)
unnamed: C4.1, R1.1, U5.1 (VIN+)
unnamed: D2.A, MOD1.14 (+3.3V)
unnamed: C1.1, C2.+, D3.A, IC2.2 (OUT)
unnamed: D2.K, D3.K, R27.1, R29.1, T3.E (S)
unnamed: R26.1, T2.1 (B)
unnamed: SW3.2, T3.C (D)
unnamed: R29.2, T2.3 (C), T3.B (G)
PA_1: LED1.C, R8.2
SCL: R7.1; also elsewhere on the board
SDA: R6.1; also elsewhere on the board
TGT_CTS: MOD1.8 (TGT_CTS); also elsewhere on the board
TGT_NRESET: MOD1.7 (!RESET); also elsewhere on the board
TGT_RTS: MOD1.6 (TGT_RTS); also elsewhere on the board
TGT_RX: MOD1.11 (TGT_RX); also elsewhere on the board
TGT_SWCLK: MOD1.3 (SWCLK); also elsewhere on the board
TGT_SWDIO: MOD1.5 (SWDIO); also elsewhere on the board
TGT_TX: MOD1.9 (TGT_TX); also elsewhere on the board


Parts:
C10, C11, C12, C13, C14, C15, C16, C17, C18, C19, C20: 100nF; 0603
CON10: MICRO-SD; AMPHENOL-101-00660-68-6
IC4: LM75BD_TSSOP8; TSSOP8
IC5: AT24LCXXXEIAJ; SO08-EIAJ
JP4: PINHD-2X3; 2X03
LCD1: C12832A1Z
LED4: RED; CHIPLED_0603
LED5: BLUE; CHIPLED_0603
LED6: GREEN; CHIPLED_0603
R11, R12, R13: 1k; 0603
R14, R15: 4k7; 0603
R16: 10k; 0603
R17: 220R; 0603
R22: 0R; 0603
SW2: SPST-4_TP1154_J; TP-1154X
VR1: ISKRA_PNZ; CA14V

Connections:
+3.3V_IF: C10.1, C19.1, C20.1, CON10.4 (VCC), IC4.8 (VCC), IC5.8 (VCC), LCD1.P$12 (VDD), LED4.A, LED5.A, LED6.A, R14.2, R15.2, R17.1, SW2.B1, SW2.B2, VR1.P$3 (E); also elsewhere on the board
AIN0: R22.2; also elsewhere on the board
GND: C10.2, C11.2, C12.2, C13.2, C14.2, C15.2, C18.2, C19.2, C20.2, CON10.6 (GND), CON10.G1 (SHIELD), CON10.G2 (SHEILD), CON10.G3 (SHIELD), IC4.4 (GND), IC4.5 (A2), IC4.6 (A1), IC4.7 (A0), IC5.1 (A0), IC5.2 (A1), IC5.3 (A2), IC5.4 (VSS), LCD1.K, LCD1.P$11 (VSS), R16.2, VR1.P$1 (A); also elsewhere on the board
GP0: R16.1, SW2.A1, SW2.A2; also elsewhere on the board
GP2: CON10.2 (NCS); also elsewhere on the board
GP5: LCD1.P$15 (A0); also elsewhere on the board
GP6: LCD1.P$16 (RST); also elsewhere on the board
GP7: LCD1.P$17 (CS1B); also elsewhere on the board
MISO1: CON10.7 (MISO); also elsewhere on the board
MOSI1: CON10.3 (MOSI), LCD1.P$13 (SDA); also elsewhere on the board
unnamed: C16.1, LCD1.P$9 (C1-)
unnamed: C17.1, LCD1.P$7 (C2+)
unnamed: C17.2, LCD1.P$6 (C2-)
unnamed: C16.2, LCD1.P$8 (C1+)
unnamed: C11.1, LCD1.P$1 (V0)
unnamed: C12.1, LCD1.P$2 (V1)
unnamed: C13.1, LCD1.P$3 (V2)
unnamed: C14.1, LCD1.P$4 (V3)
unnamed: C15.1, LCD1.P$5 (V4)
unnamed: C18.1, LCD1.P$10 (VOUT)
unnamed: LED4.C, R11.2
unnamed: LED6.C, R13.2
unnamed: LED5.C, R12.2
unnamed: LCD1.A, R17.2
unnamed: R22.1, VR1.P$2 (S)
PWM0-RED: R11.1; also elsewhere on the board
PWM1-BLUE: R12.1; also elsewhere on the board
PWM2-GREEN: R13.1; also elsewhere on the board
SCK1: CON10.5 (SCK), LCD1.P$14 (SCL); also elsewhere on the board
SCL: IC4.2 (SCL), IC5.6 (SCL), JP4.4, R15.1; also elsewhere on the board
SCL1: JP4.2; also elsewhere on the board
SCL2: JP4.6; also elsewhere on the board
SDA: IC4.1 (SDA), IC5.5 (SDA), JP4.3, R14.1; also elsewhere on the board
SDA1: JP4.1; also elsewhere on the board
SDA2: JP4.5; also elsewhere on the board

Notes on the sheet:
These are all 1uF MLCC



Board: 2 copper layers, 109.7 x 125.7 mm, 81 parts (2 on the bottom side), 71 nets.

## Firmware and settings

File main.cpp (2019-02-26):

// ----------------------------------------------------------------------------
// Copyright 2016-2018 ARM Ltd.
//
// SPDX-License-Identifier: Apache-2.0
//
// Licensed under the Apache License, Version 2.0 (the "License");
// you may not use this file except in compliance with the License.
// You may obtain a copy of the License at
//
//     http://www.apache.org/licenses/LICENSE-2.0
//
// Unless required by applicable law or agreed to in writing, software
// distributed under the License is distributed on an "AS IS" BASIS,
// WITHOUT WARRANTIES OR CONDITIONS OF ANY KIND, either express or implied.
// See the License for the specific language governing permissions and
// limitations under the License.
// ----------------------------------------------------------------------------
#ifndef MBED_TEST_MODE

#include "mbed.h"
#include "simple-mbed-cloud-client.h"
//#include "FATFileSystem.h"
#include "LittleFileSystem.h"

DigitalOut modem_power_on(PE_15);

// An event queue is a very useful structure to debounce information between contexts (e.g. ISR and normal threads)
// This is great because things such as network operations are illegal in ISR, so updating a resource in a button's fall() function is not allowed
EventQueue eventQueue;

// Default block device
BlockDevice *bd = BlockDevice::get_default_instance();
//FATFileSystem fs("fs");
LittleFileSystem fs("fs", bd);


// Default network interface object
NetworkInterface *net = NetworkInterface::get_default_instance();

// Declaring pointers for access to Pelion Device Management Client resources outside of main()
MbedCloudClientResource *button_res;
MbedCloudClientResource *pattern_res;

// This function gets triggered by the timer. It's easy to replace it by an InterruptIn and fall() mode on a real button
void fake_button_press() {
    int v = button_res->get_value_int() + 1;

    button_res->set_value(v);

    printf("Simulated button clicked %d times\n", v);
}

/**
 * PUT handler
 * @param resource The resource that triggered the callback
 * @param newValue Updated value for the resource
 */
void pattern_updated(MbedCloudClientResource *resource, m2m::String newValue) {
    printf("PUT received, new value: %s\n", newValue.c_str());
}

/**
 * POST handler
 * @param resource The resource that triggered the callback
 * @param buffer If a body was passed to the POST function, this contains the data.
 *               Note that the buffer is deallocated after leaving this function, so copy it if you need it longer.
 * @param size Size of the body
 */
void blink_callback(MbedCloudClientResource *resource, const uint8_t *buffer, uint16_t size) {
    printf("POST received. Going to blink LED pattern: %s\n", pattern_res->get_value().c_str());

    static DigitalOut augmentedLed(LED1); // LED that is used for blinking the pattern

    // Parse the pattern string, and toggle the LED in that pattern
    string s = std::string(pattern_res->get_value().c_str());
    size_t i = 0;
    size_t pos = s.find(':');
    while (pos != string::npos) {
        wait_ms(atoi(s.substr(i, pos - i).c_str()));
        augmentedLed = !augmentedLed;

        i = ++pos;
        pos = s.find(':', pos);

        if (pos == string::npos) {
            wait_ms(atoi(s.substr(i, s.length()).c_str()));
            augmentedLed = !augmentedLed;
        }
    }
}

/**
 * Notification callback handler
 * @param resource The resource that triggered the callback
 * @param status The delivery status of the notification
 */
void button_callback(MbedCloudClientResource *resource, const NoticationDeliveryStatus status) {
    printf("Button notification, status %s (%d)\n", MbedCloudClientResource::delivery_status_to_string(status), status);
}

/**
 * Registration callback handler
 * @param endpoint Information about the registered endpoint such as the name (so you can find it back in portal)
 */
void registered(const ConnectorClientEndpointInfo *endpoint) {
    printf("Connected to Pelion Device Management. Endpoint Name: %s\n", endpoint->internal_endpoint_name.c_str());
}

int main(void) {

    printf("Starting Simple Pelion Device Management Client example\n");
    printf("Connecting to the network...\n");

/*
    //Read SPI Flash params
    printf("Init\n");
    int init_status = bd->init();
    printf("Init status = %d\n", init_status);
    if(init_status == 0) {
        printf("spif size: %llu\n",         bd->size());
        printf("spif read size: %llu\n",    bd->get_read_size());
        printf("spif erase size: %llu\n",   bd->get_erase_size());
    }

//Enable this block to check if the application while performing a firmware update
// reads back from the same location on the SPI Flash as that where the bootloader writes 
// it to during the download.
#if 0
    char buffer[296];
    uint32_t address = 2097152;
    uint32_t size = 296;
    bd->read(buffer, address, size);
    for(int i = 232; i<265; i++){
      printf("%x\n", buffer[i]);
    }
#endif

    //Un-comment the below block if forcible flash erase is required. This should not be done in production
    // since every erase will also wipe out the SOTP region & the device will have a new device ID every time
    // it boots / resets.
    printf("Erasing SPIF..\r\n");
    int erase_status = bd->erase(0, bd->size());
    if (erase_status == 0) {
         printf("SPIF erased\n");
    }
    int error =  fs.mount(bd);
    if(error){
      printf("Formatting..\r\n");
      fs.format(bd);
    }
  printf("Mounting Block Device..\r\n");
  int error1 =  fs.mount(bd);
  printf("FS mount error = %lu\r\n", error1);

  //If FS mount fails, abort further operations.
  if (error1 != 0) {
      return -1;
  }
// */

    modem_power_on = 1;

    // Connect to the internet (DHCP is expected to be on)
    nsapi_error_t status = net->connect();

    if (status != NSAPI_ERROR_OK) {
        printf("Connecting to the network failed %d!\n", status);
        return -1;
    }

    printf("Connected to the network successfully. IP address: %s\n", net->get_ip_address());

    /******* Un-comment the line below while demonstrating a FW update.  *******/
    //printf("******** This line demonstrates a FW update ********\r\n");

    // SimpleMbedCloudClient handles registering over LwM2M to Pelion Device Management
    SimpleMbedCloudClient client(net, bd, &fs);
    int client_status = client.init();
    if (client_status != 0) {
        printf("Pelion Client initialization failed (%d)\n", client_status);
        return -1;
    }

    // Creating resources, which can be written or read from the cloud
    button_res = client.create_resource("3200/0/5501", "button_count");
    button_res->set_value(0);
    button_res->methods(M2MMethod::GET);
    button_res->observable(true);
    button_res->attach_notification_callback(button_callback);

    pattern_res = client.create_resource("3201/0/5853", "blink_pattern");
    pattern_res->set_value("500:500:500:500:500:500:500:500");
    pattern_res->methods(M2MMethod::GET | M2MMethod::PUT);
    pattern_res->attach_put_callback(pattern_updated);

    MbedCloudClientResource *blink_res = client.create_resource("3201/0/5850", "blink_action");
    blink_res->methods(M2MMethod::POST);
    blink_res->attach_post_callback(blink_callback);

    printf("Initialized Pelion Client. Registering...\n");

    // Callback that fires when registering is complete
    client.on_registered(&registered);

    // Register with Pelion Device Management
    client.register_and_connect();

    // Placeholder for callback to update local resource when GET comes.
    // The timer fires on an interrupt context, but debounces it to the eventqueue, so it's safe to do network operations
    Ticker timer;
    timer.attach(eventQueue.event(&fake_button_press), 10.0);

    // You can easily run the eventQueue in a separate thread if required
    eventQueue.dispatch_forever();
}
#endif

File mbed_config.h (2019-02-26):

/*
 * mbed SDK
 * Copyright (c) 2017 ARM Limited
 *
 * Licensed under the Apache License, Version 2.0 (the "License");
 * you may not use this file except in compliance with the License.
 * You may obtain a copy of the License at
 *
 * http://www.apache.org/licenses/LICENSE-2.0
 *
 * Unless required by applicable law or agreed to in writing, software
 * distributed under the License is distributed on an "AS IS" BASIS,
 * WITHOUT WARRANTIES OR CONDITIONS OF ANY KIND, either express or implied.
 * See the License for the specific language governing permissions and
 * limitations under the License.
 */

// Automatically generated configuration file.
// DO NOT EDIT, content will be overwritten.

#ifndef __MBED_CONFIG_DATA__
#define __MBED_CONFIG_DATA__

// Configuration parameters
#define ARM_UC_HTTP_RESUME_EXPONENTIATION_FACTOR                              2                                                                                                // set by library:update-client
#define ARM_UC_HTTP_RESUME_INITIAL_DELAY_SECS                                 5                                                                                                // set by library:update-client
#define ARM_UC_HTTP_RESUME_MAXIMUM_DELAY_SECS                                 (60*60)                                                                                          // set by library:update-client
#define ARM_UC_HTTP_RESUME_MAXIMUM_DOWNLOAD_TIME_SECS                         (7*24*60*60)                                                                                     // set by library:update-client
#define ARM_UC_HTTP_RESUME_TEST_MESSAGES_ENABLE                               0                                                                                                // set by library:update-client
#define ARM_UC_MULTI_FRAGS_PER_HTTP_BURST                                     64                                                                                               // set by library:update-client
#define CLOCK_SOURCE                                                          USE_PLL_MSI                                                                                      // set by application[MTB_STM_L475]
#define KVSTORE_ENABLED                                                       1                                                                                                // set by library:kvstore
#define LPTICKER_DELAY_TICKS                                                  1                                                                                                // set by target:FAMILY_STM32
#define MBEDTLS_USER_CONFIG_FILE                                              "mbedTLSConfig_mbedOS.h"                                                                         // set by library:client_app
#define MBED_CONF_APP_DEVELOPER_MODE                                          1                                                                                                // set by application
#define MBED_CONF_APP_FLASH_SIZE                                              (1024*1024)                                                                                      // set by application[MTB_STM_L475]
#define MBED_CONF_APP_FLASH_START_ADDRESS                                     0x08000000                                                                                       // set by application[MTB_STM_L475]
#define MBED_CONF_APP_FORMAT_STORAGE_LAYER_ON_ERROR                           1                                                                                                // set by application
#define MBED_CONF_APP_MAIN_STACK_SIZE                                         6000                                                                                             // set by application
#define MBED_CONF_APP_RADIO_ACCESS_TECHNOLOGY                                 6                                                                                                // set by application
#define MBED_CONF_APP_SOCK_TYPE                                               TCP                                                                                              // set by application
#define MBED_CONF_ATMEL_RF_ASSUME_SPACED_SPI                                  1                                                                                                // set by library:atmel-rf[STM]
#define MBED_CONF_ATMEL_RF_FULL_SPI_SPEED                                     7500000                                                                                          // set by library:atmel-rf
#define MBED_CONF_ATMEL_RF_FULL_SPI_SPEED_BYTE_SPACING                        250                                                                                              // set by library:atmel-rf
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

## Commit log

2019-02-27 Adding Hardware design files
    [MEB-Quectel-BG96-v1.1.0-BOM.xlsx, MEB-Quectel-BG96-v1.1.0.brd, MEB-Quectel-BG96-v1.1.0.sch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]
2019-02-27 Removing redundant BOM files
    [STM32L4xx-v1.1.0-BOM.csv]
2019-02-28 Adding DAPule hardware related files
    [DAPule-LPC11U35-v1.1.0-BOM.xlsx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]
2019-02-28 Adding v1.2.0 hardware files for DAPule
    [DAPule-LPC11U35-v1.1.0-BOM.xlsx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]
2019-03-01 Adding v1.2.0 (& remove v1.1.0) files for MCB & MEB
    [MEB-Quectel-BG96-v1.1.0.sch, MEB-Quectel-BG96-v1.2.0-BOM.xlsx, MEB-Quectel-BG96-v1.2.0.brd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]
